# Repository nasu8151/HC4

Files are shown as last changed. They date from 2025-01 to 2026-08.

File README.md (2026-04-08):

¡¡¡ガバガバEnglish注意報発令中!!!

# Table of Contents
- [Table of Contents](#table-of-contents)
- [Descriptions](#descriptions)
- [Architecture](#architecture)
  - [Overview](#overview)
  - [Block diagram](#block-diagram)
  - [Instructions list](#instructions-list)
- [Software](#software)
- [List of files and folders](#list-of-files-and-folders)

# Descriptions

A 4- or 8-bit CPU made with 74-series logic ICs.

# Manuals

- Hardware manual (JP): [UsersManual_Hardware.md](./UsersManual_Hardware.md)
- Software manual (EN): [UsersManual_Software.md](./UsersManual_Software.md)
- Software manual (JP): [UsersManual_Software_JP.md](./UsersManual_Software_JP.md)

Document roles:

- Hardware manual (JP): block-level architecture, buses, control signals, model differences.
- Software manual (EN/JP): instruction set reference, programming caveats, and LED blink tutorial.

# Architecture
## Overview

HC4 has an 8-bit wide address bus and a 4-bit wide data bus.
All of instructions are 8-bit wide.

## Block diagram

Block diagram of this CPU.

## Instructions list

Please refer to [here](https://github.com/nasu8151/HC4/blob/main/UsersManual_Software.md).

## Schematics and Boards

If you don't have [KiCAD](https://www.kicad.org/), you can use KiCanvas to see our schematics and boards.
* [HC4](https://kicanvas.org/?repo=https%3A%2F%2Fgithub.com%2Fnasu8151%2FHC4%2Ftree%2Fmain%2FHC4_KiCad)
* [HC4<sub>E</sub>](https://kicanvas.org/?repo=https%3A%2F%2Fgithub.com%2Fnasu8151%2FHC4%2Ftree%2Fmain%2FHC4_KiCad_EE)

# Software

## Assembler

The assembler for this CPU can be found [here](https://github.com/nasu8151/hcxasm).
Please see the documents for syntax and other details.

## HC4eROMandRAM

This is a ROM/RAM emulator for HC4<sub>E</sub>.

# List of files and folders

<pre>
.
├─extra
├─HC4eROMandRAM
│  └─inst
├─hc4_asm
│  └─src
│      └─debug_data
├─HC4_KiCad
│  ├─HC4_gbr
│  ├─Library.pretty
│  └─sim
├─HC4_KiCad_EE
│  ├─HC4_KiCad_EE-backups
│  ├─Library.pretty
│  └─production
├─HC_MemoryBoard
│  ├─production
│  └─ThroughHole.pretty
└─verilog
    ├─HC4
    ├─HC4e
    └─HC8
</pre>

* [README.md](https://github.com/nasu8151/HC4) : This file.
* [UsersManual_Software.md](https://github.com/nasu8151/HC4/blob/main/UsersManual_Software.md) : Instruction manual.
* [hc4_asm/](https://github.com/nasu8151/HC4/blob/main/hc4_asm) : [DEPRECATED] : [Use new assembler](https://github.com/nasu8151/hcxasm). An assembler for the HC4 CPU.
* [HC4_KiCad](https://github.com/nasu8151/HC4/blob/main/HC4_KiCad) : Schematics and a board of the HC4.
* [HC4_KiCad_EE](https://github.com/nasu8151/HC4/blob/main/HC4_KiCad_EE) : Schematics and a board of the HC4<sub>E</sub> (Used to be called "HC4 Education Edition").
* [HC_MemoryBoard](https://github.com/nasu8151/HC4/blob/main/HC4_KiCad_EE) : A schematic and a board for SRAM and I/O.
* verilog/
  * [verilog/HC4](https://github.com/nasu8151/HC4/blob/main/verilog/HC4) : Verilog simulation files of the HC4 CPU.
  * [verilog/HC8](https://github.com/nasu8151/blob/main/HC4/verilog/HC8) : Verilog simulation files of the HC8 CPU.
  * [verilog/HC4e](https://github.com/nasu8151/blob/main/HC4/verilog/HC8) : Verilog simulation files of the HC4e CPU.

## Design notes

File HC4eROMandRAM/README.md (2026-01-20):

# HC4eROMandRAM

これは、HC4<sub>E</sub>ボード用のROM/RAMを担当するプログラムです。
開発には、[PlatformIO](https://platformio.org/)を推奨しますが、書き込みはArduino IDEでも可能です。

## 書き込み方法(PlatformIO)

まず、VSCodeをダウンロードしてインストールしてください。そして、拡張機能の[PlatformIO](https://platformio.org/)を導入してください。\
つづいて、[HC4eROMandRAM.code-workspace](HC4eROMandRAM.code-workspace)を開き、ワークスペースに入ります。

### SerialUPDIの場合

SerialUPDIライタの作り方は、[この辺](https://nemuisan.blog.bai.ne.jp/?eid=239957)や[ここ](https://github.com/SpenceKonde/AVR-Guidance/blob/master/UPDI/jtag2updi.md)を参照してください。

## 書き込み方法(Arduino IDE)

まず、Arduino IDEをダウンロードし、インストールします。そして、[HC4eROMandRAM.ino](HC4eROMandRAM.ino)を開き、ツールバーからFile->Preferencies...(ファイル->基本設定)を開きます。\
そこにある、Additional Board Manager URLs(追加のボードマネージャーURL)を開き、```https://mcudude.github.io/MegaCoreX/package_MCUdude_MegaCoreX_index.json```を追加してください。\
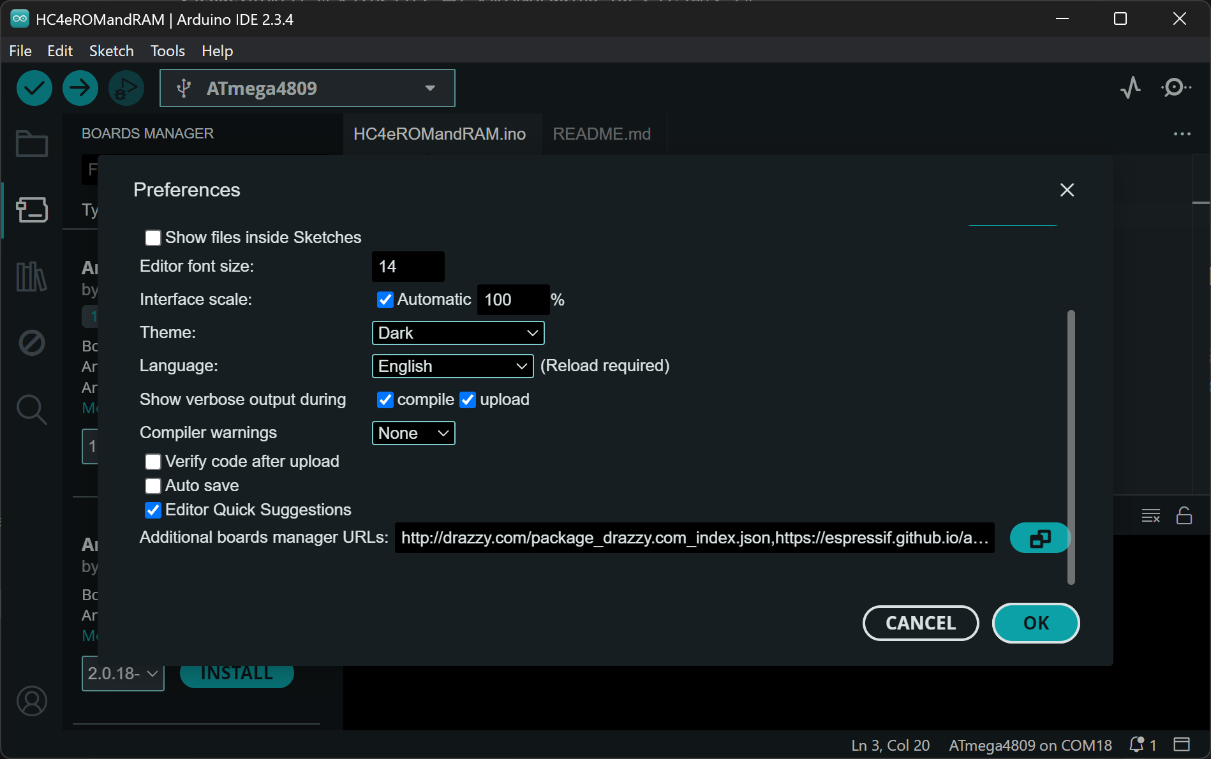
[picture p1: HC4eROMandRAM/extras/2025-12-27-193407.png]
Additional Board Manager URLs

すると、サイドバーのボードマネージャーから```MegaCoreX```が落とせるようになるので、検索してインストールしてください。

### SerialUPDIの場合

SerialUPDIライタの作り方は、[この辺](https://nemuisan.blog.bai.ne.jp/?eid=239957)や[ここ](https://github.com/SpenceKonde/AVR-Guidance/blob/master/UPDI/jtag2updi.md)を参照してください。\

SerialUPDIライタをパソコンにつなぎ、またUPDI端子とGND、必要に応じて電源をHC4<sub>E</sub>ボードにつなぎます。\
つづいて、Arduino IDEのTools下の設定を以下のように変更してください。\
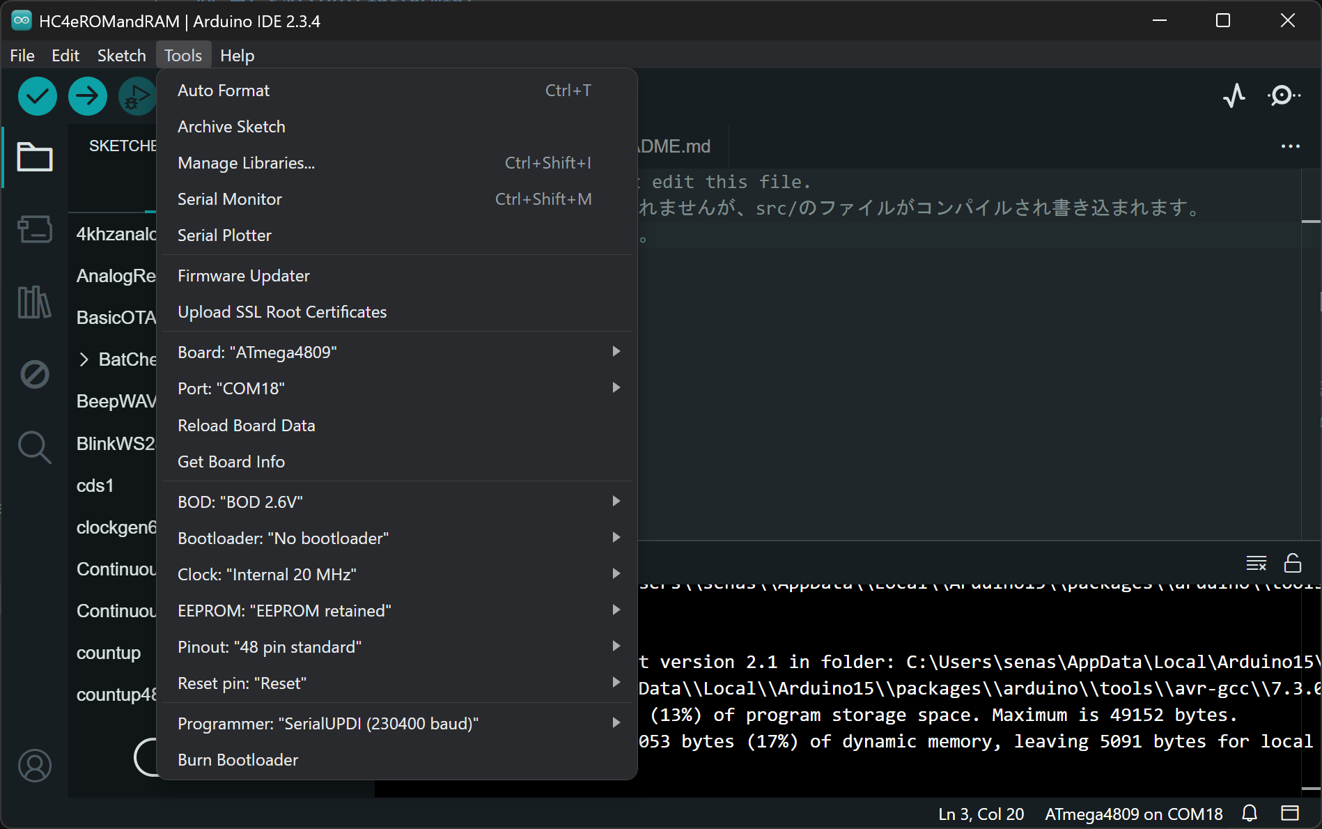
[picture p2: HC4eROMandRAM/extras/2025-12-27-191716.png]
\
COMポートは適宜読み替えてください。\
そうしたら、普通の書き込みボタンではなく、Sketch->Upload Using Programmerを押すか、Ctrl+Shift+Uを押して書き込んでください。

### jtag2updiの場合

まず、jtag2updiスケッチの書き込まれたArduino(Uno R3/Nano)を用意し、[公式リポジトリ](https://github.com/ElTangas/jtag2updi)や[この辺](https://burariweb.info/electronic-work/arduino-updi-writing-method.html)を参考にHC4<sub>E</sub>ボードとつなぎます。\
つづいて、Arduino IDEのTools下の設定を以下のように変更してください。\
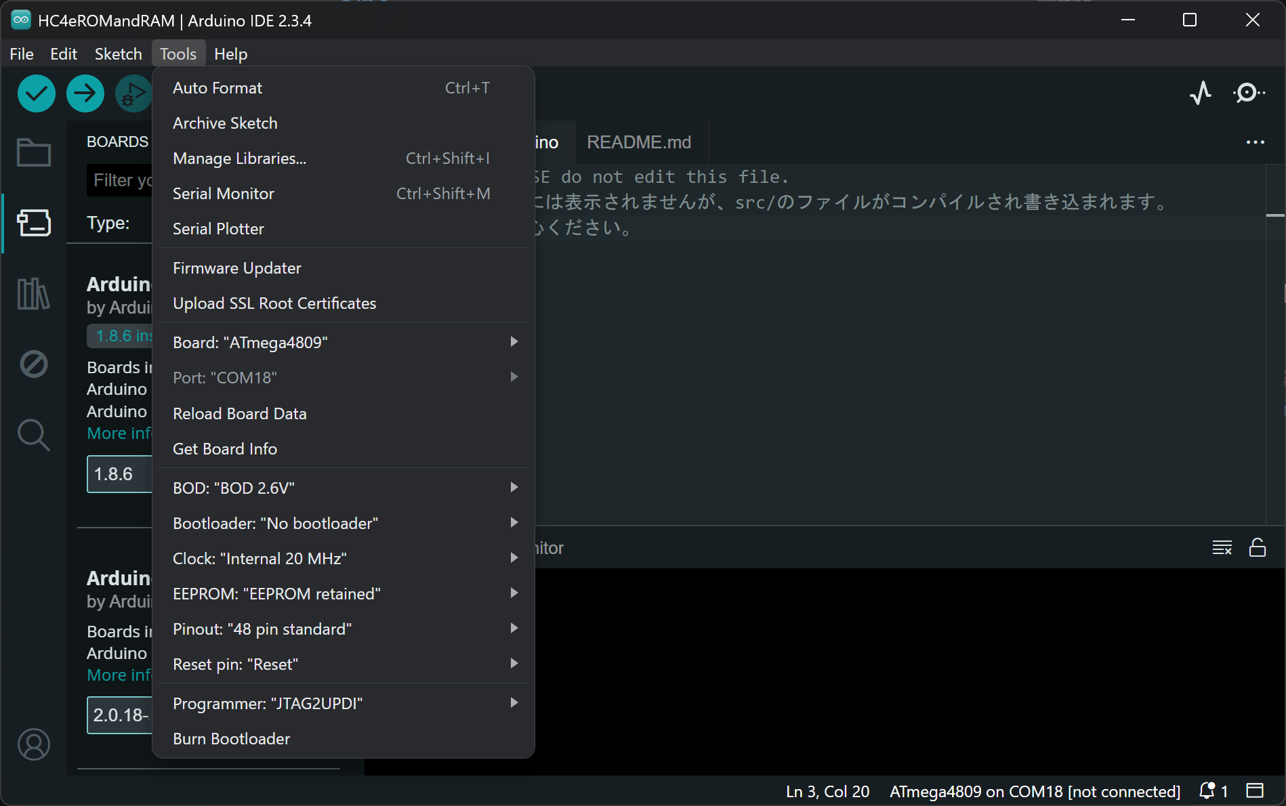
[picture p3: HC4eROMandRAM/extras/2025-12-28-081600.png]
\
そうしたら、普通の書き込みボタンではなく、Sketch->Upload Using Programmerを押すか、Ctrl+Shift+Uを押して書き込んでください。

## 動作確認

[Tera Term](https://teratermproject.github.io/)などのターミナルソフトを使用します。ここでは、Tera Termを使用しているものとします。\
Tera Termを開くと、接続先を選ぶ画面が出ます。そこの、シリアルにチェックを入れ、UPDIライタではなく、**HC4<sub>E</sub>のシリアルアダプタ**を選んでください。もしわからなければ、UPDIライタを外してみてください。\
設定->シリアルポートを選び、スピードを```115200```に設定します。つづいて、設定->端末を選び改行コードを送信、受信ともに```LF```に設定してください。\
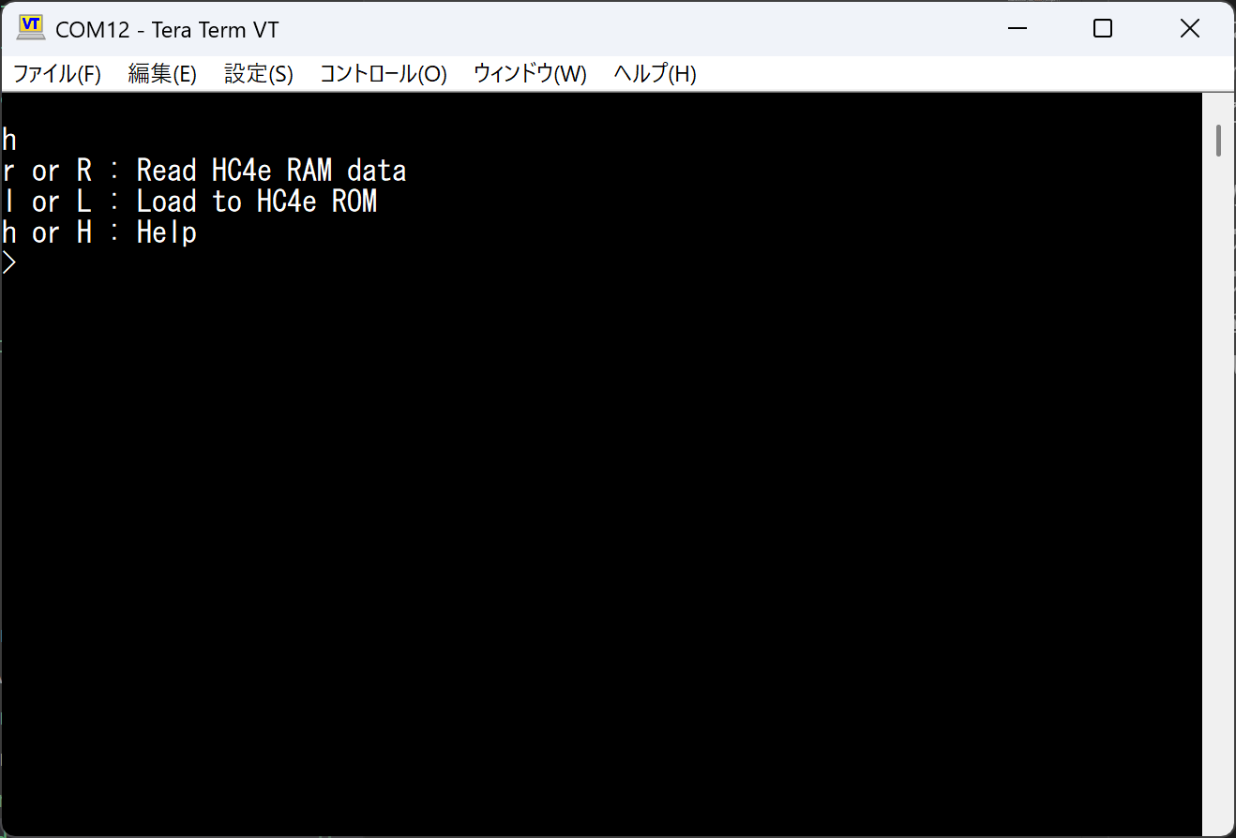
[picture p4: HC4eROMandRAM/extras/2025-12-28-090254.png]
help command
黒い画面で```h```をタイプし改行すると、以下の表示が出れば成功です。
つづいて```l```をタイプし改行したのちプログラムのintel hexのデータを右クリックか```Alt+V```で貼り付けて、そのプログラムが正しく動けば、完全に成功しています。
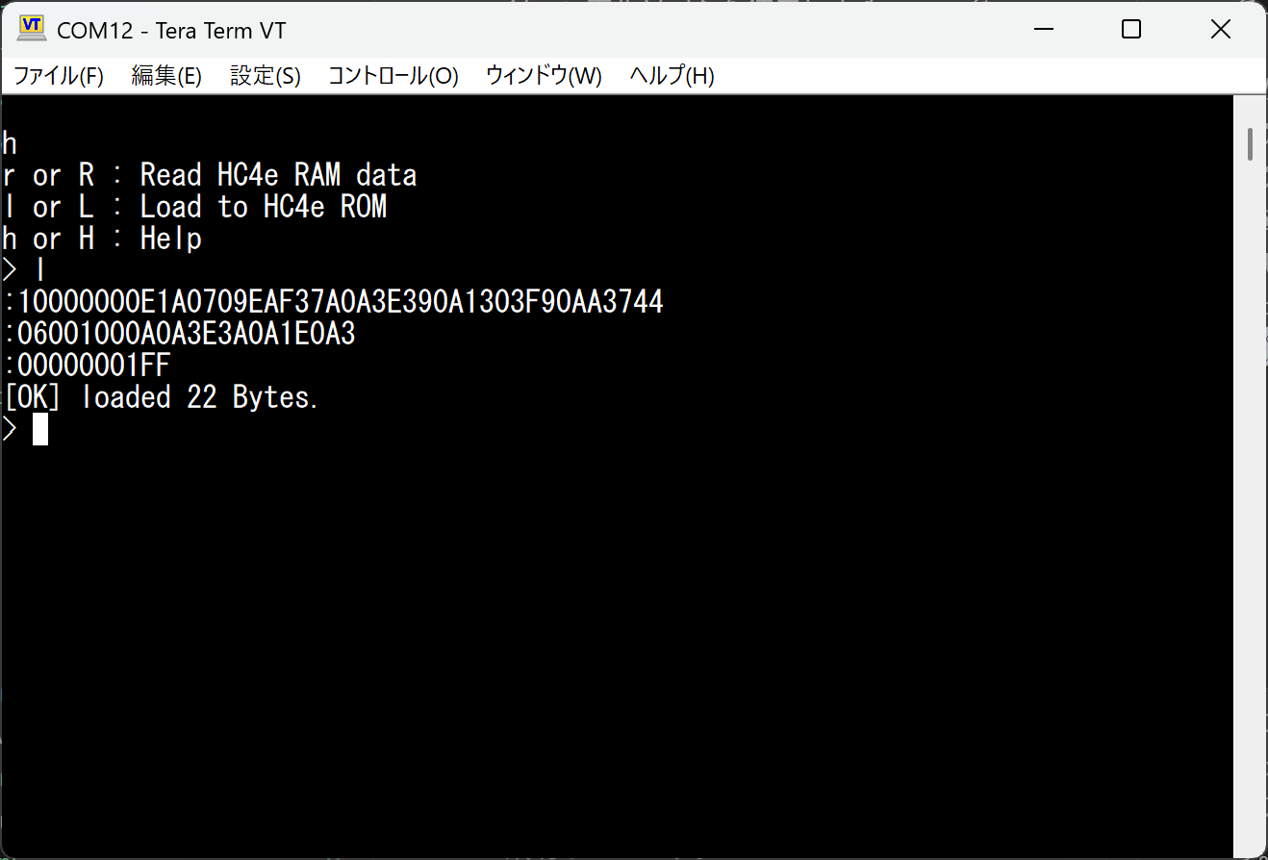
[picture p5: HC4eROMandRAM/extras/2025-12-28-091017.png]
succeed


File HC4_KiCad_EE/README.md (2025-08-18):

Schematics and board of HC4<sub>E</sub> (E means "for Education").

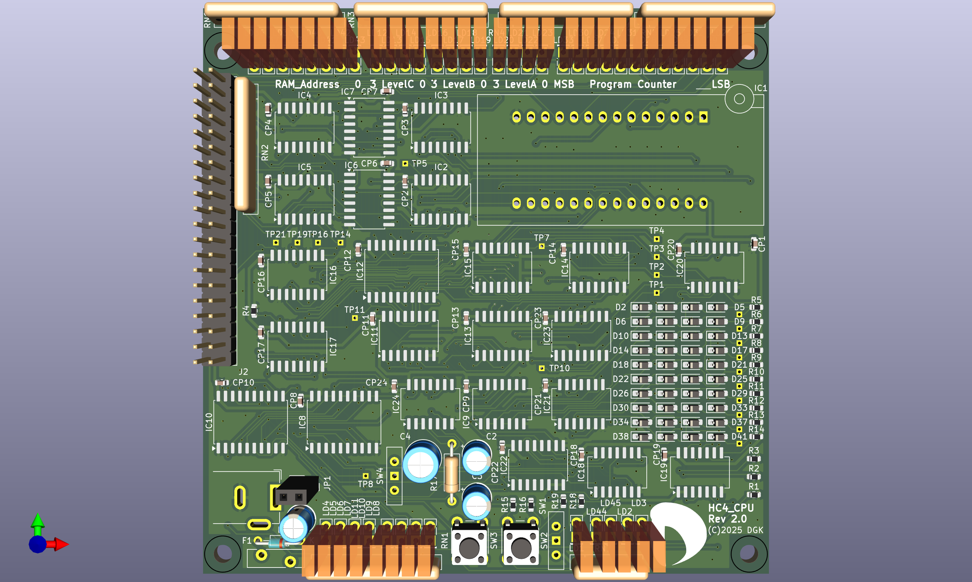
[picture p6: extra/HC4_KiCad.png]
Picture of the Board


BOM:
[Bill of materials](https://github.com/nasu8151/HC4/blob/main/HC4_KiCad/BOM_HC4.md)

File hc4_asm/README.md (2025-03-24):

# HC4 ASSEMBLER
## Syntax
> [!NOTE]
> IF you want to know function about assembly, please read [UsersManual_Software.md](https://github.com/nasu8151/HC4/blob/main/UsersManual_Software.md).

### Basic syntax
Let's get right to the explanation, but first, we tell you one.
On HC4 assembler, comments are represented by `;`. characters on the line after `;` are ignored during assembly.
```assembly
<Instruction>
<Instruction> <reg> ;reg means a 4-bit wide register. In the program, it is represented by r0 to r15 in program.
<Instruction> <imm> ;imm means 4 bits wide immediate data. In a program, it is represented as binary from #0000 to #1111.
<Instruction> <flg> ;flg means flag register.

;Addressing option is represented [AB] for SC or [ABC] for JP.
;[AB] means indirect addressing of stack level A and B. MSB is level B.
;[ABC] means indirect addressing of stack level A, B and C. MSB is level C.
<Instruction> <adr>       ; for load and store instructions
<Instruction> <flg> <adr> ; for jump instructions
```

### Pseudo-instruction

Currently not implemented.

## Command line options

* ```-o``` :
  * Specifies output file.

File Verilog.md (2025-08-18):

> [!IMPORTANT]
> The English version was EXCALIBURED. Wait until it has been repaired.
# 本編
## 🎯 HC4 CPU Verilog 解説

## 📚 1. 概要
* `hc4` モジュールは、4ビットスタックベースの簡易 CPU（HC4）のトップモジュールです。
* 以下に、部分ごとに分解して詳細に説明します。

---

## 📡 2. モジュール宣言と入出力

```verilog
module hc4 (
    input wire clk,                     // クロック信号
    input wire nReset,                  // 非同期リセット（0でリセット、1で通常動作）
    output wire [11:0] pc_out,          // プログラムカウンタの出力
    output wire [3:0] stackA_out,       // スタックレベルAの出力
    output wire [3:0] stackB_out,       // スタックレベルBの出力
    output wire [3:0] stackC_out,       // スタックレベルCの出力
    output wire [7:0] address_bus,      // アドレスバスの出力
    inout  wire [3:0] data_bus,         // データバス（入出力）
    output wire nRAM_RD,                // RAM 読み出し制御（アクティブ Low）
    output wire nRAM_WR                 // RAM 書き込み制御（アクティブ Low）
);
```

### ✅ ポイント
* `clk`：クロック信号
* `nReset`：リセット信号（アクティブ Low）  
    * 0 でリセット状態、1 で通常動作。
* `pc_out`：プログラムカウンタ（PC）の出力。
* `stackA_out`, `stackB_out`, `stackC_out`：スタックの各レベルの値を外部に出力。
* `address_bus`：メモリアドレスの出力（8ビット）。
* `data_bus`：4ビット幅のデータバス、読み書き両方に対応（inout）。
* `nRAM_RD`：RAM 読み出し制御信号（Low でアクティブ）。
* `nRAM_WR`：RAM 書き込み制御信号（Low でアクティブ）。

---

## 📝 3. レジスタとメモリの定義

```verilog
    reg [3:0] level_A;     // スタック レベル A
    reg [3:0] level_B;     // スタック レベル B
    reg [3:0] level_C;     // スタック レベル C
    reg [11:0] pc;         // プログラムカウンタ（PC）

    reg [7:0] rom [0:4095]; // 8ビット幅の命令ROM、4096命令分
```

### ✅ ポイント
* `level_A` ～ `level_C`：スタックレジスタ。
* `pc`：プログラムカウンタ（命令フェッチ用）。
* `rom`：命令を格納するメモリ（プログラムROM）。
* `$readmemh("./jmptest.hex", rom);` でROMに `jmptest.hex` からデータを読み込む。

---

## 🔢 4. 命令と制御信号の定義

```verilog
    wire [7:0] instruction;         // 現在の命令
    wire sub;                       // ALU の減算/加算制御信号
    wire [3:0] alu_result;          // ALU の出力結果
    wire carry;                     // キャリーフラグ
    reg  carry_flg;                 // キャリーフラグ保持
    reg  zero_flg;                  // ゼロフラグ保持
```

### ✅ ポイント
* `instruction`：現在の命令
* `sub`：ALU が減算モードか加算モードかを指定（1 なら減算、0 なら加算）。
* `alu_result`：ALU からの結果。
* `carry`：ALU のキャリーフラグ（繰り上がりや借り）。
* `carry_flg`：キャリーフラグの保持用レジスタ。
* `zero_flg`：ゼロフラグの保持用レジスタ。

---

## 📡 5. 命令読み込み・PC出力

```verilog
    assign instruction = rom[pc];
    assign pc_out = pc;
    assign stackA_out = level_A;
    assign stackB_out = level_B;
    assign stackC_out = level_C;
```

### ✅ ポイント
* `instruction`：プログラムカウンタ `pc` の位置から命令を読み込み。
* `pc_out`：プログラムカウンタを外部に出力。
* `stackA_out`, `stackB_out`, `stackC_out`：各スタックレベルの値を外部に出力。

---

## 🛠️ 6. ALU インスタンス化

```verilog
    alu ALU (
        .in_A (level_A),
        .in_B (level_B),
        .sel_in (instruction[6:4]),
        .carry_in (sub),
        .out (alu_result),
        .carry_out (carry)
    );
```

### ✅ ポイント
* `ALU` モジュールのインスタンス化。
* `in_A` と `in_B` にスタックレベル A, B を入力。
* `sel_in` に命令の `opcode` を入力。
* `carry_in` に `sub` 信号を入力。
* `alu_result` に演算結果を出力。
* `carry` にキャリーフラグを出力。

---

## 🧠 7. アドレスマルチプレクサ（ADDRESS_MUX）

```verilog
    function [7:0] ADDRESS_MUX(input [7:0] instruction, input [3:0] level_A, input [3:0] level_B);
        if (instruction[6:4] == 3'b000) begin  // if addressing mode is [AB]
            ADDRESS_MUX[3:0] = level_A;
            ADDRESS_MUX[7:4] = level_B;
        end else begin                         // if addressing mode is not [AB] (r, i)
            ADDRESS_MUX[7:4] = 4'h0;
            ADDRESS_MUX[3:0] = instruction[3:0];
        end
    endfunction
    assign address_bus = ADDRESS_MUX(instruction[7:0], level_A, level_B);
```

### ✅ ポイント
* `ADDRESS_MUX`：アドレスの選択
    * アドレッシングモード `[AB]` の場合：`level_A` と `level_B` からアドレス生成。
    * 即値やレジスタの場合：`instruction[3:0]` をアドレスの下位4ビットに設定。

---

## 🔁 8. プログラムカウンタ更新（NEXT_PC）

```verilog
    function [11:0] NEXT_PC(input [7:0] instruction, input [11:0] pc, input [3:0] level_A, input [3:0] level_B, input [3:0] level_C, input C_flag, input Z_flag);
        reg nJMP;
        if (instruction[7:5] == 3'b111) begin // if current instruction is Jump
            case (instruction[2:0])
                3'b000: NEXT_PC = {level_C, level_B, level_A};  // JP
                3'b001: NEXT_PC = pc + 1;                       // NP
                3'b010: begin                                  // JC
                    if (C_flag == 1) NEXT_PC = {level_C, level_B, level_A};
                    else             NEXT_PC = pc + 1;
                end
                3'b011: begin                                  // JNC
                    if (C_flag == 0) NEXT_PC = {level_C, level_B, level_A};
                    else             NEXT_PC = pc + 1;
                end
                3'b100: begin                                  // JZ
                    if (Z_flag == 1) NEXT_PC = {level_C, level_B, level_A};
                    else             NEXT_PC = pc + 1;
                end
                3'b101: begin                                  // JNZ
                    if (Z_flag == 0) NEXT_PC = {level_C, level_B, level_A};
                    else             NEXT_PC = pc + 1;
                end
                default:  NEXT_PC = pc + 1;
            endcase
        end else begin
            NEXT_PC = pc + 1;
        end
    endfunction
```

### ✅ ポイント
* `NEXT_PC`：ジャンプ命令の処理
    * `JP`：スタックの `CBA` からジャンプ。
    * `NP`：次の命令へ進む。
    * `JC`/`JNC`：キャリーフラグで条件付きジャンプ。
    * `JZ`/`JNZ`：ゼロフラグで条件付きジャンプ。
    * デフォルトは `pc + 1` で次の命令。

---

## 🔀 9. バス制御（BUS_CTRL）

```verilog
    function [3:0] BUS_CTRL (input [7:0] instruction, input [3:0] alu_result, input [3:0] level_C);
        casez (instruction[7:5])
            3'b000:  BUS_CTRL = level_C;          // SC
            3'b0??:  BUS_CTRL = alu_result;       // ALU instructions (include SA)
            3'b100:  BUS_CTRL = 4'bz;             // LD [AB] or LD r (RAM)
            3'b101:  BUS_CTRL = instruction[3:0]; // LD i
            default: BUS_CTRL = 4'bx;             // JP doesn't use data bus
        endcase
    endfunction
    assign data_bus = BUS_CTRL(instruction, alu_result, level_C);
```

### ✅ ポイント
* `BUS_CTRL`：バス制御
    * `SC`：`level_C` をデータバスに出力。
    * `ALU` 命令：`alu_result` をデータバスに出力。
    * `LD [AB]` / `LD r`：RAM からの読み込み → 高インピーダンス。
    * `LD i`：即値をバスに出力。

---

## 🔁 10. メイン処理（always ブロック）

```verilog
    always @(posedge clk or negedge nReset) begin
        if (nReset == 0) begin
            pc <= 12'b0;
            carry_flg <= 1'b0;
            zero_flg <= 1'b0;
            level_A <= 4'b0;
        end else begin
            casez (instruction[7:6])
                2'b0?: begin // if current instruction is an instruction which stores in the memory or registers
                    zero_flg  <= data_bus == 4'b0 ? 1 : 0;
                    carry_flg <= instruction[7:5] == 3'b001 ? carry : carry_flg;
                end 
                2'b10: begin
                    level_A <= data_bus;
                    level_B <= level_A;
                    level_C <= level_B;
                end
                2'b11: begin
                    // nothing to write here
                end
            endcase
            pc <= NEXT_PC(instruction, pc, level_A, level_B, level_C, carry_flg, zero_flg);
        end
    end
```

### ✅ ポイント
* `nReset == 0`：リセット時に初期化。
* 命令の `opcode` によって以下の動作
    * `0x`：メモリやレジスタに書き込み。
        * ゼロフラグ、キャリーフラグ更新。
    * `10`：スタックのシフト更新。
        * `level_A` → `level_B` → `level_C` へプッシュ。
    * `11`：ジャンプのみ、何も書き込みなし。

---

## 🎉 11. まとめ
* HC4 は 4 ビットスタックベースの CPU で、ジャンプ、スタック操作、ALU 演算などの基本的な命令を実行可能。
* Verilog での記述はモジュール化され、ALU、ROM 読み込み、バス制御などが含まれている。

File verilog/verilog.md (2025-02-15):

# Verilog Simulation
使い方がわかったので採用
## 記述ルール(仮)
* 負論理の信号は先頭に`n`をつける   
* 変数の語頭は必ず小文字

HC4/ is a 4-bit CPU.
HC8/ is an 8-bit CPU.

Commands to compile verilog simulation files:

```
cd ./verilog/hc4/
iverilog -o hc4_tb.out -s hc4_tb -g 2005-sv ./hc4.v ./hc4_tb.v
vvp ./hc4_tb.out
gtkwave ./hc4_tb.vcd
```

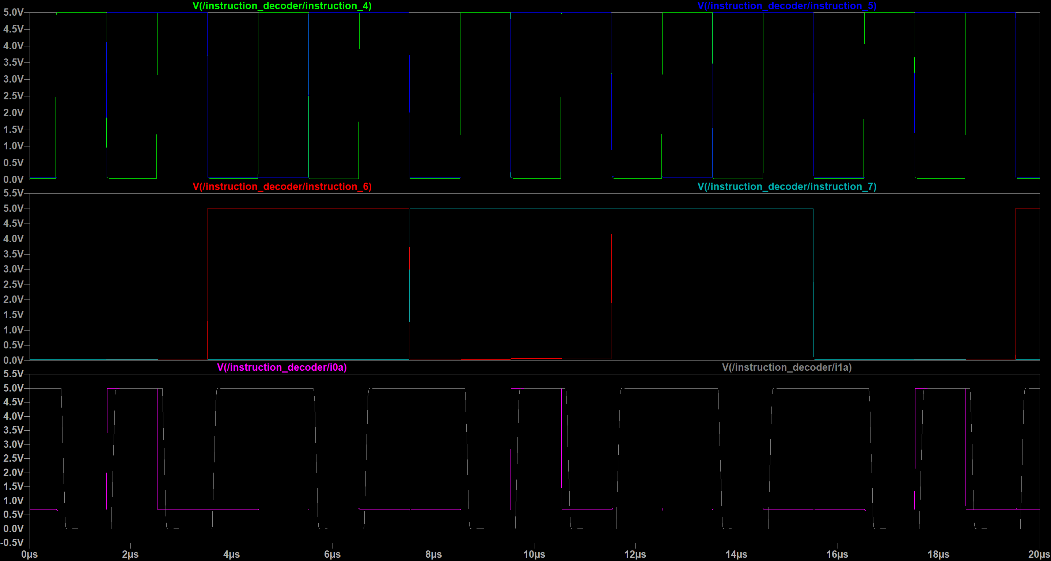
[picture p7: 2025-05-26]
extra/spice4.png

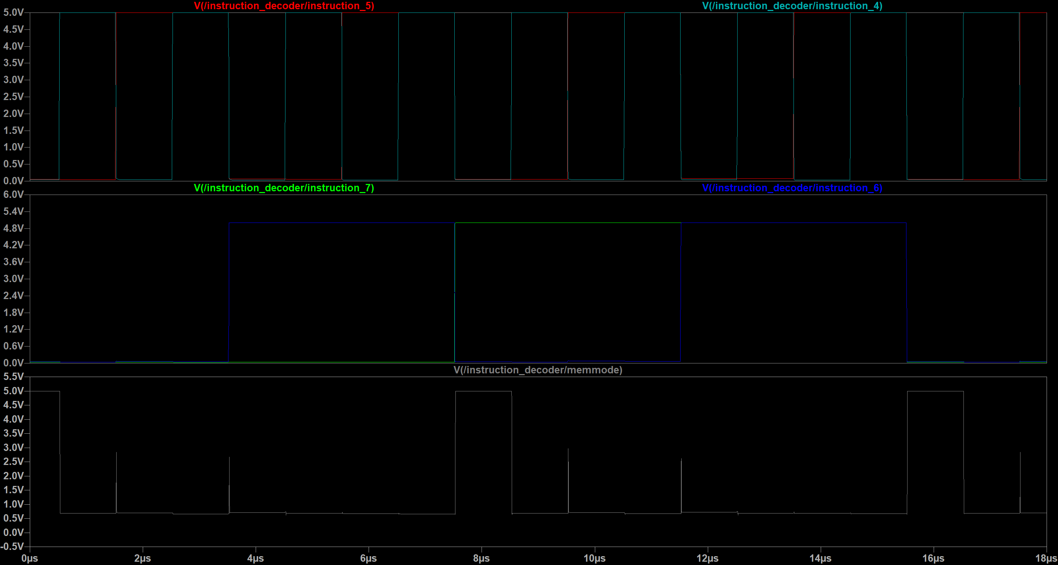
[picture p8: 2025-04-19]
extra/spice2.png

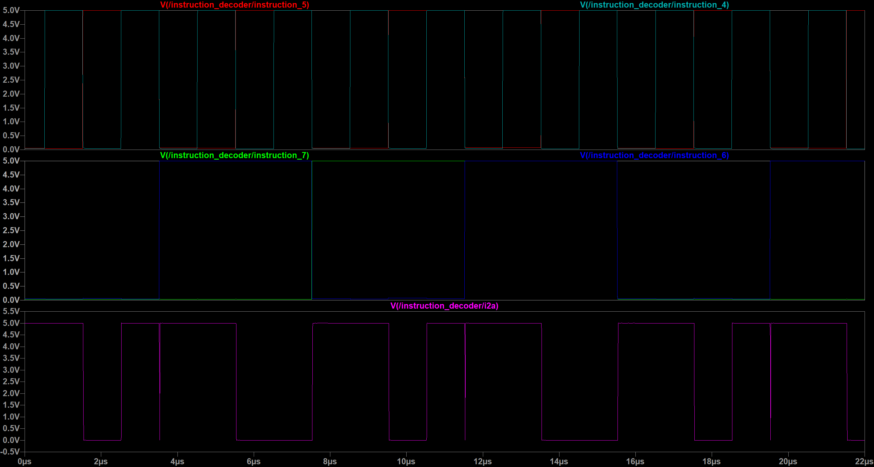
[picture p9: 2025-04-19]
extra/spice5.png

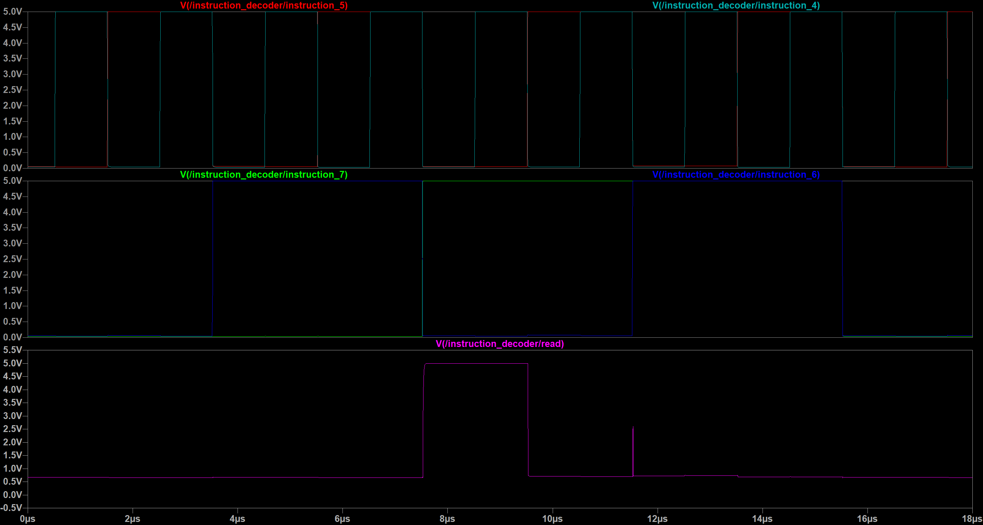
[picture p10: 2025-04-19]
extra/spice7.png

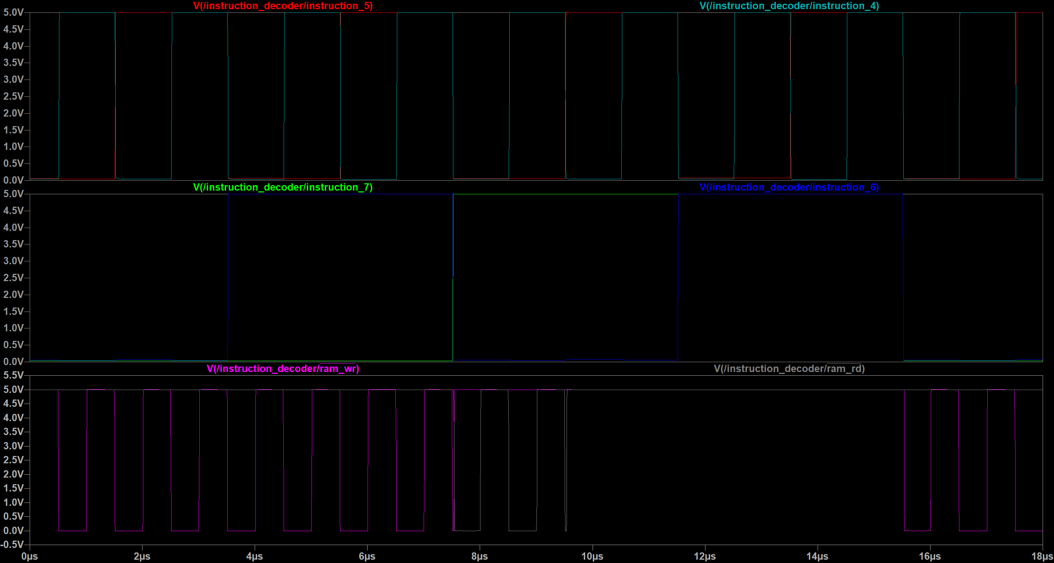
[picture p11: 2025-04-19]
extra/spice8.png

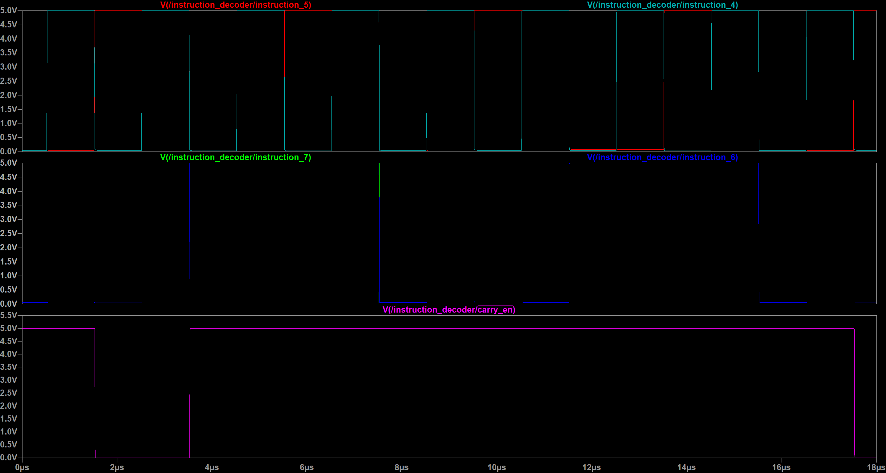
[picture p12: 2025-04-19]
extra/spice3.png

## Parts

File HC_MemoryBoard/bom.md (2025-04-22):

# Bill of Materials

| Reference | Value | Qty |
| --- | --- | --- |
| CP1-CP5 | Ceramic Capacitor: 0.1u  | 5 |
| IC1 | SRAM: 62256 or equipment | 1 |
| IC2 | 74HC30 | 1 |
| IC3 | 74HC138 | 1 |
| IC4 | 74HC32 | 1 |
| IC5 | 74HC541 | 1 |
| J1,J4 | Pinheader: 2x20 | 2 |
| J2,J6,J7,JP2 | Pinheader: 1x02 | 4 |
| J3,J5 | Pinheader: 01x08_Pin | 2 |
| JP1 | Pinheader: 02x17 | 1 |
| RN1 | R_Array 10k SIP9 | 1 |
| SW1 | SW_DIP_x08 | 1 |
| TP1 | PinHeader_1x01 | 1 |

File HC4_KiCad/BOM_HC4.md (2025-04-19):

| Reference | Value | Qty | Remarks |
| --- | --- | --- | --- |
| C1 | 100u | 1 | |
| C2,C3 | 10u | 2 | |
| C4 | 10u(Socket) | 1 | Unipolar |
| CP1-CP24 | 0.1u | 24  | 1608 |
| D1 | 5.6V | 1 | |
| D2-D41 | D | 40  | SOD-323 Package |
| F1 | Polyfuse | 1 | |
| IC1 | ROM | 1 | ZIF Socket |
| IC2,IC3,IC4,IC5 | 74HC153 | 4 | Use SOP type |
| IC6 | 74HC283 | 1 | Use SOP type |
| IC7,IC16,IC17 | 74HC257 | 3 | Use SOP type |
| IC8 | 74HC244 | 1 | Use SOP type |
| IC9 | 74HC4002 | 1 | Use SOP type |
| IC10 | 74HC374 | 1 | Use SOP type |
| IC11,IC13,IC14,IC15 | 74HC161 | 4 | Use SOP type |
| IC12 | 74HC377 | 1 | Use SOP type |
| IC18 | 74HC74 | 1 | Use SOP type |
| IC19 | 74HC32 | 1 | Use SOP type |
| IC20 | 74HC04 | 1 | Use SOP type |
| IC21 | 74HC00 | 1 | Use SOP type |
| IC22 | 74HC4053 | 1 | Use SOP type |
| IC23 | 74HC151 | 1 | Use SOP type |
| IC24 | 74HC14 | 1 | Use SOP type |
| J1 | Power | 1 | DC Jack |
| J2 | Expantion_Connector | 1 | 2x20pin |
| JP1 | Blink_EN | 1 | Use slide swich or jumper pin |
| LD1 | POWER_LED | 1 | LED |
| LD2-LD45 | LED | 44  | 2x5mm Rectanglar |
| R1,R2,R3 | 1k | 3 | 1608 |
| R4-R15 | 10k | 12  | 1608 |
| R16 | 100k | 1 | 1608 |
| R17 | Socket | 1 | |
| R18,R19 | 100 | 2 | 1608 |
| RN1,RN3,RN4,RN5,RN6 | 1k | 5 | SIP8 |
| RN2 | 10k | 1 | SIP8 |
| RN7 | 1k | 1 | SIP5 |
| SW1 | Bus_Open | 1 | Use slide swich or jumper pin |
| SW2,SW3 | SW_Push | 2 | |
| SW4 | SW_SPDT | 1 | Use slide swich or jumper pin |

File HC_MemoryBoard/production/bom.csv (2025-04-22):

Designator | Footprint | Quantity | Value | LCSC Part #
CP1, CP2, CP3, CP4, CP5 | C_Disc_D3.0mm_W1.6mm_P2.50mm | 5 | 0.1u
IC1 | DIP-28_W15.24mm | 1 | HM62256BLP
IC2 | DIP-14_W7.62mm | 1 | 74HC30
IC3 | DIP-16_W7.62mm | 1 | 74HC138
IC4 | DIP-14_W7.62mm | 1 | 74HC32
IC5 | DIP-20_W7.62mm | 1 | 74HC541
J1, J4 | PinHeader_2x20_P2.54mm_Vertical | 2 | Expantion_Connector
J2, J6, J7 | PinHeader_1x02_P2.54mm_Vertical | 3 | Conn_01x02_Pin
J3, J5 | PinHeader_1x08_P2.54mm_Vertical | 2 | Conn_01x08_Pin
JP1 | PinHeader_2x17_P2.54mm_Vertical | 1 | Conn_02x17_Counter_Clockwise
JP2 | PinHeader_1x02_P2.54mm_Vertical | 1 | Jumper_2_Bridged
RN1 | R_Array_SIP9 | 1 | 10k
SW1 | SW_DIP_SPSTx08_Slide_9.78x22.5mm_W7.62mm_P2.54mm | 1 | SW_DIP_x08
TP1 | PinHeader_1x01_P2.54mm_Vertical | 1 | ~{IRQ}

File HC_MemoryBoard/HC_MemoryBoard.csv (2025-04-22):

Reference | Value | Footprint | Datasheet | Qty | DNP | Exclude from BOM | Exclude from Board
CP1,CP2,CP3,CP4,CP5 | 0.1u | Capacitor_THT:C_Disc_D3.0mm_W1.6mm_P2.50mm | ~ | 5
IC1 | HM62256BLP | Package_DIP:DIP-28_W15.24mm | https://web.mit.edu/6.115/www/document/62256.pdf | 1
IC2 | 74HC30 | Package_DIP:DIP-14_W7.62mm | https://www.ti.com/lit/ds/symlink/cd74hc30.pdf?ts=1704693560763 | 1
IC3 | 74HC138 | Package_DIP:DIP-16_W7.62mm | http://www.ti.com/lit/ds/symlink/cd74hc238.pdf | 1
IC4 | 74HC32 | Package_DIP:DIP-14_W7.62mm | http://www.ti.com/lit/gpn/sn74LS32 | 1
IC5 | 74HC541 | Package_DIP:DIP-20_W7.62mm | https://toshiba.semicon-storage.com/info/TC74HC541AP_datasheet_ja_20140301.pdf?did=16392&prodName=TC74HC541AP | 1
J1,J4 | Expantion_Connector | Connector_PinHeader_2.54mm:PinHeader_2x20_P2.54mm_Vertical | ~ | 2
J2,J6,J7 | Conn_01x02_Pin | Connector_PinHeader_2.54mm:PinHeader_1x02_P2.54mm_Vertical | ~ | 3
J3,J5 | Conn_01x08_Pin | Connector_PinHeader_2.54mm:PinHeader_1x08_P2.54mm_Vertical | ~ | 2
JP1 | Conn_02x17_Counter_Clockwise | Connector_PinHeader_2.54mm:PinHeader_2x17_P2.54mm_Vertical | ~ | 1
JP2 | Jumper_2_Bridged | Connector_PinHeader_2.54mm:PinHeader_1x02_P2.54mm_Vertical | ~ | 1
RN1 | 10k | Resistor_THT:R_Array_SIP9 | http://www.vishay.com/docs/31509/csc.pdf | 1
SW1 | SW_DIP_x08 | Button_Switch_THT:SW_DIP_SPSTx08_Slide_9.78x22.5mm_W7.62mm_P2.54mm | ~ | 1
TP1 | ~{IRQ} | Connector_PinHeader_2.54mm:PinHeader_1x01_P2.54mm_Vertical | ~ | 1

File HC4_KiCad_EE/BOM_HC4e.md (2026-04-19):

| Reference | Value | Qty | Remarks |
|---|---|-----|---|
| C1 | 100u | 1 | |
| C2,C3,CP1-15 | 0.1u | 17  | SMT 1608 |
| C4,C5 | 10u | 2 | |
| C6 | 1u | 1 | Use unipolar type |
| D1 | 7-Segment | 1 | C-551SRD or equipment |
| D2 | Schottky | 1 | Switching diode in SOD-323 package |
| IC1,IC12 | 74HC00 | 2 | Use SOP package (D or *F) |
| IC2 | 74HC283 | 1 | Use SOP package (D or *F) |
| IC3,IC4 | 74HC253 | 2 | Use SOP package (D or *F) |
| IC5 | 74HC244 | 1 | Use TSSOP package (PW) |
| IC6,IC8 | 74HC377 | 2 | Use TSSOP package (PW) |
| IC7 | 74HC4511 | 1 | Use SOP package (D or *F) |
| IC9,IC10 | 74HC161 | 2 | Use SOP package (D or *F) |
| IC11 | 74HC02 | 1 | Use SOP package (D or *F) |
| IC13 | 74HC4053 | 1 | Use SOP package (D or *F) |
| IC14 | 74HC74 | 1 | Use SOP package (D or *F) |
| IC15 | 74HC14 | 1 | Use SOP package (D or *F) |
| J1,J2 | Port | 2 | Pinsocket_1x4 |
| J3 | UPDI_and_Debug | 1 | Pinheader_2x3 |
| J4 | Conn_02x04_Odd_Even | 1 | USB-UART |
| J5 | Expantion | 1 | Pinheader_2x5 |
| LD1-29 | LED | 29  | 2x5mm Rectangler |
| LD30-45 | Chip | 16  | SMT 1608 |
| LD46 | CLK | 1 | D5mm, Yellow |
| LD47 | RESET | 1 | D5mm, Red |
| R1 | 1k | 1 | SMT 1608 |
| R2 | 10k | 1 | SMT 1608 |
| R3 | 100k | 1 | SMT 1608 |
| R4 | 390k | 1 | SMT 1608 |
| R5 | 390 | 1 | SMT 1608 |
| R6,R7 | 100 | 2 | SMT 1608 |
| RN1 | 10k | 1 | Resistor array SMT 3216 |
| RN2-15 | 1k | 14  | Resistor array SMT 3216 |
| SW1 | SW_DIP_x04 | 1 | |
| SW2,SW3,SW4  | SW_Push | 3 | |
| SW5,SW6 | SW_SPDT | 2 | |
| U1 | ATmega4809-AU | 1 | or AVR32DB48 |

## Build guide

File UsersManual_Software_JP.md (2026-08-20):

# HC4 ユーザーズマニュアル ソフトウェア編

- [HC4 ユーザーズマニュアル ソフトウェア編](#hc4-ユーザーズマニュアル-ソフトウェア編)
  - [表の読み方](#表の読み方)
  - [命令テーブル](#命令テーブル)
    - [HC4](#hc4)
    - [HC4E](#hc4e)
    - [HC8](#hc8)
    - [総合](#総合)
  - [命令詳細](#命令詳細)
    - [論理演算・算術演算](#論理演算算術演算)
      - [`SU`](#su)
      - [`AD`](#ad)
      - [`XR`](#xr)
      - [`OR`](#or)
      - [`AN`](#an)
    - [レジスタ・メモリアクセス](#レジスタメモリアクセス)
      - [`SM`](#sm)
      - [`SC r`](#sc-r)
      - [`SA r`](#sa-r)
      - [`LM`](#lm)
      - [`LD`](#ld)
      - [`LI`](#li)
    - [システム制御](#システム制御)
      - [`JP`, `NP`](#jp-np)
  - [注意すべき点](#注意すべき点)
    - [HC4E の注意](#hc4e-の注意)
    - [SA r / SC r / SM](#sa-r--sc-r--sm)
    - [LD r / LI #i / LM](#ld-r--li-i--lm)
    - [JP 系 / NP](#jp-系--np)
  - [チュートリアル: LED点滅（lchika.asm）](#チュートリアル-led点滅lchikaasm)
  - [トラブルシューティング](#トラブルシューティング)

## 表の読み方

HC4シリーズの命令幅は 8 bit です。

- `r`: 4 bit レジスタ番号（`r0` から `r15`）
- `A`, `B`, `C`: スタックA/B/C
- `#i`: 4 bit 即値
- `[AB]`: スタック A/B を連結した間接アドレス（MSB は B）
- `[ABC]`: スタック A/B/C を連結した間接アドレス（MSB は C）
- `PC`: Program Counter

（Reserved）は未定義命令です。動作は保証されません。

## 命令テーブル

### HC4

| bit 5-4→<br>7-6↓ | 00 | 01 | 10 | 11 |
| --- | --- | --- | --- | --- |
| 00 | `SM` | `SC r` | `SU r` | `AD r` |
| 01 | `XR r` | `OR r` | `AN r` | `SA r` |
| 10 | `LM` | `LD r` | `LI #` | (Reserved) |
| 11 | (Reserved) | (Reserved) | `JP flag`, `NP` | (Reserved) |

### HC4E

| bit 5-4→<br>7-6↓ | 00 | 01 | 10 | 11 |
| --- | --- | --- | --- | --- |
| 00 | (Reserved) | (Reserved) | (Reserved) | `AD r` |
| 01 | `XR r` | (Reserved) | (Reserved) | `SA r` |
| 10 | (Reserved) | `LD r` | `LI #` | (Reserved) |
| 11 | (Reserved) | (Reserved) | `JP flag`, `NP` | (Reserved) |

### HC8

| bit 5-4→<br>7-6↓ | 00 | 01 | 10 | 11 |
| --- | --- | --- | --- | --- |
| 00 | `SM` | `SC r` | `SU r` | `AD r` |
| 01 | `XR r` | `OR r` | `AN r` | `SA r` |
| 10 | `LM` | `LD r` | `LI #` | (Reserved) |
| 11 | `LS #` | (Reserved) | `JP flag`, `NP` | `JL flag`, `LP` |

### 総合

| 命令 | Opc  | Opr  | フラグ変化 | 動作 | 説明 |
|---|---|---|---|---|---|
| `SU r` | 0010 | r | C, Z | r <= A-B  | 減算結果を r に格納 |
| `AD r` | 0011 | r | C, Z | r <= A+B  | 加算結果を r に格納 |
| `XR r` | 0100 | r | Z | r <= A^B  | XOR 結果を r に格納※1 |
| `XR r` | 0100 | r | Z | r <= ~(A&B)  | NAND 結果を r に格納※2 |
| `OR r` | 0101 | r | Z | r <= A\|B | OR 結果を r に格納 |
| `AN r` | 0110 | r | Z | r <= A&B  | AND 結果を r に格納 |
| `SM` | 0000 | 0000 | Z | | C を `[AB]` に格納 |
| `SC r` | 0001 | r | Z | | C を r に格納 |
| `SA r` | 0111 | r | Z | | A を r に格納 |
| `LM` | 1000 | 0000 | | | `[AB]` から A にロード |
| `LD r` | 1001 | r | | | r から A にロード |
| `LI #i`  | 1010 | i | | | 即値を A にロード |
| `LS #i`* | 1100 | i | | | 即値ロード + A シフト（HC8のみ） |
| `JP` | 1110 | 0000 | | | `[ABC]` へジャンプ |
| `JP C` | 1110 | 0010 | | | C フラグが 1 のときジャンプ |
| `JP NC`  | 1110 | 0011 | | | C フラグが 0 のときジャンプ |
| `JP Z` | 1110 | 0100 | | | Z フラグが 1 のときジャンプ |
| `JP NZ`  | 1110 | 0101 | | | Z フラグが 0 のときジャンプ |
| `NP` | 1110 | 0001 | | | 何もしない |

- ※1 HC4e以外
- ※2 HC4eのみ。ニーモニックは暫定。

## 命令詳細

### 論理演算・算術演算

| 命令 | Opc  | Opr | フラグ変化 | 動作 | 説明 |
| --- | ---- | --- | --- | --- | --- |
| `SU r` | 0010 | r | C, Z | r <= A-B | 減算結果を r に格納 |
| `AD r` | 0011 | r | C, Z | r <= A+B | 加算結果を r に格納 |
| `XR r` | 0100 | r | Z | r <= A^B | XOR 結果を r に格納※1  |
| `XR r` | 0100 | r | Z | r <= ~(A&B) | NAND 結果を r に格納※2 |
| `OR r` | 0101 | r | Z | r <= A\|B | OR 結果を r に格納 |
| `AN r` | 0110 | r | Z | r <= A&B | AND 結果を r に格納 |

これらの命令はスタック レベル`A`と`B`を入力に取り、演算結果を指定レジスタ r に格納します。

#### `SU`

| 命令 | Opc  | Opr | フラグ変化 | 動作 | 説明 |
| --- | ---- | --- | --- | --- | --- |
| `SU r` | 0010 | r | C, Z | r <= A-B | 減算結果を r に格納 |

例:

```asm
LI #3
; stack A B C
;       3 x x
LI #5
; stack A B C
;       5 3 x
SU r0
; r0(0x00) <= 2 (5-3)
```

- 副作用
  - フラグ
    - `C`フラグ:もし結果が正なら、`1`(負なら`0`)
    - `Z`フラグ:もし結果が0なら、`1`(0でないなら`0`)

#### `AD`

| 命令 | Opc  | Opr | フラグ変化 | 動作 | 説明 |
| --- | ---- | --- | --- | --- | --- |
| `AD r` | 0011 | r | C, Z | r <= A+B | 加算結果を r に格納 |

例:

```asm
LI #3
; stack A B C
;       3 x x
LI #5
; stack A B C
;       5 3 x
AD r0
; r0(0x00) <= 8 (5+3)
```

- 副作用
  - フラグ
    - `C`フラグ:結果が16以上なら、`1`(16未満なら`0`)
    - `Z`フラグ:もし結果が0なら、`1`(0でないなら`0`)

#### `XR`

HC4e以外

| 命令 | Opc  | Opr | フラグ変化 | 動作 | 説明 |
| --- | ---- | --- | --- | --- | --- |
| `XR r` | 0100 | r | C, Z | r <= A^B | XOR結果を r に格納 |

HC4e

| 命令 | Opc  | Opr | フラグ変化 | 動作 | 説明 |
| --- | ---- | --- | --- | --- | --- |
| `XR r` | 0100 | r | C, Z | r <= ~(A&B) | NAND結果を r に格納 |

命令名は暫定のものです。

例:

```asm
LI #0b0011
; stack A B C
;       3 x x
LI #0b0101
; stack A B C
;       5 3 x
XR r0
; r0(0x00) <= 0b0110 (0b0011 xor 0b0101)
```

- 副作用
  - フラグ
    - `C`フラグ:影響しません。
    - `Z`フラグ:もし結果が0なら、`1`(0でないなら`0`)

#### `OR`

| 命令 | Opc  | Opr | フラグ変化 | 動作 | 説明 |
| --- | ---- | --- | --- | --- | --- |
| `OR r` | 0101 | r | C, Z | r <= A|B | OR結果を r に格納 |

例:

```asm
LI #0b0011
; stack A B C
;       3 x x
LI #0b0101
; stack A B C
;       5 3 x
OR r0
; r0(0x00) <= 0b0111 (0b0011 or 0b0101)
```

- 副作用
  - フラグ
    - `C`フラグ:影響しません。
    - `Z`フラグ:もし結果が0なら、`1`(0でないなら`0`)

#### `AN`

| 命令 | Opc  | Opr | フラグ変化 | 動作 | 説明 |
| --- | ---- | --- | --- | --- | --- |
| `AN r` | 0110 | r | Z | r <= A&B | AND 結果を r に格納 |

例:

```asm
LI #0b0011
; stack A B C
;       3 x x
LI #0b0101
; stack A B C
;       5 3 x
AN r0
; r0(0x00) <= 0b0001 (0b0011 and 0b0101)
```

- 副作用
  - フラグ
    - `C`フラグ:影響しません。
    - `Z`フラグ:もし結果が0なら、`1`(0でないなら`0`)

### レジスタ・メモリアクセス

| 命令 | Opc  | Opr  | フラグ変化 | 説明 |
| --- | ---- | ---- | --- | --- |
| `SM` | 0000 | 0000 | Z | C を `[AB]` に格納 |
| `SC r` | 0001 | r | Z | C を r に格納 |
| `SA r` | 0111 | r | Z | A を r に格納 |
| `LM` | 1000 | 0000 | | `[AB]` から A にロード |
| `LD r` | 1001 | r | | r から A にロード |
| `LI #i`  | 1010 | i | | 即値を A にロード |
| `LS #i`* | 1100 | i | | 即値ロード + A シフト（HC8のみ） |

注記:

- `LS #i` は HC8 のみ。
- Store 系命令は A または C をレジスタ/メモリへ保存します。
  - `SA r`: A を参照
  - `SC r`, `SM`: C を参照
- Load 系命令は A に値を読み込みます。
  - ロード時は A/B/C が 1 段ずつ押し下がります（A <- new, B <- old A, C <- old B）。
  - `LD r`: レジスタ参照
  - `LI #i`: 即値参照
  - `LM`: `[AB]` で指定されたメモリアドレス参照
- `LS #i` と `LI #i` では 2進リテラル（例: `0b1010`）と 16進リテラル（例: `0xA`）を使用できます。

#### `SM`

| 命令 | Opc  | Opr  | フラグ変化 | 説明 |
| --- | ---- | ---- | --- | --- |
| `SM` | 0000 | 0000 | Z | C を `[AB]` に格納 |

スタック レベル`C`の値をスタック レベル`A`およびBであらわされるアドレスに格納します。アドレスのMSBはレベル`B`です。

例 :

```asm
LI #3
; stack A B C
;       3 x x
LI #0xF
; stack A B C
;       F 3 x
LI #0x0
; stack A B C
;       0 F 3
SM
; stores 3 to address 0xF0 
```

- 副作用
  - フラグ
    - `C`フラグ:影響しません。
    - `Z`フラグ:もし結果が0なら、`1`(0でないなら`0`)

#### `SC r`

| 命令 | Opc  | Opr  | フラグ変化 | 説明 |
| --- | ---- | ---- | --- | --- |
| `SC r` | 0001 | r | Z | C を r に格納 |

スタック レベル`C`の値をrであらわされるアドレスに格納します。

#### `SA r`

| 命令 | Opc  | Opr  | フラグ変化 | 説明 |
| --- | ---- | ---- | --- | --- |
| `SA r` | 0111 | r | Z | A を r に格納 |

スタック レベル`A`の値をrであらわされるアドレスに格納します。

例 :

```asm
LI #3
; stack A B C
;       3 x x
SA r3
; stores 3 to 0x03(r3)
```

- 副作用
  - フラグ
    - `C`フラグ:影響しません。
    - `Z`フラグ:もし結果が0なら、`1`(0でないなら`0`)

#### `LM`

| 命令 | Opc  | Opr  | フラグ変化 | 説明 |
| --- | ---- | ---- | --- | --- |
| `LM` | 1000 | 0000 | | `[AB]` から A にロード |

スタック レベル`A`およびBであらわされるアドレスから値を読み込み、スタック レベル`A`に格納します。また、もともとスタックにあった値は押し下がります。アドレスのMSBはレベル`B`です。

例 :

```asm
LI #0xF
; stack A B C
;       F x x
LI #0x0
; stack A B C
;       0 F x
LM
; Loads data from address 0xF0 
; stack   A    B C
;       [0xF0] 0 F
```

#### `LD`

| 命令 | Opc  | Opr  | フラグ変化 | 説明 |
| --- | ---- | ---- | --- | --- |
| `LD r` | 1001 | r | | r から A にロード |

`r`であらわされるアドレスの値から値を読み込み、スタック レベル`A`に格納します。また、もともとスタックにあった値は押し下がります。

例 :

```asm
LI #3
; stack A B C
;       3 x x
SA r3
; stores 3 to 0x03(r3)
LD r3
; loads data from 0x03(r3)
; stack A B C
;       3 3 x
```

#### `LI`

| 命令 | Opc  | Opr  | フラグ変化 | 説明 |
| --- | ---- | ---- | --- | --- |
| `LI #i`  | 1010 | i | ※ | 即値を A にロード |

命令中の`#i`であらわされる即値をスタック レベル`A`に格納します。また、もともとスタックにあった値は押し下がります。`#i`には10進数のほかに16進数、2進数リテラルが使用できます。

例 :

```asm
LI #0xF
; stack A B C
;       F x x
LI #0x0
; stack A B C
;       0 F x
```

### システム制御

#### `JP`, `NP`

| 命令 | Opc  | Opr  | 説明 |
| --- | ---- | ---- | --- |
| `JP` | 1110 | 0000 | `[ABC]` へジャンプ |
| `JP C`  | 1110 | 0010 | C フラグが 1 のとき`[ABC]` へジャンプ |
| `JP NC` | 1110 | 0011 | C フラグが 0 のとき`[ABC]` へジャンプ |
| `JP Z`  | 1110 | 0100 | Z フラグが 1 のとき`[ABC]` へジャンプ |
| `JP NZ` | 1110 | 0101 | Z フラグが 0 のとき`[ABC]` へジャンプ |
| `NP` | 1110 | 0001 | 何もしない |

- `NP` は何もしません。
- `JP` 系命令は条件に応じて PC を更新します。

- ジャンプする場合、PCにスタック レベル`A`,`B`,`C`であらわされる値を格納し、次の命令はスタック レベル`A`,`B`,`C`であらわされる値のものを読み込みます。MSBはレベル`C`です。
- ジャンプしない場合、PCは通常通りインクリメントされます。

例 :

```asm
LI #0x0
; stack A B C
;       0 x x
LI #0x1
; stack A B C
;       1 0 x
LI #0x4
; stack A B C
;       4 1 0
JP
; 0x014にジャンプ(次の命令は ROM:0x014 よりフェッチされます。)
```

## チュートリアル: LED点滅（lchika.asm）

対象ファイル: `extra/lchika.asm`

```asm
np
li #0xF
li #0xF
li #0
sm
li #0
li #0xF
li #0
sm
li #0
li #0
li #0x1
jp
```

流れ:

1. `li #0xF`, `li #0xF`, `li #0` で書き込み先アドレスと値をスタックに準備
2. `sm` でメモリマップドI/Oへ出力値を書き込む
3. 別の値を書き込んで LED ON/OFF を切り替える
4. 最後に `jp` で先頭に戻り、点滅を繰り返す

このサンプルは「ロード」「ストア」「ジャンプ」の最小構成で、最初に動かす確認用として使えます。

行単位の解説:

1. `np`: 初期NOP
2. `li #0xF`: アドレス上位側の準備
3. `li #0xF`: アドレス下位側の準備
4. `li #0`: 出力データ（例: OFF）
5. `sm`: I/Oへ書き込み
6. `li #0`: 次の遷移用データ準備
7. `li #0xF`: 同一I/O領域指定
8. `li #0`: 出力データ再設定
9. `sm`: I/Oへ再書き込み
10. `li #0`: ジャンプ先下位準備
11. `li #0`: ジャンプ先中位準備
12. `li #0x1`: ジャンプ先上位準備
13. `jp`: 先頭側へ戻る

注記:

- 実機で点滅しない場合は、I/Oデコード範囲と極性（アクティブHigh/Low）を最初に確認してください。

## トラブルシューティング

- I/O アドレスの割り当てが回路と一致しているか確認する
- `JP` の飛び先アドレス（スタック内容）が意図どおりか確認する
- フラグ条件ジャンプを使う場合、直前命令の C/Z 更新を確認する
- `LD`/`LI` 後のスタック押し下がりで、想定外の値が B/C に残っていないか確認する
- HC4E では 2段スタック前提のため、C段前提のコードを書いていないか確認する

## 既知のエラッタ

- HC4 Rev1
  - `Z`フラグが壊れている
    Zフラグの制御線が誤ったところにつながっているのが原因。  
    対処法:`Z`フラグを使用しない
    Rev2で修正済み
  - `C`フラグが`LI`命令で変更される  
    イミディエイトの制御線と`C`フラグの制御線が共有されていることが原因。  
    対処法:`C`フラグを使用する加算の場合、直前で`LI`命令を使わず、いったんレジスタにロードして`LD`命令を使用する。  
    Rev2で修正済み
  - レベルCのLSBとMSBが逆になっている  
    対処法: なし(出力のみを行う場合、データバスの結線を逆にすることで対処可能)  
    Rev2で修正済み
 
- HC4 Rev2  
  - `SU`, `XR`命令が使用できない  
    命令デコーダ部の結線ミスが原因。修正可能。  
    対処法: `SU`, `XR`命令を使用しない  
    Rev3で修正済み

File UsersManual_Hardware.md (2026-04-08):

# HC4シリーズ ユーザーマニュアル ハードウェア編

- [HC4シリーズ ユーザーマニュアル ハードウェア編](#hc4シリーズ-ユーザーマニュアル-ハードウェア編)
  - [1. この文書について](#1-この文書について)
  - [2. 全体像](#2-全体像)
  - [3. アーキテクチャ概要](#3-アーキテクチャ概要)
    - [3.1 データ幅](#31-データ幅)
    - [3.2 スタック構造](#32-スタック構造)
    - [3.3 クロックとリセット](#33-クロックとリセット)
  - [4. 内部ブロック詳細](#4-内部ブロック詳細)
    - [4.1 ALU](#41-alu)
    - [4.2 プログラムカウンタ（PC）](#42-プログラムカウンタpc)
    - [4.3 命令デコーダ](#43-命令デコーダ)
  - [5. バスとメモリ空間](#5-バスとメモリ空間)
    - [5.1 バス](#51-バス)
    - [5.2 メモリマップドI/O](#52-メモリマップドio)
    - [5.3 レジスタ領域](#53-レジスタ領域)
  - [6. 制御信号](#6-制御信号)
  - [7. モデル差分メモ](#7-モデル差分メモ)
  - [8. 回路図・基板データ](#8-回路図基板データ)

## 1. この文書について

本書は HC4 シリーズ（HC4, HC4E, HC8）のハードウェア構成を説明する文書です。
命令仕様やアセンブリ記法はソフトウェア編を参照してください。

## 2. 全体像

- 教育用途を主眼にしたシンプルな CPU
- スタックベース演算モデルを採用
- 74シリーズ汎用ロジックIC実装と Verilog 実装を想定
- 基本構成はハーバードアーキテクチャ

全体ブロック図:

Block diagram of HC4 series

## 3. アーキテクチャ概要

### 3.1 データ幅

- 命令幅: 8 bit
- データバス幅: 4 bit（HC8は8bit）
- アドレスバス幅: 8 bit（HC4<sub>E</sub>は4bit、HC8は8bit）

モデル別の設計メモ:

| モデル | 主な想定 | 備考 |
| --- | --- | --- |
| HC4 | 3段スタック（A/B/C）+ 広いPC | 標準モデル |
| HC4<sub>E</sub> | 2段スタック（A/B）, PC 8 bit | 教育用軽量構成 |
| HC8 | 命令拡張あり | LS, JL, LP などを使用 |

### 3.2 スタック構造

HC4 系列は演算オペランドとしてスタックレベルを使います。

- レベルA: 主オペランド / ロード先
- レベルB: 第2オペランド
- レベルC: 退避レベル（HC4E では制約あり）

ロード命令実行時は A <- 入力, B <- 旧A, C <- 旧B の順に押し込みます。

HC4E は有効スタック段数が 2 段（A/B）で、C段を使う前提の動作は制限されます。

### 3.3 クロックとリセット

- CLK 立ち上がりで命令実行の状態更新を行う構成を想定
- nRESET はアクティブLowの非同期リセットとして扱う実装が多い
- リセット解除直後のPC初期値は実装依存のため、シミュレーション時に明示確認する

## 4. 内部ブロック詳細

### 4.1 ALU

ALU は以下の演算を担当します。

- AND
- OR
- XOR
- 加算
- 減算

入力は主にスタック A/B、出力はデータバスへ接続されます。

命令とALUの対応（概略）:

| 命令 | 演算 | フラグ |
| ---- | --- | --- |
| AD r | A + B | C, Z 更新 |
| SU r | A - B | C, Z 更新 |
| XR r | A XOR B | Z 更新 |
| OR r | A OR B  | Z 更新 |
| AN r | A AND B | Z 更新 |

注記:
- フラグ更新条件は実装差が出やすいため、Verilogと74系実装の両方で波形確認することを推奨

### 4.2 プログラムカウンタ（PC）

- 命令アドレスを保持
- 通常は命令実行ごとにインクリメント
- ジャンプ命令時は指定アドレスへ遷移

実装メモ:

- HC4 では広いPC幅（12bit）をとる
- HC4E では 8bit
- ジャンプ先はスタックCを最上位としてB, Aと連結するため、```LI #```命令でジャンプ先をロードしておいてください

### 4.3 命令デコーダ

命令デコーダは命令ビット列から制御信号を生成し、ALU、スタック、メモリ制御を切り替えます。
詳細な真理値に近い情報は以下を参照:

- extra/instruction.md

命令デコーダの役割:

- ALU演算種別の選択
- スタックのロード有効化
- メモリアクセス種別（読出し/書込み）選択
- ジャンプ条件評価とPC更新経路選択

## 5. バスとメモリ空間

### 5.1 バス

- データバス: 4 bit
- アドレスバス: 8 bit

### 5.2 メモリマップドI/O

HC4 系列はメモリマップドI/Oを想定します。
I/O デバイスはアドレスバスとデータバスへ接続してください。

実装時の目安:

- HC4 では 0xF0-0xFF をI/O領域として割り当てる構成を推奨（レファレンス実装はそうなっている）
- ただし最終的なI/O配置はアドレスデコーダ設計に依存

### 5.3 レジスタ領域

HC4シリーズではRAMのアドレス0x00~0x0Fを1命令でアクセスする命令があります。
この領域はプログラム作成時に前提となるため、RAM/I/Oの割り当て時に衝突しないように設計してください。

最低限のメモリマップ例:

| 範囲 | 用途 | 備考 |
| --- | --- | --- |
| 0x00-0x0F | レジスタ相当領域 | r0-r15 に対応 |
| 0x10-0xEF | RAM/作業領域 | 実装依存 |
| 0xF0-0xFF | I/O領域（例） | 実装で変更可 |

## 6. 制御信号

実装で最低限確認すべき信号:

- nRAM_RD: RAM 読み出し制御（アクティブLow）
- nRAM_WR: RAM 書き込み制御（アクティブLow）
- DATA_BUS[3:0]
- ADDRESS_BUS[7:0]
- CLK
- nRESET

内部制御線（ALU選択、スタック書き込み許可など）は実装方式により異なります。

## 7. モデル差分メモ

- HC4: 基本モデル
- HC4E: 2段スタック（A/B）かつ PC 8 bit の軽量系
- HC8: 命令拡張（例: LS, JL, LP）を持つ

命令差分の一覧はソフトウェア編を参照してください。

差分の要点:

| 項目 | HC4 | HC4E | HC8 |
| --- | --- | --- | --- |
| スタック段数  | 3段（A/B/C） | 2段（A/B） | 3段（A/B/C） |
| PC幅 | 実装により広幅（例:12 bit） | 8 bit | 実装依存 |
| 命令セット | 基本 | 制限あり | 拡張あり |
| I/Oレジスタ | 実装依存 | r14, r15 を使用 | 実装依存 |

注記:
- HC4E のアドレス空間は 16ニブル（r0-r15）として扱う運用を基本とする

## 8. 回路図・基板データ

- HC4 の回路: HC4_KiCad/
- HC4E の回路: HC4_KiCad_EE/
- メモリボード: HC_MemoryBoard/

KiCad がない場合は README の KiCanvas リンクを利用してください。

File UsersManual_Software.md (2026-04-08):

- [How to read these tables](#how-to-read-these-tables)
- [Instruction table](#instruction-table)
  - [HC4](#hc4)
  - [HC4E](#hc4e)
  - [HC8](#hc8)
- [Instruction List](#instruction-list)
  - [Logical and alithmetic instructions](#logical-and-alithmetic-instructions)
  - [Register and memory access instructions](#register-and-memory-access-instructions)
  - [System control instructions](#system-control-instructions)
- [Instruction manual](#instruction-manual)
  - [Logical and alithmetic instructions](#logical-and-alithmetic-instructions-1)
  - [Register and memory access instructions](#register-and-memory-access-instructions-1)
  - [System control instructions](#system-control-instructions-1)
  - [HC4E](#hc4e-1)
- [Instruction usage examples and caveats](#instruction-usage-examples-and-caveats)
- [Tutorial: LED blink (lchika.asm)](#tutorial-led-blink-lchikaasm)
- [Troubleshooting](#troubleshooting)

# How to read these tables

As noted [README](https://github.com/nasu8151/HC4), instruction of these CPUs are 8-bit wide.   
```r``` means a 4-bit wide register. In the program, it is represented by ```r0``` to ```r15``` in program.    
```#i``` means a 4-bit wide immediate data.    
```[AB]``` means indirect addressing of stack level A and B. MSB is level B.   
```[ABC]``` means indirect addressing of stack level A, B and C. MSB is level C.    
"PC" means Program Counter.

# Instruction table

Do not include any instructions marked as (Reserved) in the program.
These instrucitons may not work correctly. 

## HC4

| bit 5-4→<br>7-6↓ | 00         | 01         | 10                      | 11         |
| ---------------- | ---------- | ---------- | ----------------------- | ---------- |
| 00               | ```SM```   | ```SC r``` | ```SU r```              | ```AD r``` |
| 01               | ```XR r``` | ```OR r``` | ```AN r```              | ```SA r``` |
| 10               | ```LM```   | ```LD r``` | ```LI #```              | (Reserved) |
| 11               | (Reserved) | (Reserved) | ```JP flag```, ```NP``` | (Reserved) |

## HC4<sub>E</sub>

| bit 5-4→<br>7-6↓ | 00         | 01         | 10                      | 11         |
| ---------------- | ---------- | ---------- | ----------------------- | ---------- |
| 00               | (Reserved) | (Reserved) | (Reserved)              | ```AD r``` |
| 01               | ```XR r``` | (Reserved) | (Reserved)              | ```SA r``` |
| 10               | (Reserved) | ```LD r``` | ```LI #```              | (Reserved) |
| 11               | (Reserved) | (Reserved) | ```JP flag```, ```NP``` | (Reserved) |

## HC8

| bit 5-4→<br>7-6↓ | 00         | 01         | 10                      | 11                      |
| ---------------- | ---------- | ---------- | ----------------------- | ----------------------- |
| 00               | ```SM```   | ```SC r``` | ```SU r```              | ```AD r```              |
| 01               | ```XR r``` | ```OR r``` | ```AN r```              | ```SA r```              |
| 10               | ```LM```   | ```LD r``` | ```LI #```              | (Reserved)              |
| 11               | ```LS #``` | (Reserved) | ```JP flag```, ```NP``` | ```JL flag```, ```LP``` |

# Instruction List

## Logical and alithmetic instructions

| Name       | Opc  | Opr | Flag changes | Function   |                            |
| ---------- | ---- | --- | ------------ | ---------- | -------------------------- |
| ```SU r``` | 0010 | r   | C, Z         | r <= A-B   | SUbtract and store in r    |
| ```AD r``` | 0011 | r   | C, Z         | r <= A+B   | ADd and store in r         |
| ```XR r``` | 0100 | r   | Z            | r <= A^B   | bitwise XoR and store in r |
| ```OR r``` | 0101 | r   | Z            | r <= A\|B  | bitwise OR and store in r  |
| ```AN r``` | 0110 | r   | Z            | r <= A&B   | bitwise ANd and store in r |

## Register and memory access instructions

| Name          | Opc  | Opr  | Flag changes |                            |
| ------------- | ---- | ---- | ------------ | -------------------------- |
| ```SM```      | 0000 | 0000 | Z            | Store C in [AB]            |
| ```SC r```    | 0001 | r    | Z            | Store C in r               |
| ```SA r```    | 0111 | r    | Z            | Store A in r               |
| ```LM```      | 1000 | 0000 |              | LoaD from [AB]             |
| ```LD r```    | 1001 | r    |              | LoaD form r                |
| ```LI #i```   | 1010 | i    |              | LoaD immediate             |
| \*```LS #i``` | 1100 | i    |              | Load immediate and Shift A |

Note:    
\* Only for HC8.

## System control instructions

| Name        | Opc  | Opr  |                               |
| ----------- | ---- | ---- | ----------------------------- |
| ```JP```    | 1110 | 0000 | JumP [ABC]                    |
| ```JP C```  | 1110 | 0010 | Jump if Carry flag is set     |
| ```JP NC``` | 1110 | 0011 | Jump if Carry flag is Not set |
| ```JP Z```  | 1110 | 0100 | Jump if Zero flag is set      |
| ```JP NZ``` | 1110 | 0101 | Jump if Zero flag is Not set  |
| ```NP```    | 1110 | 0001 | No oPlation                   |

# Instruction manual
## Logical and alithmetic instructions

These instructions are executed for stack levels A and B, and store the results in registers which specified ```r```.

## Register and memory access instructions

Store instructions store value of stack level A or C in registers or memory area. ```SA r``` instruction refers stack level A, and ```SC r``` and ```SM``` instructions refer stack level C.   
Load instructions, ```LD```,  load stack level A from register or memory area. When a value is loaded into stack level A, the previous value of level A moves to level B, and the value of level B moves to level C. ```LD r``` refers register ```r```, ```LI #i``` loads immediate data and ```LM``` refers memory address specified level A and B.   
Load and shift instruction, ```LS #i```, used to load an 8-bit wide data onto the stack.
For the ```LS #``` and ```LI #``` instructions, binary(```0b1010```) and hexadecimal(```0xA```) literals can be used.

## System control instructions

```NP``` does nothing. This is equivalent to ```NOP```.   
```JP``` instructions change conditionally PC.

## HC4<sub>E</sub>

In HC4<sub>E</sub>, only stack levels A and B are valid.
It has 16 nibbles of address space, only register addressing mode(```r```) and 8-bit wide program counter.
I/O Registers are placed ```r14``` and ```r15```.

# Instruction usage examples and caveats

## AD r / SU r

Example:

```asm
ld #0x3
ld #0x5
ad r1
```

Caveats:

- Operands are mainly stack A/B, and the result is written to register `r`.
- C and Z flags are updated and may affect the next conditional jump.

## XR r / OR r / AN r

Example:

```asm
ld #0xA
ld #0x3
xr r2
```

Caveats:

- Z flag update can be used for zero-check branching.
- Do not confuse arithmetic carry behavior with logical operations.

## SA r / SC r / SM

Example:

```asm
ld #0x9
sa r0
```

Caveats:

- `SA r` stores A, while `SC r` and `SM` store C.
- Depending on assembler dialect, store-to-[AB] may be written as `SM` or `SC [AB]`.

## LD r / LI #i / LM

Example:

```asm
li #0xF
ld r1
lm
```

Caveats:

- Load pushes stack levels down (A <- new, B <- old A, C <- old B).
- `LM` depends on `[AB]`, so prepare stack values before reading memory.

## JP family / NP

Example:

```asm
ld #0
ld #0
ld #0x4
jp
```

Caveats:

- Jump destination is made from stack levels; wrong loading order causes wrong branch.
- `NP` is useful as a timing separator during debug.

# Tutorial: LED blink (lchika.asm)

Reference file: `extra/lchika.asm`

```asm
np
ld #0xF
ld #0xF
ld #0
sc [AB]
ld #0
ld #0xF
ld #0
sc [AB]
ld #0
ld #0
ld #0x1
jp
```

Line-by-line intent:

1. `np`: initial NOP.
2. `ld #0xF`: prepare address part.
3. `ld #0xF`: prepare address part.
4. `ld #0`: output data (for one LED state).
5. `sc [AB]`: write to memory-mapped I/O.
6. `ld #0`: prepare next write.
7. `ld #0xF`: keep I/O range.
8. `ld #0`: output data for another state.
9. `sc [AB]`: write again.
10. `ld #0`: prepare jump destination part.
11. `ld #0`: prepare jump destination part.
12. `ld #0x1`: prepare jump destination part.
13. `jp`: loop back.

# Troubleshooting

- Avoid instructions marked as Reserved.
- Verify I/O address decoding in hardware.
- Verify stack content before `JP`.
- Verify C/Z flag updates before conditional jump.
- Verify stack push side effect after `LD` and `LI`.
- On HC4E, avoid code that assumes stack level C.
- Verify assembler dialect differences for `SM` and `SC [AB]`.

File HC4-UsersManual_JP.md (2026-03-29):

# HC4シリーズ ユーザーズマニュアル ハードウェア編

## 概要

- 教育用のローコスト4bit CPU
- 演算スタックモデルを採用
- シンプルな構造によりローコストを実現
- Verilogによる実装、汎用ロジックICによる実装がある
- ハーバードアーキテクチャを使用（プログラム:8bit\*4096、データ:4bit\*256）
- 演算スタックモデルを使用

## 1.もくじ

## 3.内部構造

### 3.1.全体ブロック図

Block diagram of this CPU.

#### 3.1.1.ALU

このCPUはALU(Arithmetic Logic Unit, 算術論理ユニット)ですべての演算を行う。
ALUはAND,OR,XOR,加算,減算の演算に対応しており、ソースに演算スタックAとBをとり、結果をデータバスに出力する。
また、演算スタックAをデータバスに出力するときにも使用する。\
\
関連する信号線:
- STACK-A[3:0]
- STACK-B[3:0]
- DATABUS[3:0]
- Carry-IN
- Carry-OUT

#### 3.1.2.データバス、アドレスバス

データバス、アドレスバスはCPUとRAMやI/Oなどを相互に接続する。
データバスは4bit、アドレスバスは8bitである。よって、メモリ空間は4bit*256である。
このCPUはメモリマップドI/Oを使用するため、すべてのI/O機器はアドレスバス、データバスに接続しなければならない。
アドレスの割り当ては基本的に自由だが、0x00~0x0Fまではレジスタ領域として予約されているため、必ずRAMを配置しなければならない。\
\
関連する信号線:
- DATA-BUS[3:0]
- ADDRESS-BUS[7:0]
- nWR
- nRD

#### 3.1.3.演算スタック

演算スタックはほぼすべての命令のオペランドとして暗黙的に使用される。
演算スタックはLIFO構造であり（つまりスタックではなくキューであり）、```LD```, ```LI```命令で値をロードする。
演算スタックはA, B, Cの3レベルを持ち、ロードされたデータは初めにレベルAに入る。
レベルAの入力はデータバスに接続されている。
演算スタックがロードされたとき、レベルCにあったデータは消失する。
各命令ごとの演算スタックの動作やとるオペランドについては、ユーザーズマニュアル ソフトウェア編を参照されたし。

#### 3.1.4.プログラムカウンタ

プログラムカウンタ(PC)は12bit幅のレジスタであり、現在実行中の命令のアドレスが格納されている。
プログラムカウンタはCLKの立ち上がりエッジでインクリメントされる。つまり、毎回の命令実行が終わったときにインクリメントされる。
ジャンプ命令（```JP```）が実行されたとき、次のCLKの立ち上がりでPCの値はスタックのA,B,Cの値に書き換えられる。

#### 3.1.5.命令デコーダ

命令デコーダは、命令の種類に応じて、CPUの各部に制御信号を供給する。
この部分の構造は実装によって左右される。

#### 3.1.6

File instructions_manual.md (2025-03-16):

- [How to read these tables](#how-to-read-these-tables)
- [Instruction table](#instruction-table)
  - [HC4](#hc4)
  - [HC8](#hc8)
- [Instruction List](#instruction-list)
  - [Logical and alithmetic instructions](#logical-and-alithmetic-instructions)
  - [Register and memory access instructions](#register-and-memory-access-instructions)
  - [System control instructions](#system-control-instructions)
- [Instruction manual](#instruction-manual)
  - [Logical and alithmetic instructions](#logical-and-alithmetic-instructions-1)
  - [Register and memory access instructions](#register-and-memory-access-instructions-1)
  - [System control instructions](#system-control-instructions-1)

# How to read these tables

As noted [README](https://github.com/nasu8151/HC4), instruction of these CPUs are 8-bit wide.   
```r``` means a 4-bit wide register. In the program, it is represented by ```r0``` to ```r15``` in program.    
```#i``` means a 4-bit wide immediate data.    
```[AB]``` means indirect addressing of stack level A and B. MSB is level B.
```[ABC]``` means indirect addressing of stack level A, B and C. MSB is level C.    
"PC" means Program Counter.

# Instruction table
## HC4

| bit 5-4\7-6 | 00            | 01         | 10            | 11                       |
| ----------- | ------------- | ---------- | ------------- | ------------------------ |
| 00          | ```SC [AB]``` | ```XR r``` | ```LD [AB]``` | (Reserved)               |
| 01          | ```SC r```    | ```OR r``` | ```LD r```    | (Reserved)               |
| 10          | ```SU r```    | ```AN r``` | ```LD #i```   | ```JP [ABC]```, ```NP``` |
| 11          | ```AD r```    | ```SA r``` | (Reserved)    | (Reservred)              |

## HC8

| bit 5-4\7-6 | 00            | 01         | 10            | 11                      |
| ----------- | ------------- | ---------- | ------------- | ----------------------- |
| 00          | ```SC [AB]``` | ```XR r``` | ```LD [AB]``` | ```LS #i```             |
| 01          | ```SC r```    | ```OR r``` | ```LD r```    | (Reserved)              |
| 10          | ```SU r```    | ```AN r``` | ```LD #i```   | ```JP [AB]```, ```NP``` |
| 11          | ```AD r```    | ```SA r``` | (Reserved)    | ```JL [AB]```, ```LP``` |

# Instruction List

## Logical and alithmetic instructions

| Name       | Opc  | Opr | Flag changes | Function|                            |
| ---------- | ---- | --- | ------------ | ------- | -------------------------- |
| ```SU r``` | 0010 | r   | C, Z         | r<-A-B  | SUbtract and store in r    |
| ```AD r``` | 0011 | r   | C, Z         | r<-A+B  | ADd and store in r         |
| ```XR r``` | 0100 | r   | Z            | r<-A^B  | bitwise XoR and store in r |
| ```OR r``` | 0101 | r   | Z            | r<-A\|B | bitwise OR and store in r  |
| ```AN r``` | 0110 | r   | Z            | r<-A&B  | bitwise ANd and store in r |

## Register and memory access instructions

| Name            | Opc  | Opr  | Flag changes |                            |
| --------------- | ---- | ---- | ------------ | -------------------------- |
| \*```SC [AB]``` | 0000 | 0000 | Z            | Store C in [AB]            |
| ```SC r```      | 0001 | r    | Z            | Store C in r               |
| ```SA r```      | 0111 | r    | Z            | Store A in r               |
| \*```LD [AB]``` | 1000 | 0000 |              | LoaD from [AB]             |
| ```LD r```      | 1001 | r    |              | LoaD form r                |
| ```LD #i```     | 1010 | i    |              | LoaD immediate             |
| \*\*```LS #i``` | 1100 | i    |              | Load immediate and Shift A |

Note:    
\* Can be omitted addressing.   
\*\* Only for HC8.

## System control instructions

| Name                | Opc  | Opr  |                               |
| ------------------- | ---- | ---- | ----------------------------- |
| \*```JP [ABC]```    | 1110 | 0000 | JumP [ABC]                    |
| \*```JP C [ABC]```  | 1110 | 0010 | Jump if Carry flag is set     |
| \*```JP NC [ABC]``` | 1110 | 0011 | Jump if Carry flag is Not set |
| \*```JP Z [ABC]```  | 1110 | 0100 | Jump if Zero flag is set      |
| \*```JP NZ [ABC]``` | 1110 | 0101 | Jump if Zero flag is Not set  |
| ```NP```            | 1110 | 0001 | No oPlation                   |

Note:    
\* Can be omitted addressing.

# Instruction manual
## Logical and alithmetic instructions

These instructions are executed for stack levels A and B, and store the results in registers which specified ```r```.

## Register and memory access instructions

Store instructions store value of stack level A or C in registers or memory area. ```SA r``` instruction refers stack level A, and ```SC r``` and ```SC [AB]``` instructions refer stack level C.   
Load instructions, ```LD```,  load stack level A from register or memory area. When a value is loaded into stack level A, the previous value of level A moves to level B, and the value of level B moves to level C. ```LD r``` refers register ```r```, ```LD #i``` loads immediate data and ```LD [AB]``` refers memory address specified level A and B.
Load and shift instruction, ```LS #i```, used to load an 8-bit wide data onto the stack.

## System control instructions

```NP``` does nothing. This is equivalent to ```NOP```.   
```JP``` instructions change conditionally PC.

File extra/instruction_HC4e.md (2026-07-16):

Instruction to internal signals. (x means "Don't Care")

| Name | Opc  | ALU_S | ~ALU_OE | ~IMM_OE | ~is_JP | Carry_EN | ~Stk_LE | Mem_R | SUB |
| --- | ---- | ----- | --- | --- | --- | --- | --- | ----- | --- |
| ```SA r``` | 0001 | 00 | x | 1 | x | x | 1 | x | x |
| ```AD r``` | 0010 | 01 | 0 | 1 | 1 | 1 | 1 | 0 | 0 |
| ```SU r``` | 0011 | 01 | 0 | 1 | 1 | 1 | 1 | 0 | 1 |
| ```XR r``` | 0100 | 10 | 0 | 1 | 1 | 0 | 1 | 0 | x |
| ```RS r``` | 0111 | 11 | 0 | 1 | 1 | 0 | 1 | 0 | x |
| ```LD r``` | 1001 | xx | 1 | 1 | 1 | 0 | 0 | 1 | x |
| ```LD #i``` | 1010 | xx | 1 | 0 | 1 | 0 | 0 | 0 | x |
| (Reserved) | 110x | xx | 1 | x | x | x | x | x | x |
| ```JP *[ABC]``` | 111x | xx | 1 | x | 0 | 0 | 1 | 0 | x |

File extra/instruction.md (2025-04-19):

Instruction to internal signals. (x means "Don't Care")

| Name | Opc  | ~ALU_OE | ~Imm_OE | LevC_OE | ~is_JP | BUS_EN | Memmode | ALU_~Eb</br>~Carry_EN | ~Stack_LE | I0a | I1a | I2a | I3a | Mem_R |
| --- | ---- | --- | --- | --- | --- | --- | --- | --- | --- | --- | --- | --- | --- | ----- |
| ```SC *[AB]```  | 0000 | 0 | 1 | 1 | 1 | 1 | 1 | 1 | 1 | x | x | x | x | 0 |
| ```SC r``` | 0001 | 0 | 1 | 1 | 1 | 1 | 0 | 1 | 1 | x | x | x | x | 0 |
| ```SU r``` | 0010 | 0 | 1 | 0 | 1 | 1 | 0 | 0 | 1 | 1 | 1 | 0 | 0 | 0 |
| ```AD r``` | 0011 | 0 | 1 | 0 | 1 | 1 | 0 | 0 | 1 | 0 | 0 | 1 | 1 | 0 |
| ```XR r``` | 0100 | 0 | 1 | 0 | 1 | 1 | 0 | 1 | 1 | 0 | 1 | 1 | 0 | 0 |
| ```OR r``` | 0101 | 0 | 1 | 0 | 1 | 1 | 0 | 1 | 1 | 0 | 1 | 1 | 1 | 0 |
| ```AN r``` | 0110 | 0 | 1 | 0 | 1 | 1 | 0 | 1 | 1 | 0 | 0 | 0 | 1 | 0 |
| ```SA r``` | 0111 | 0 | 1 | 0 | 1 | 1 | 0 | 1 | 1 | 0 | 1 | 0 | 1 | 0 |
| ```LD *[AB]```  | 1000 | 1 | 1 | x | 1 | 1 | 1 | 1 | 0 | x | x | x | x | 1 |
| ```LD r``` | 1001 | 1 | 1 | x | 1 | 1 | 0 | 1 | 0 | x | x | x | x | 1 |
| ```LD #i``` | 101x | 1 | 0 | x | 1 | 0 | 0 | 1 | 0 | x | x | x | x | 0 |
| (Reserved) | 110x | 1 | 1 | x | 1 | 0 | 0 | 1 | 0 | x | x | x | x | 0 |
| ```JP *[ABC]``` | 111x | 1 | 1 | x | 0 | 0 | 0 | 1 | 1 | x | x | x | x | 0 |

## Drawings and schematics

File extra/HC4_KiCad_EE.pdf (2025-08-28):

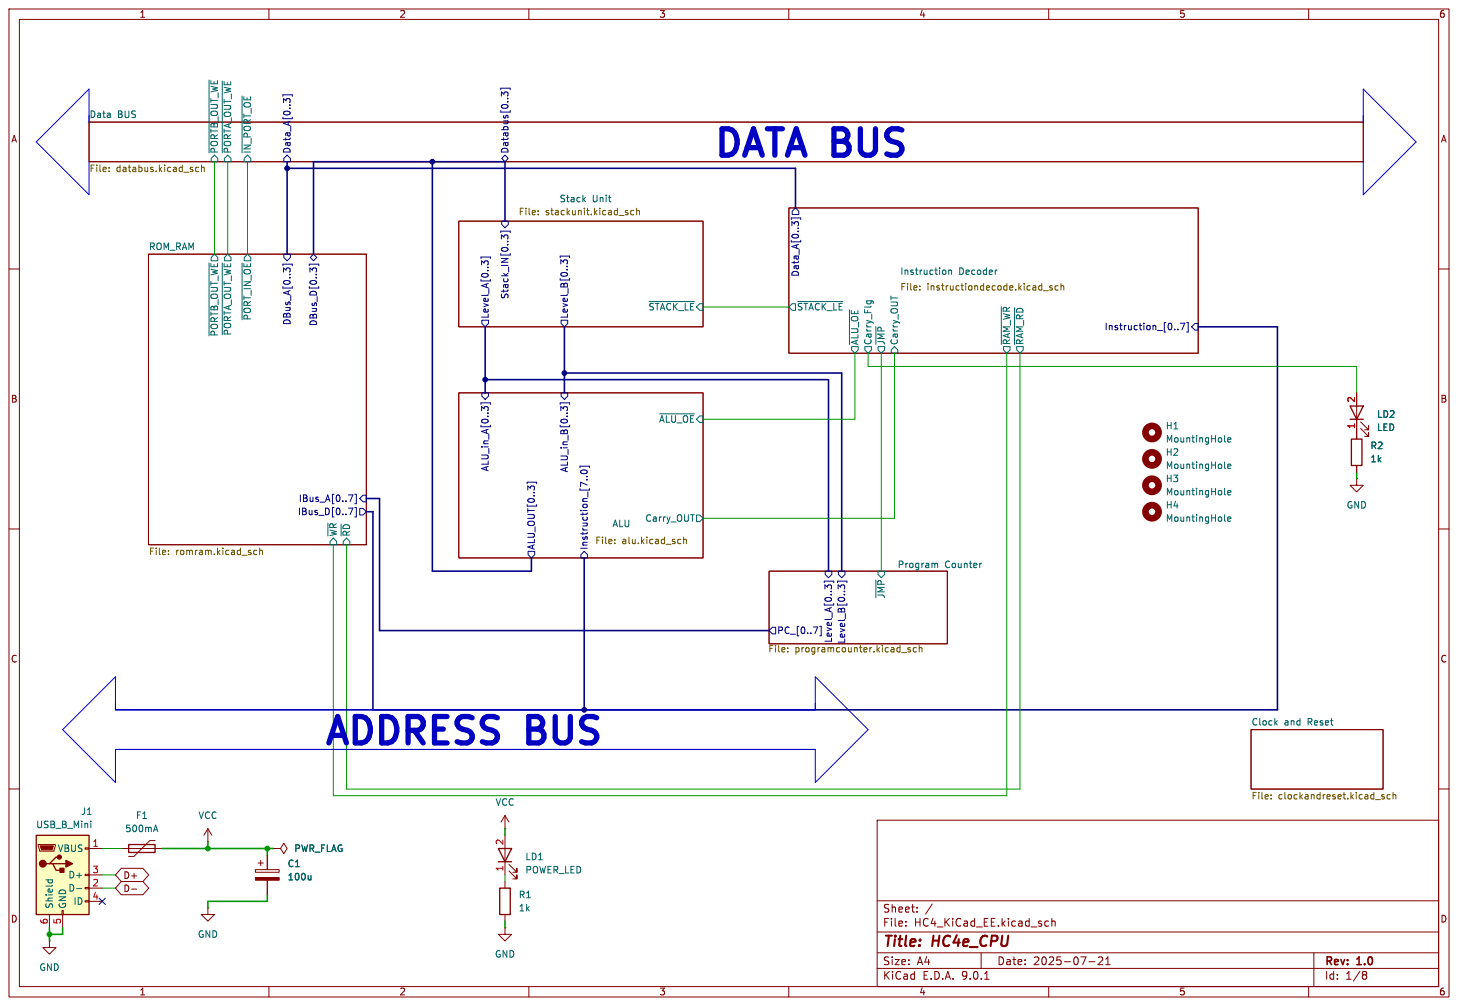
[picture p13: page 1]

Program Counter File: programcounter.kicad_sch F1

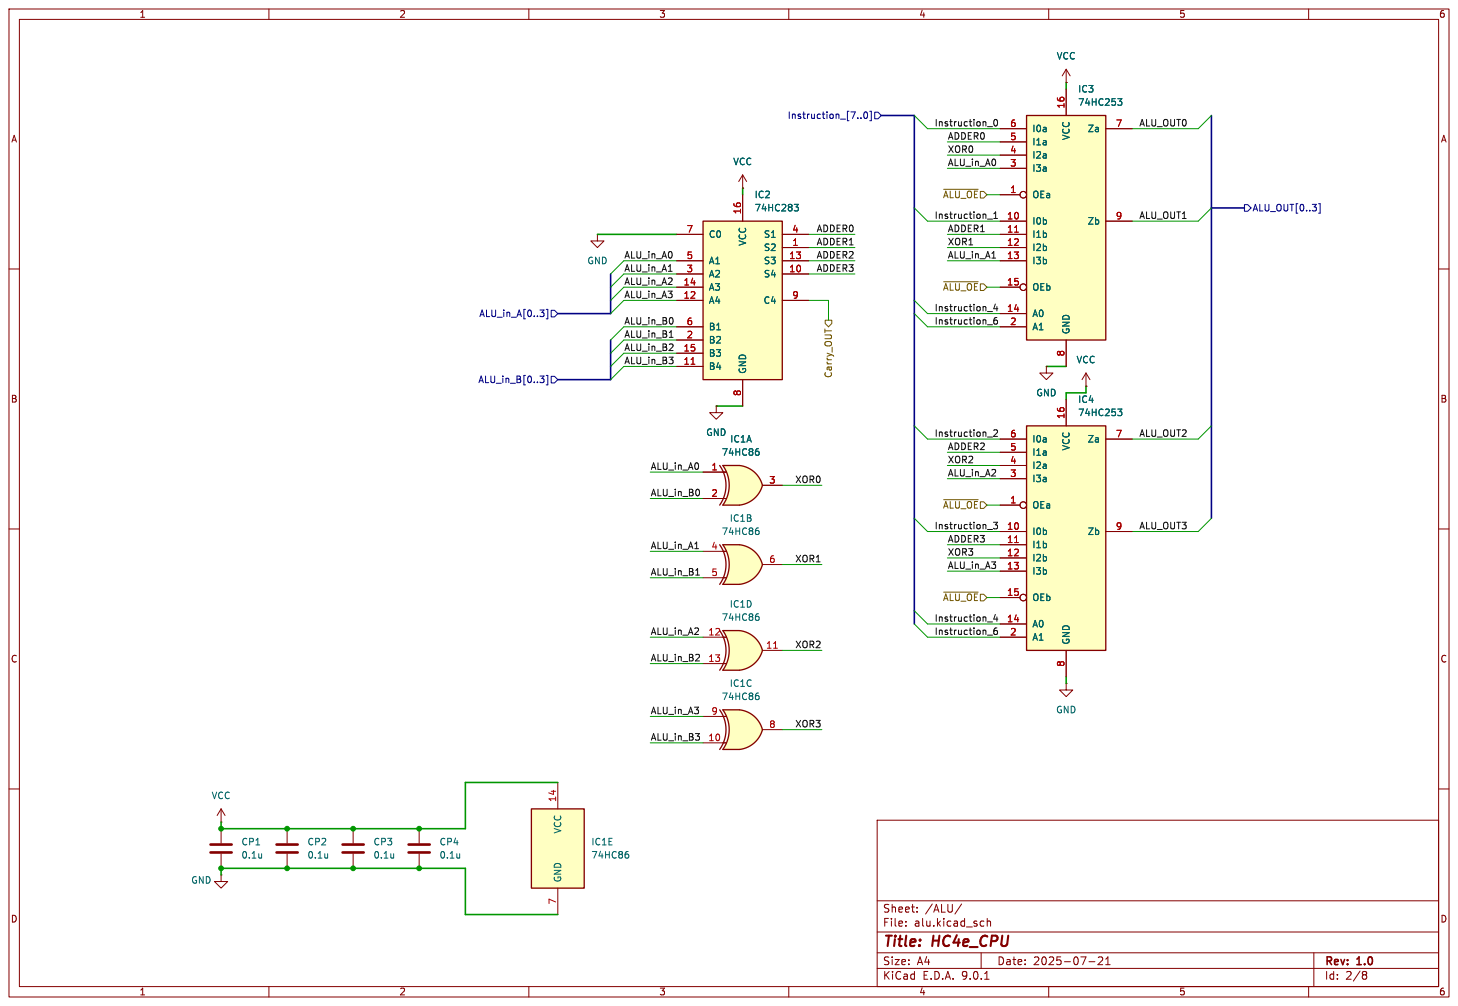
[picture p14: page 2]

File: alu.kicad_sch Sheet: /ALU/ CP1

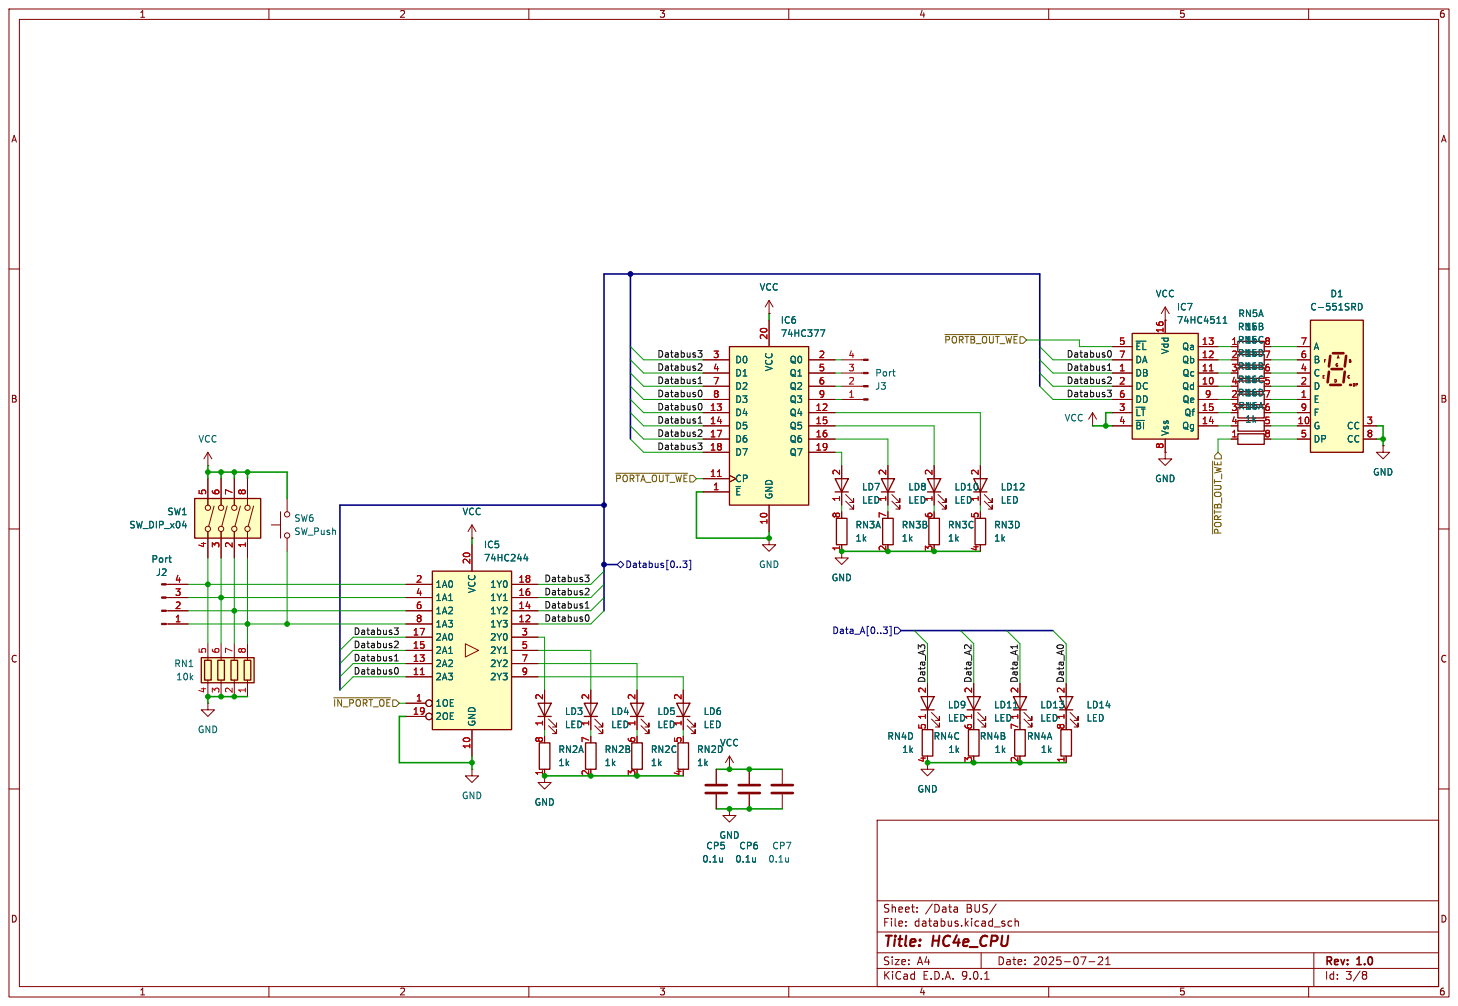
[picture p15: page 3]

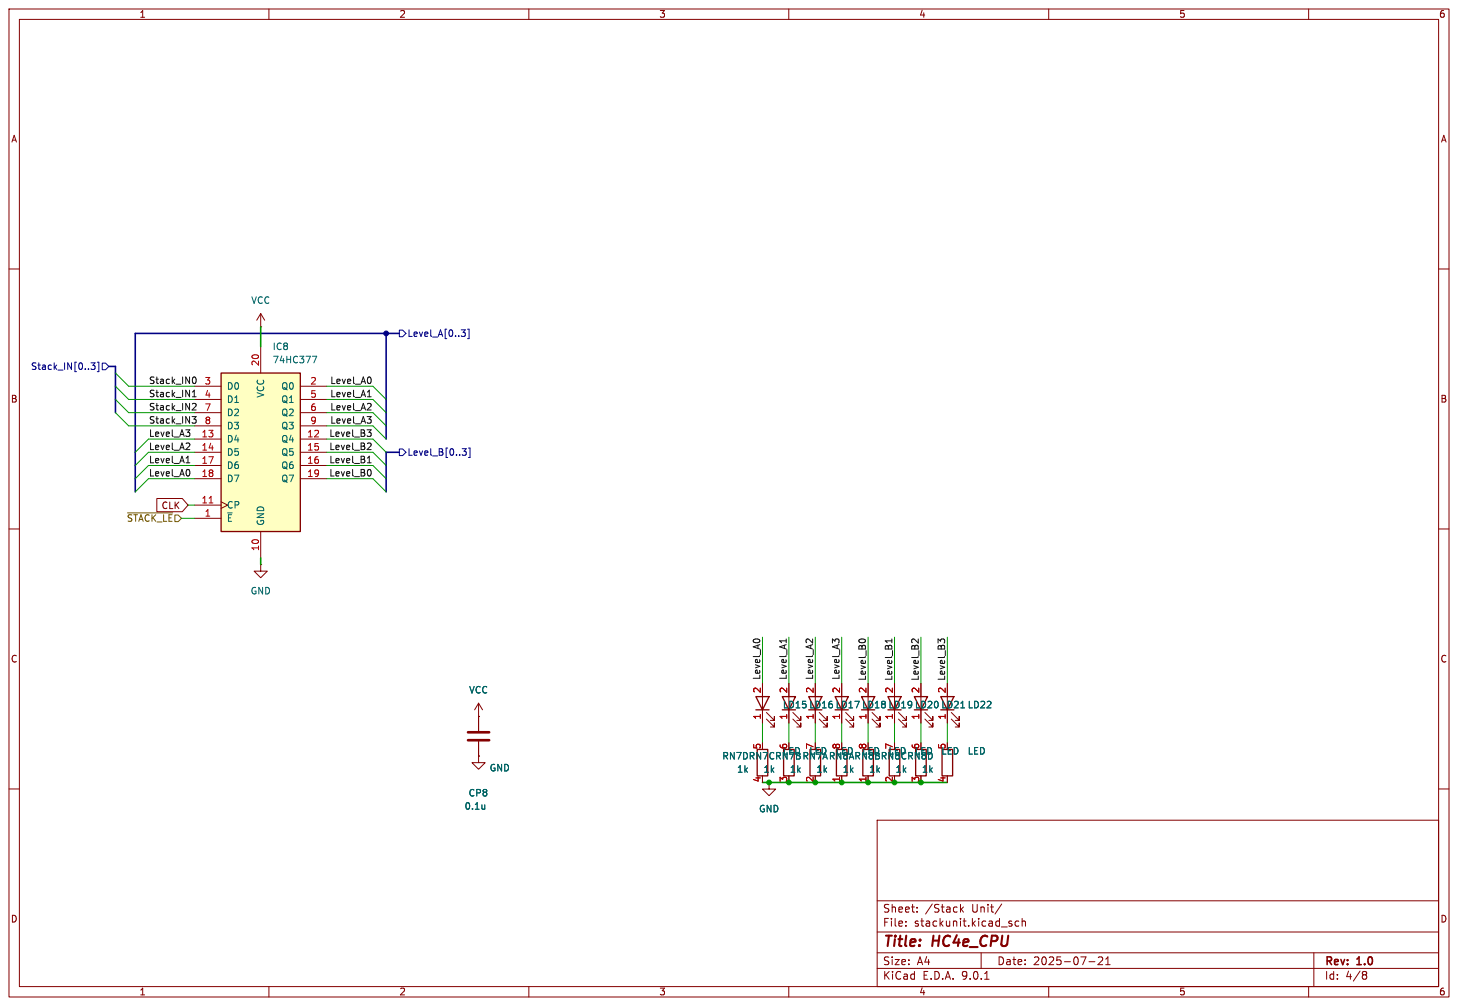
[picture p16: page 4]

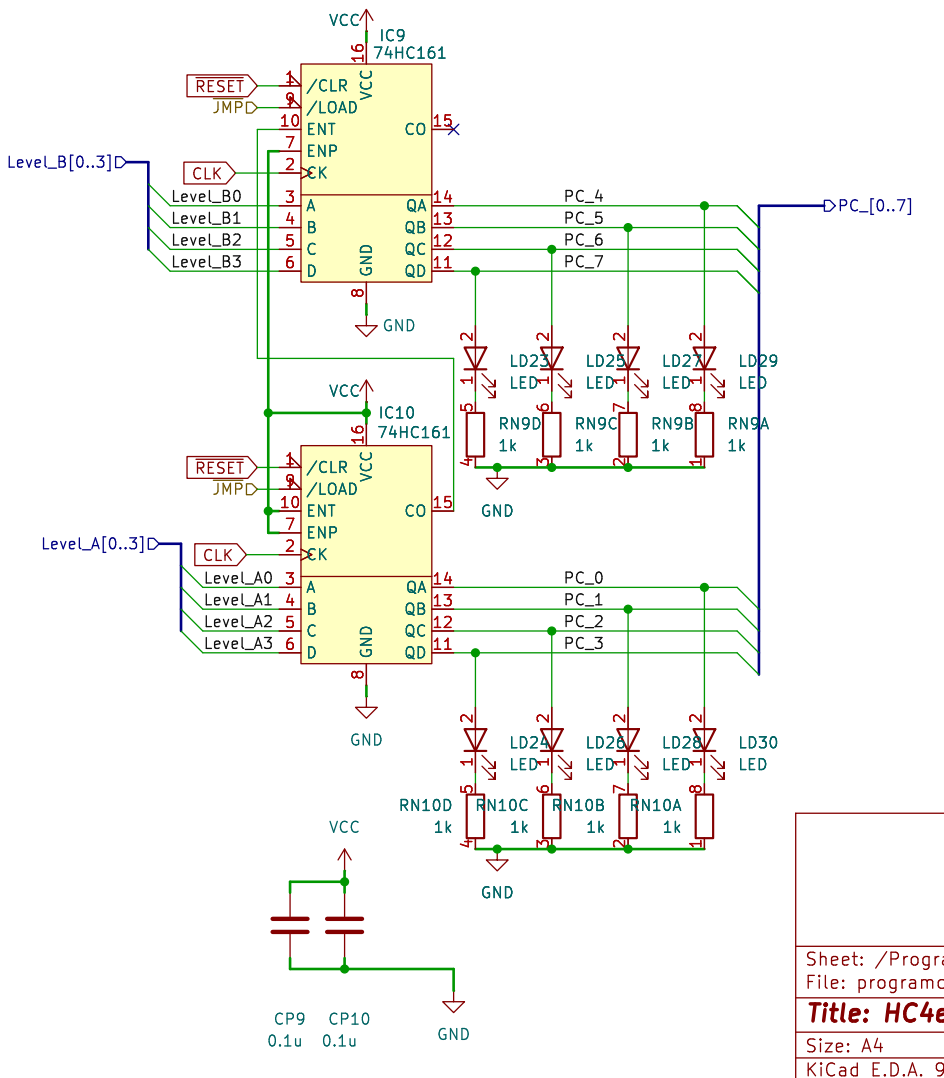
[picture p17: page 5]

8 CO 15 QA 14 QB 13 QC 12 QD 11 GND GND

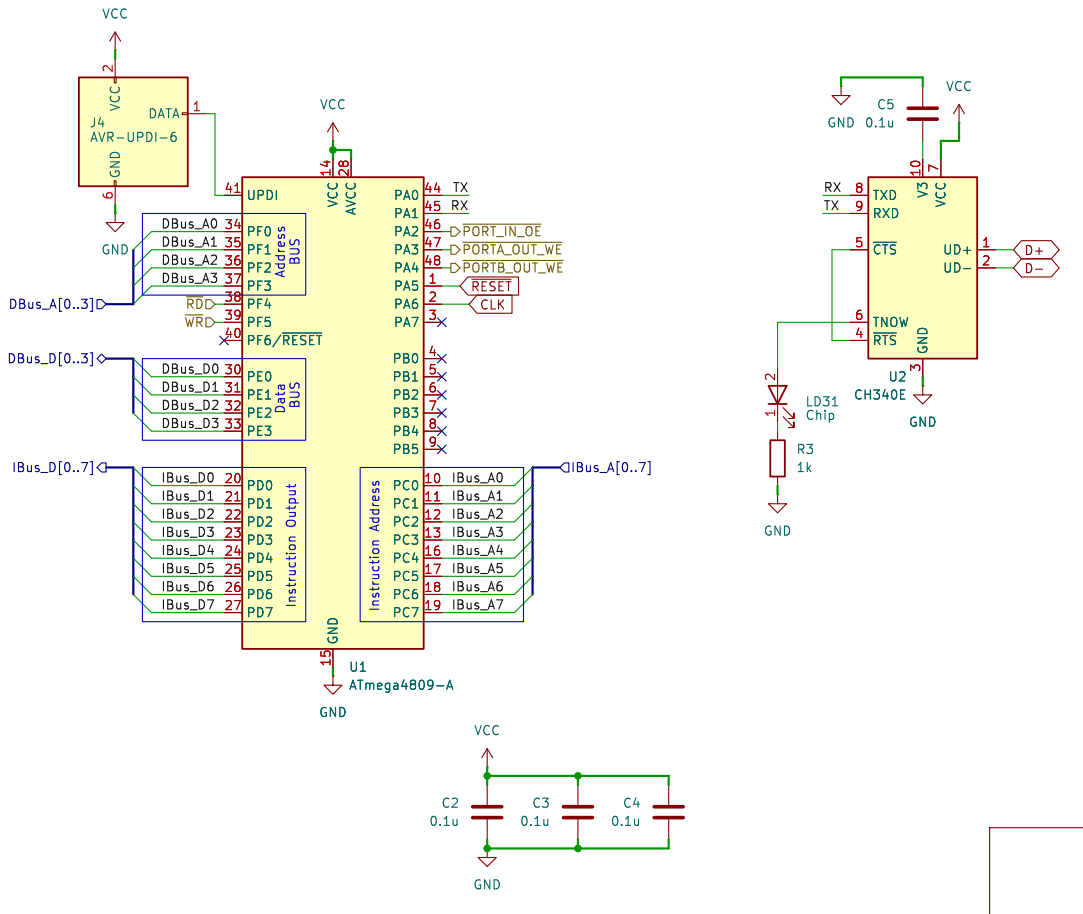
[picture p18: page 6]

3 TXD 8 RXD 9 ~{CTS} 5 TNOW 6 ~{RTS} 4 U2 CH340E

3 TXD 8 RXD 9 ~{CTS} 5 TNOW 6 ~{RTS} 4 GND

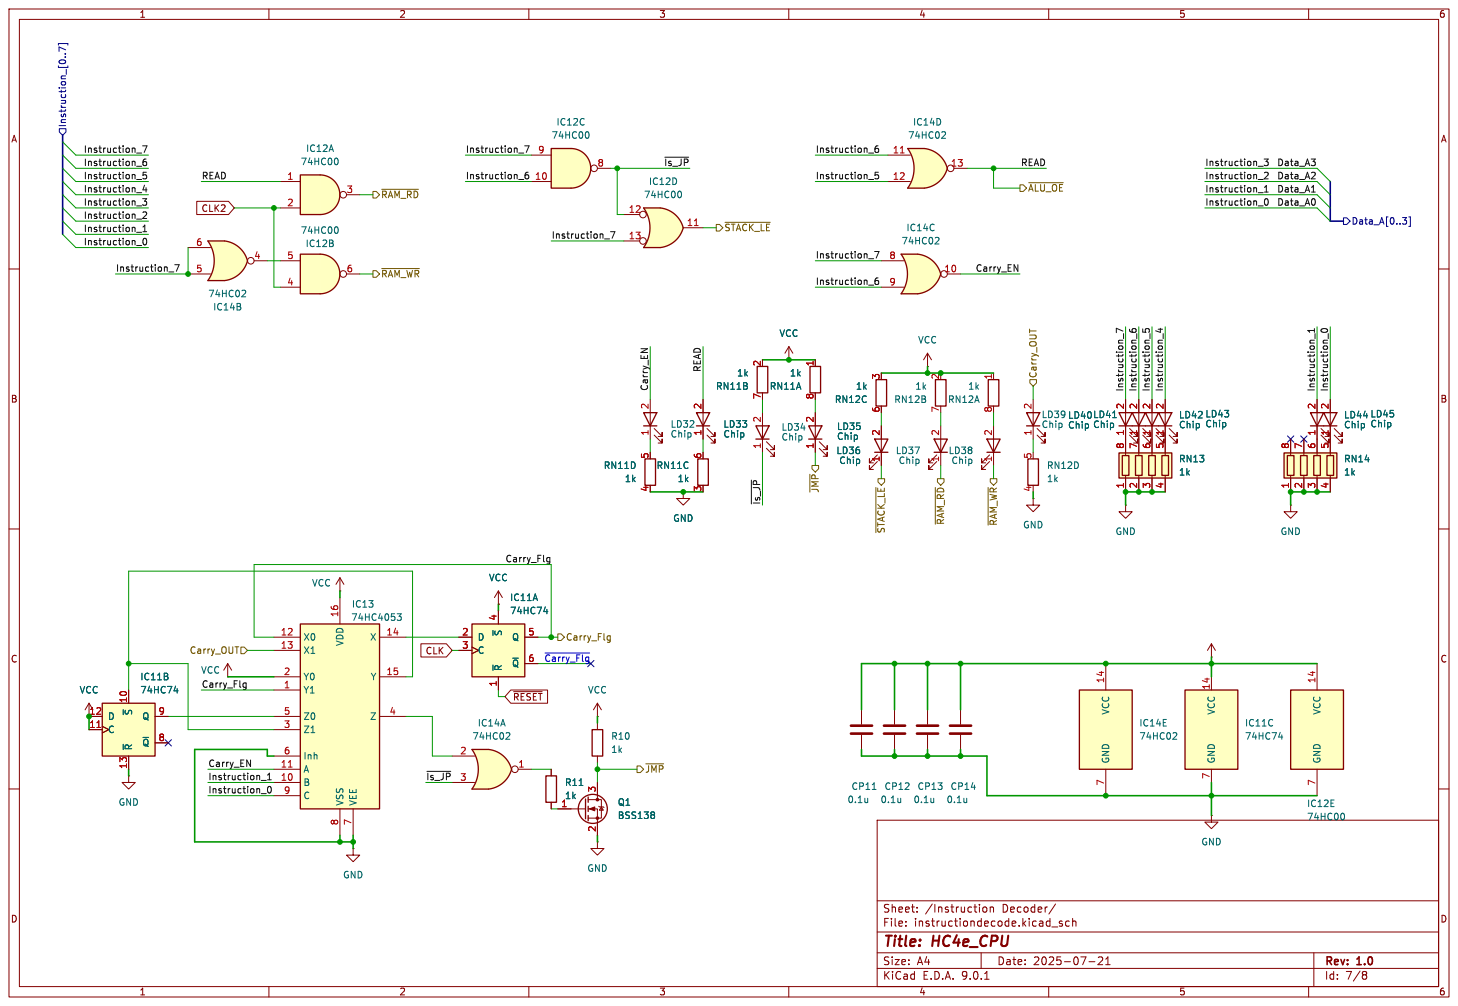
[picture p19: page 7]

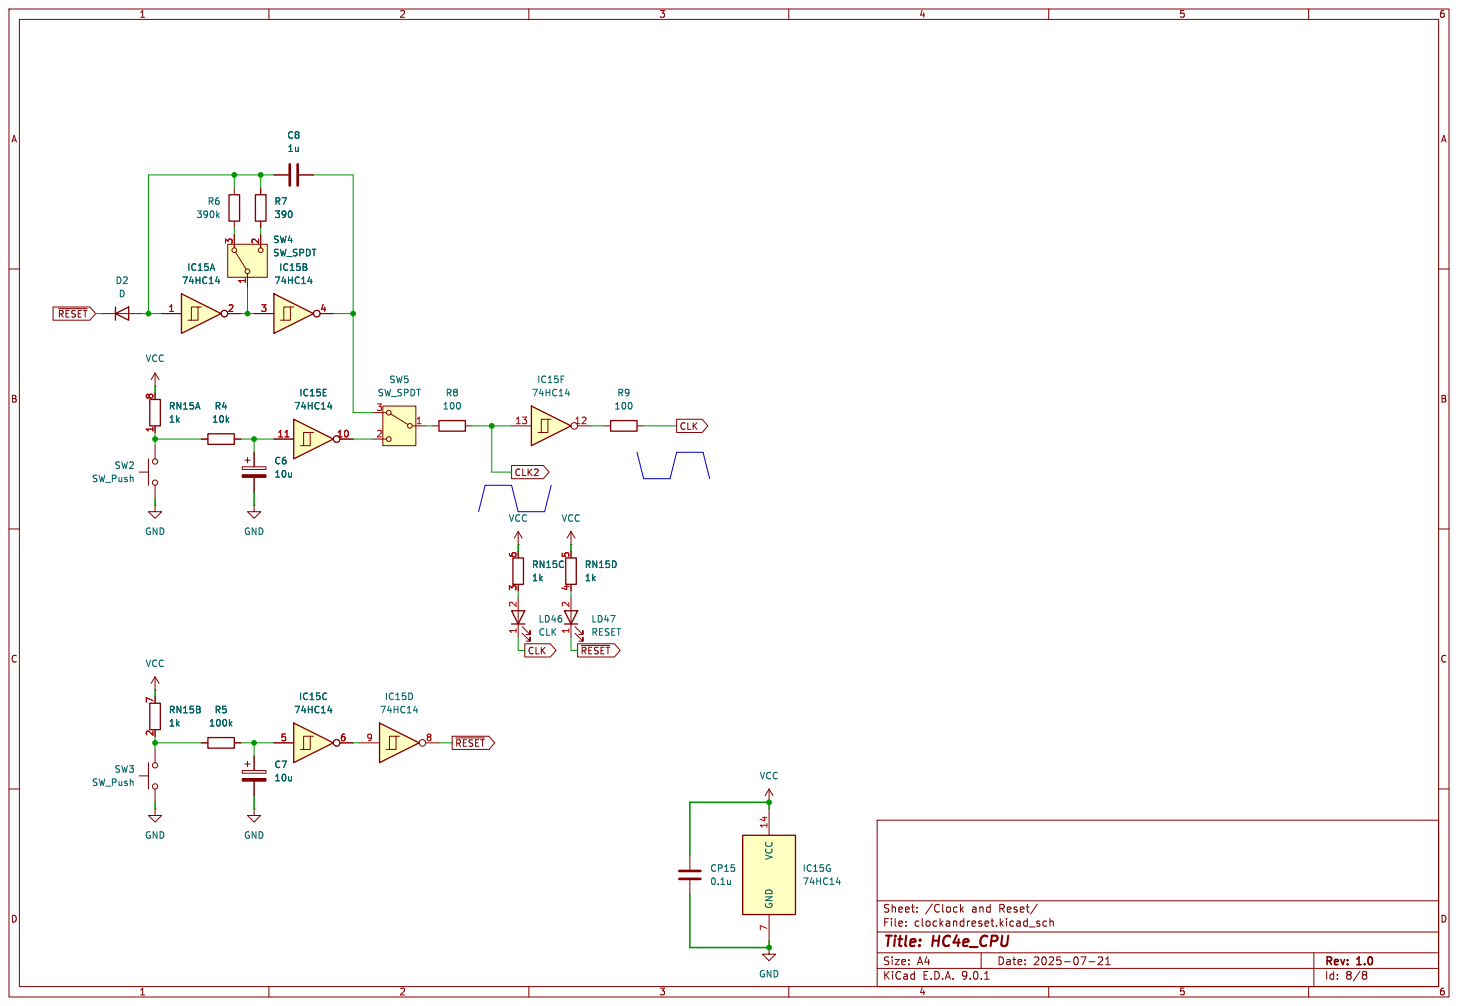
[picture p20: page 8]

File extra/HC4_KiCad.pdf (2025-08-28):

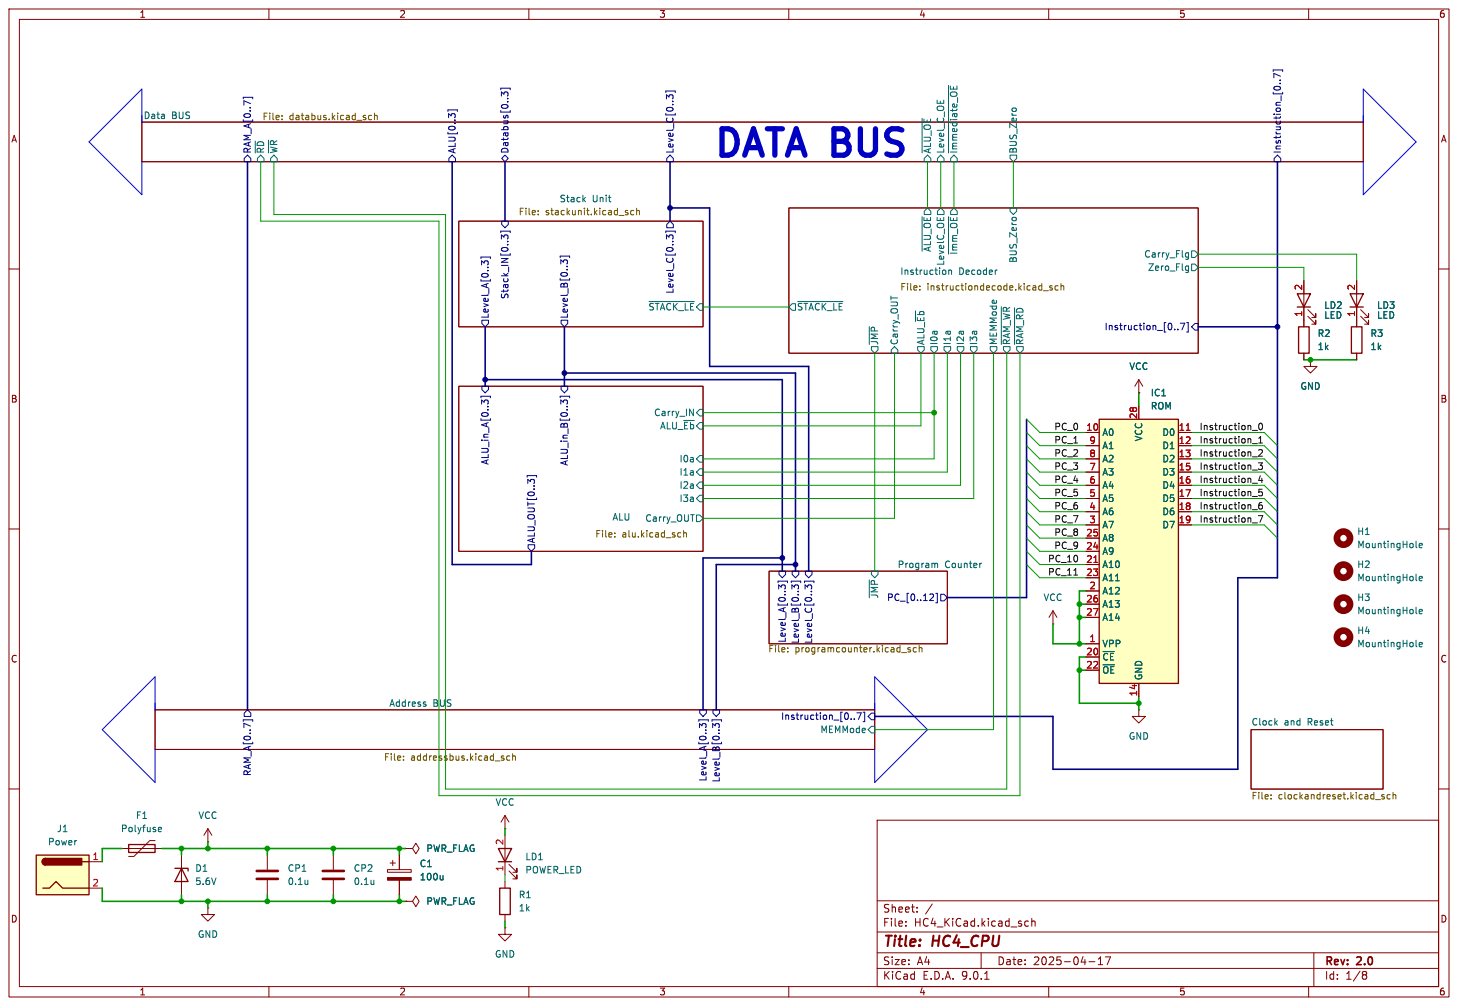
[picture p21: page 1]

Program Counter File: programcounter.kicad_sch

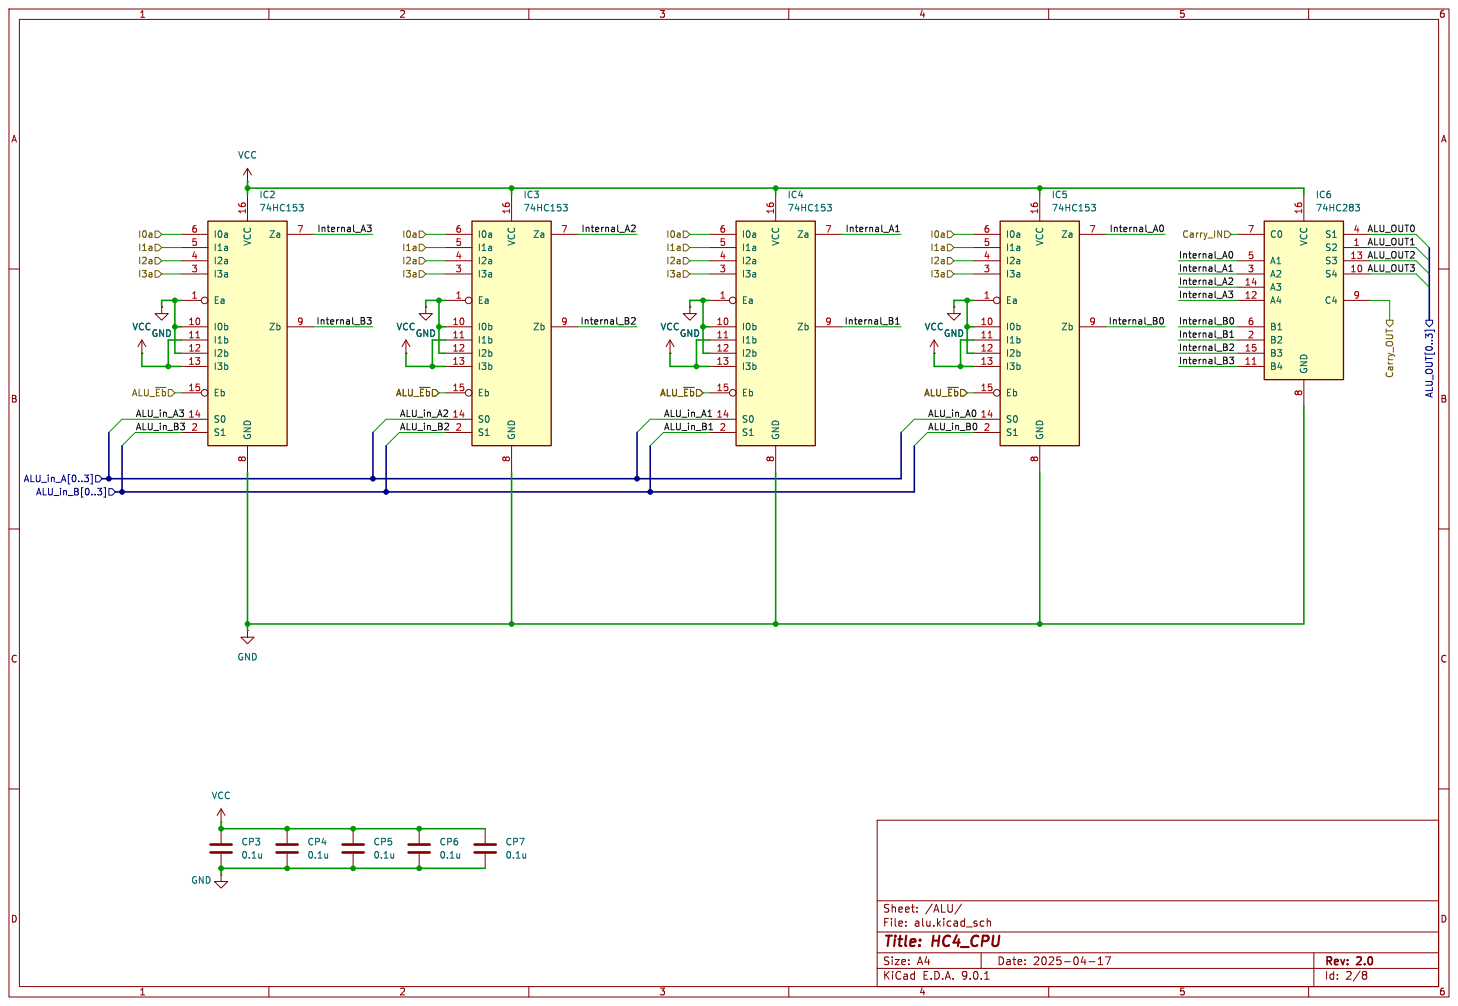
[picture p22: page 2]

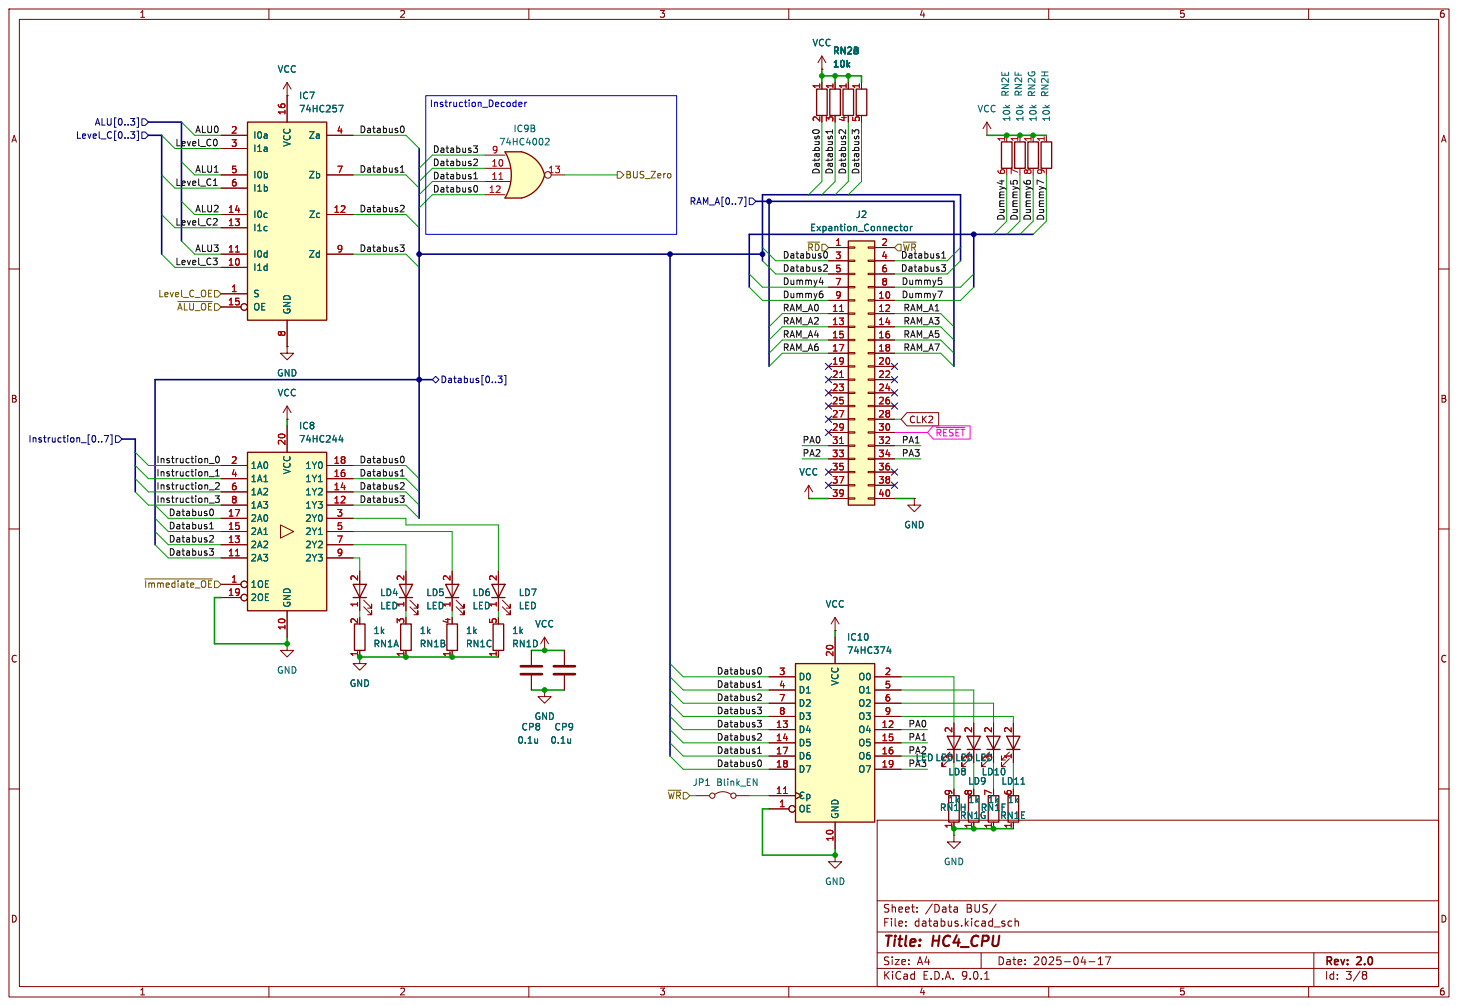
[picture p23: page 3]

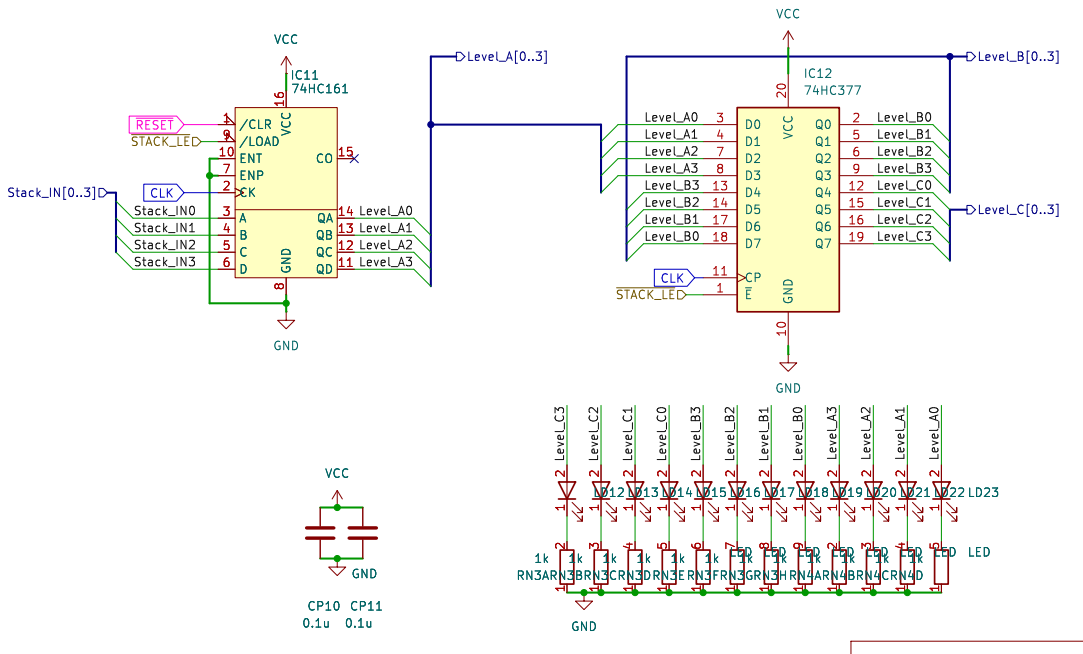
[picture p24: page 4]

8 CO 15 QA 14 QB 13 QC 12 QD 11 VCC GND
/CLR 1



8 Za 4 Zb 7 Zc 12 Zd 9 VCC



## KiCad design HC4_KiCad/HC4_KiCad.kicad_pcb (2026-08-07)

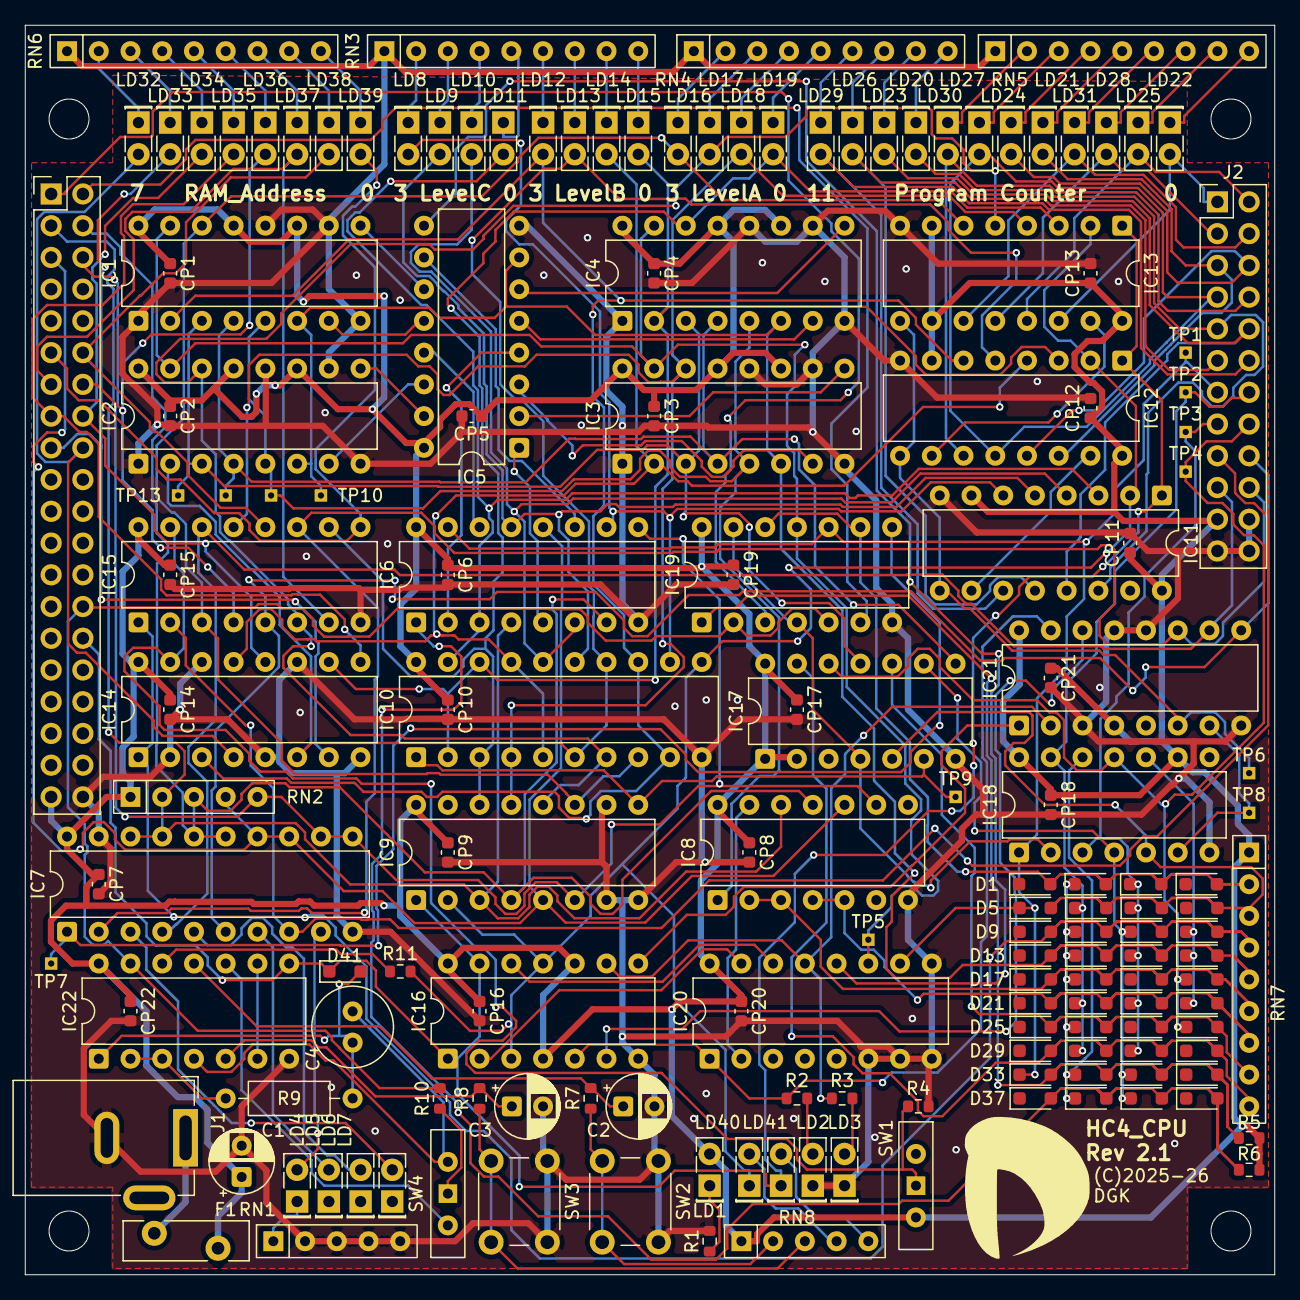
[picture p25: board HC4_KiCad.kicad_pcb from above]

Board: 2 copper layers, 100.0 x 100.0 mm, 174 parts (0 on the bottom side), 150 nets.

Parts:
C1: 100u; CP_Radial_D5.0mm_P2.50mm
C2, C3: 10u; CP_Radial_D5.0mm_P2.50mm
C4: 10u(Socket); C_Radial_D6.3mm_H5.0mm_P2.50mm
CP1, CP2, CP3, CP4, CP5, CP6, CP7, CP8, CP9, CP10, CP11, CP12, CP13, CP14, CP15, CP16, CP17, CP18, CP19, CP20, CP21, CP22: 0.1u; C_0603_1608Metric
D1, D2, D3, D4, D5, D6, D7, D8, D9, D10, D11, D12, D13, D14, D15, D16, D17, D18, D19, D20, D21, D22, D23, D24, D25, D26, D27, D28, D29, D30, D31, D32, D33, D34, D35, D36, D37, D38, D39, D40, D41: D; D_SOD-323_HandSoldering
F1: Polyfuse; Fuse_Bourns_MF-RG400
H1, H2, H3, H4: MountingHole; MountingHole_3.2mm_M3
IC1, IC2, IC3, IC4: 74HC153; DIP-16_W7.62mm
IC5: 74HC283; DIP-16_W7.62mm
IC6, IC14, IC15: 74HC257; DIP-16_W7.62mm
IC7: 74HC244; DIP-20_W7.62mm
IC8: 74HC4002; DIP-14_W7.62mm
IC9, IC11, IC12, IC13: 74HC161; DIP-16_W7.62mm
IC10: 74HC377; DIP-20_W7.62mm
IC16: 74HC74; DIP-14_W7.62mm
IC17: 74HC32; DIP-14_W7.62mm
IC18: 74HC04; DIP-14_W7.62mm
IC19: 74HC00; DIP-14_W7.62mm
IC20: 74HC4053; DIP-16_W7.62mm
IC21: 74HC151; DIP-16_W7.62mm
IC22: 74HC14; DIP-14_W7.62mm
J1: Power; BarrelJack_GCT_DCJ200-10-A_Horizontal
J2: Conn_02x12_Counter_Clockwise; PinHeader_2x12_P2.54mm_Vertical
J3: Expantion_Connector; PinHeader_2x20_P2.54mm_Vertical
LD1: POWER_LED; LED_Rectangular_W5.0mm_H2.0mm
LD2, LD3, LD4, LD5, LD6, LD7, LD8, LD9, LD10, LD11, LD12, LD13, LD14, LD15, LD16, LD17, LD18, LD19, LD20, LD21, LD22, LD23, LD24, LD25, LD26, LD27, LD28, LD29, LD30, LD31, LD32, LD33, LD34, LD35, LD36, LD37, LD38, LD39, LD40, LD41: LED; LED_Rectangular_W5.0mm_H2.0mm
R1, R2, R3: 1k; R_0603_1608Metric
R4, R5, R6, R7: 10k; R_0603_1608Metric
R8: 100k; R_0603_1608Metric
R9: Socket; R_Axial_DIN0207_L6.3mm_D2.5mm_P10.16mm_Horizontal
R10, R11: 100; R_0603_1608Metric
RN1, RN8: 1k; R_Array_SIP5
RN2: 10k; R_Array_SIP5
RN3, RN4, RN5, RN6: 1k; R_Array_SIP9
RN7: 10k; R_Array_SIP9
SW1: Bus_Open; SW_Slide-03_Wuerth-WS-SLTV_10x2.5x6.4_P2.54mm
SW2, SW3: SW_Push; SW_PUSH_6mm
SW4: SW_SPDT; SW_Slide-03_Wuerth-WS-SLTV_10x2.5x6.4_P2.54mm
TP1, TP2, TP3, TP4, TP5, TP6, TP7, TP8, TP9, TP10, TP11, TP12, TP13: TestPoint; TestPoint_THTPad_1.0x1.0mm_Drill0.5mm

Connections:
/ALU/ALU_OUT0: IC5.4 (S1), IC6.2 (I0a)
/ALU/ALU_OUT1: IC5.1 (S2), IC6.5 (I0b)
/ALU/ALU_OUT2: IC5.13 (S3), IC6.14 (I0c)
/ALU/ALU_OUT3: IC5.10 (S4), IC6.11 (I0d)
/ALU/ALU_in_A0: IC4.14 (S0), IC9.14 (QA), IC10.3 (D0), IC13.3 (A), IC15.10 (I1d), LD19.2
/ALU/ALU_in_A1: IC3.14 (S0), IC9.13 (QB), IC10.4 (D1), IC13.4 (B), IC15.13 (I1c), LD18.2
/ALU/ALU_in_A2: IC2.14 (S0), IC9.12 (QC), IC10.7 (D2), IC13.5 (C), IC15.6 (I1b), LD17.2
/ALU/ALU_in_A3: IC1.14 (S0), IC9.11 (QD), IC10.8 (D3), IC13.6 (D), IC15.3 (I1a), LD16.2
/ALU/ALU_in_B0: IC4.2 (S1), IC10.2 (Q0), IC10.18 (D7), IC12.3 (A), IC14.10 (I1d), LD15.2
/ALU/ALU_in_B1: IC3.2 (S1), IC10.5 (Q1), IC10.17 (D6), IC12.4 (B), IC14.13 (I1c), LD14.2
/ALU/ALU_in_B2: IC2.2 (S1), IC10.6 (Q2), IC10.14 (D5), IC12.5 (C), IC14.6 (I1b), LD13.2
/ALU/ALU_in_B3: IC1.2 (S1), IC10.9 (Q3), IC10.13 (D4), IC12.6 (D), IC14.3 (I1a), LD12.2
/ALU/Carry_IN: D13.2 (A_2), D14.2 (A), D15.2 (A), D16.2 (A), IC1.6 (I0a), IC2.6 (I0a), IC3.6 (I0a), IC4.6 (I0a), IC5.7 (C0), RN7.5 (R4.2), TP10.1 (1_1)
/ALU/Carry_OUT: IC5.9 (C4), IC20.12 (X0)
/ALU/I1a: IC1.5 (I1a), IC2.5 (I1a), IC3.5 (I1a), IC4.5 (I1a), IC8.1, TP11.1 (1_1)
/ALU/I2a: IC1.4 (I2a), IC2.4 (I2a), IC3.4 (I2a), IC4.4 (I2a), IC17.8, TP12.1 (1_1)
/ALU/I3a: IC1.3 (I3a), IC2.3 (I3a), IC3.3 (I3a), IC4.3 (I3a), IC17.11, TP13.1 (1_1)
/ALU/Internal_A0: IC4.7 (Za), IC5.5 (A1)
/ALU/Internal_A1: IC3.7 (Za), IC5.3 (A2)
/ALU/Internal_A2: IC2.7 (Za), IC5.14 (A3)
/ALU/Internal_A3: IC1.7 (Za), IC5.12 (A4)
/ALU/Internal_B0: IC4.9 (Zb), IC5.6 (B1)
/ALU/Internal_B1: IC3.9 (Zb), IC5.2 (B2)
/ALU/Internal_B2: IC2.9 (Zb), IC5.15 (B3)
/ALU/Internal_B3: IC1.9 (Zb), IC5.11 (B4)
/Address BUS/Instruction_0: IC7.2 (1A0), IC15.11 (I0d), IC21.11 (S0), J2.20
/Address BUS/Instruction_1: IC7.4 (1A1), IC15.14 (I0c), IC21.10 (S1), J2.19
/Address BUS/Instruction_2: IC7.6 (1A2), IC15.5 (I0b), IC21.9 (S2), J2.18
/Address BUS/Instruction_3: IC7.8 (1A3), IC15.2 (I0a), J2.17
/Address BUS/Instruction_4: D20.1 (K), D28.1 (K), IC17.12, IC18.11, J2.16, TP4.1 (1_1)
/Address BUS/Instruction_5: D3.1 (K), D7.1 (K), D15.1 (K), D23.1 (K), D31.1 (K), IC18.3, J2.15, TP3.1 (1_1)
/Address BUS/Instruction_6: D6.1 (K), D22.1 (K), D30.1 (K), IC18.13, J2.14, TP2.1 (1_1)
/Address BUS/Instruction_7: D5.1 (K), D33.1 (K), IC6.15 (OE), IC18.1, IC19.10, IC20.10 (B), J2.13, TP1.1 (1_1)
/Address BUS/MEMMode: D9.2 (A_2), D10.2 (A), D11.2 (A), D12.2 (A), IC14.1 (S), IC15.1 (S), RN7.4 (R3.2)
/Address BUS/RAM_A0: IC15.9 (Zd), J3.11, LD39.2
/Address BUS/RAM_A1: IC15.12 (Zc), J3.12, LD38.2
/Address BUS/RAM_A2: IC15.7 (Zb), J3.13, LD37.2
/Address BUS/RAM_A3: IC15.4 (Za), J3.14, LD36.2
/Address BUS/RAM_A4: IC14.9 (Zd), J3.15, LD35.2
/Address BUS/RAM_A5: IC14.12 (Zc), J3.16, LD34.2
/Address BUS/RAM_A6: IC14.7 (Zb), J3.17, LD33.2
/Address BUS/RAM_A7: IC14.4 (Za), J3.18, LD32.2
/Data BUS/BUS_Zero: IC8.13, IC20.2 (Y0)
/Data BUS/Databus0: IC6.4 (Za), IC7.17 (2A0), IC7.18 (1Y0), IC8.12, IC9.3 (A), J3.3, RN2.2 (R1.2)
/Data BUS/Databus1: IC6.7 (Zb), IC7.15 (2A1), IC7.16 (1Y1), IC8.11, IC9.4 (B), J3.4, RN2.3 (R2.2)
/Data BUS/Databus2: IC6.12 (Zc), IC7.13 (2A2), IC7.14 (1Y2), IC8.10, IC9.5 (C), J3.5, RN2.4 (R3.2)
/Data BUS/Databus3: IC6.9 (Zd), IC7.11 (2A3), IC7.12 (1Y3), IC8.9, IC9.6 (D), J3.6, RN2.5 (R4.2)
/Data BUS/Level_C0: IC6.3 (I1a), IC10.19 (Q7), IC11.3 (A), LD11.2
/Data BUS/Level_C1: IC6.6 (I1b), IC10.16 (Q6), IC11.4 (B), LD10.2
/Data BUS/Level_C2: IC6.13 (I1c), IC10.15 (Q5), IC11.5 (C), LD9.2
/Data BUS/Level_C3: IC6.10 (I1d), IC10.12 (Q4), IC11.6 (D), LD8.2
/Data BUS/Level_C_OE: D37.2 (A_2), D38.2 (A), D39.2 (A), D40.2 (A_2), IC6.1 (S), R6.2
/Data BUS/~Immediate_OE: IC7.1 (1OE), IC19.8, TP7.1 (1_1)
/Data BUS/~RD: IC19.3, J3.1
/Data BUS/~WR: IC19.6, J3.2
/Instruction Decoder/Carry_Flg: IC16.9 (Q), IC20.13 (X1), IC21.2 (I2), R3.1
/Instruction Decoder/READ: D33.2 (A), D34.2 (A), D35.2 (A), D36.2 (A_2), IC19.1, R5.2
/Instruction Decoder/Zero_Flg: IC16.5 (Q), IC20.1 (Y1), IC21.15 (I4), R2.1
/Instruction Decoder/~Carry_EN: IC1.15 (Eb), IC2.15 (Eb), IC3.15 (Eb), IC4.15 (Eb), IC19.11, IC20.11 (A), TP5.1 (1_1)
/Instruction Decoder/~Carry_Flg: IC16.8 (~Q), IC21.1 (I3)
/Instruction Decoder/~JMP: IC11.9 (/LOAD), IC12.9 (/LOAD), IC13.9 (/LOAD), IC21.6 (~Z), TP6.1 (1_1)
/Instruction Decoder/~STACK_LE: IC9.9 (/LOAD), IC10.1 (~E), IC17.6, TP9.1 (1_1)
/Instruction Decoder/~Zero_Flg: IC16.6 (~Q), IC21.14 (I5)
/Instruction Decoder/~i4: D12.1 (K), D16.1 (K), D24.1 (K), IC18.10
/Instruction Decoder/~i5: D11.1 (K), D35.1 (K), D39.1 (K), IC17.9, IC18.4
/Instruction Decoder/~i6: D2.1 (K), D10.1 (K), D14.1 (K), D18.1 (K), D26.1 (K), D34.1 (K), D38.1 (K), IC18.12
/Instruction Decoder/~i7: IC17.4, IC18.2, IC19.4, IC19.13
/Instruction Decoder/~is_JP_inst: IC18.6, IC21.7 (~E), TP8.1 (1_1)
/Program Counter/PC_0: IC13.14 (QA), J2.1, LD22.2
/Program Counter/PC_1: IC13.13 (QB), J2.2, LD25.2
/Program Counter/PC_2: IC13.12 (QC), J2.3, LD28.2
/Program Counter/PC_3: IC13.11 (QD), J2.4, LD31.2
/Program Counter/PC_4: IC12.14 (QA), J2.5, LD21.2
/Program Counter/PC_5: IC12.13 (QB), J2.6, LD24.2
/Program Counter/PC_6: IC12.12 (QC), J2.7, LD27.2
/Program Counter/PC_7: IC12.11 (QD), J2.8, LD30.2
/Program Counter/PC_8: IC11.14 (QA), J2.9, LD20.2
/Program Counter/PC_9: IC11.13 (QB), J2.10, LD23.2
/Program Counter/PC_10: IC11.12 (QC), J2.11, LD26.2
/Program Counter/PC_11: IC11.11 (QD), J2.12, LD29.2
CLK: IC9.2 (CK), IC10.11 (CP), IC11.2 (CK), IC12.2 (CK), IC13.2 (CK), IC16.3 (C), IC16.11 (C), LD40.1 (K_1), R11.2
CLK2: IC19.2, IC19.5, IC22.13, J3.28, R10.2
GND: C1.2, C2.2, C3.2, CP1.2, CP2.2, CP3.2, CP4.2, CP5.2, CP6.2, CP7.2, CP8.2, CP9.2, CP10.2, CP11.2, CP12.2, CP13.2, CP14.2, CP15.2, CP16.2, CP17.2, CP18.2, CP19.2, CP20.2, CP21.2, CP22.2, IC1.1 (Ea), IC1.8 (GND), IC1.10 (I0b), IC1.12 (I2b), IC2.1 (Ea), IC2.8 (GND), IC2.10 (I0b), IC2.12 (I2b), IC3.1 (Ea), IC3.8 (GND), IC3.10 (I0b), IC3.12 (I2b), IC4.1 (Ea), IC4.8 (GND), IC4.10 (I0b), IC4.12 (I2b), IC5.8 (GND), IC6.8 (GND), IC7.10 (GND), IC7.19 (2OE), IC8.7 (VSS), IC9.7 (ENP), IC9.8 (GND), IC9.10 (ENT), IC10.10 (GND), IC11.8 (GND), IC12.8 (GND), IC13.8 (GND), IC14.2 (I0a), IC14.5 (I0b), IC14.8 (GND), IC14.11 (I0d), IC14.14 (I0c), IC15.8 (GND), IC16.7 (GND), IC17.7 (GND), IC18.7 (GND), IC19.7 (GND), IC20.6 (Inh), IC20.7 (VEE), IC20.8 (VSS), IC20.9 (C), IC21.3 (I1), IC21.8 (GND), IC21.12 (I7), IC21.13 (I6), IC22.7 (GND), J1.2, J2.22, J2.23, J2.24, J3.40, LD2.1 (K_1), LD3.1 (K_1), R1.2, R4.2, RN1.2 (R1.2), RN1.3 (R2.2), RN1.4 (R3.2), RN1.5 (R4.2), RN3.1 (R1), RN4.1 (R1), RN5.1 (R1), RN6.1 (R1), SW2.1, SW3.1
unnamed: C2.1, IC22.11, R7.2
unnamed: C3.1, IC22.5, R8.2
unnamed: D1.2 (A_2), D2.2 (A), D3.2 (A), D4.2 (A_2), IC19.9, IC19.12, RN7.2 (R1.2)
unnamed: D5.2 (A), D6.2 (A), D7.2 (A), D8.2 (A_2), IC17.5, IC18.5, RN7.3 (R2.2)
unnamed: D17.2 (A_2), D18.2 (A), D19.2 (A_2), D20.2 (A), IC8.2, IC8.3, RN7.6 (R5.2)
unnamed: D21.2 (A_2), D22.2 (A), D23.2 (A), D24.2 (A), IC8.4, IC8.5, RN7.7 (R6.2)
unnamed: D25.2 (A_2), D26.2 (A), D27.2 (A_2), D28.2 (A), IC17.10, RN7.8 (R7.2)
unnamed: D29.2 (A_2), D30.2 (A), D31.2 (A), D32.2 (A_2), IC17.13, RN7.9 (R8.2)
unnamed: C4.1, D41.2 (A), IC22.1, R9.1
unnamed: F1.1, J1.1
unnamed: IC7.3 (2Y0), LD7.2
unnamed: IC7.5 (2Y1), LD6.2
unnamed: IC7.7 (2Y2), LD5.2
unnamed: IC7.9 (2Y3), LD4.2
unnamed: IC11.10 (ENT), IC12.15 (CO)
unnamed: IC12.10 (ENT), IC13.15 (CO)
unnamed: IC14.15 (OE), IC15.15 (OE), R4.1, SW1.1 (B)
unnamed: IC16.2 (D), IC20.15 (Y)
unnamed: IC16.12 (D), IC20.14 (X)
unnamed: IC22.2, IC22.3, R9.2
unnamed: IC22.6, IC22.9
unnamed: IC22.12, R11.1
unnamed: LD1.1 (K_1), R1.1
unnamed: LD2.2, R2.2
unnamed: LD3.2, R3.2
unnamed: LD4.1 (K_1), RN1.1 (R1)
unnamed: LD8.1 (K_1), RN3.2 (R1.2)
unnamed: LD9.1 (K_1), RN3.3 (R2.2)
unnamed: LD10.1 (K_1), RN3.4 (R3.2)
unnamed: LD11.1 (K_1), RN3.5 (R4.2)
unnamed: LD12.1 (K_1), RN3.6 (R5.2)
unnamed: LD13.1 (K_1), RN3.7 (R6.2)
unnamed: LD14.1 (K_1), RN3.8 (R7.2)
unnamed: LD15.1 (K_1), RN3.9 (R8.2)
unnamed: LD16.1 (K_1), RN4.2 (R1.2)
unnamed: LD17.1 (K_1), RN4.3 (R2.2)
unnamed: LD18.1 (K_1), RN4.4 (R3.2)
unnamed: LD19.1 (K_1), RN4.5 (R4.2)
unnamed: LD20.1 (K_1), RN4.9 (R8.2)
unnamed: LD21.1 (K_1), RN5.5 (R4.2)
unnamed: LD22.1 (K_1), RN5.9 (R8.2)
unnamed: LD23.1 (K_1), RN4.8 (R7.2)
unnamed: LD24.1 (K_1), RN5.4 (R3.2)
unnamed: LD25.1 (K_1), RN5.8 (R7.2)
unnamed: LD26.1 (K_1), RN4.7 (R6.2)
unnamed: LD27.1 (K_1), RN5.3 (R2.2)
unnamed: LD28.1 (K_1), RN5.7 (R6.2)
unnamed: LD29.1 (K_1), RN4.6 (R5.2)
unnamed: LD30.1 (K_1), RN5.2 (R1.2)
unnamed: LD31.1 (K_1), RN5.6 (R5.2)
unnamed: LD32.1 (K_1), RN6.2 (R1.2)
unnamed: LD33.1 (K_1), RN6.3 (R2.2)
unnamed: LD34.1 (K_1), RN6.4 (R3.2)
unnamed: LD35.1 (K_1), RN6.5 (R4.2)
unnamed: LD36.1 (K_1), RN6.6 (R5.2)
unnamed: LD37.1 (K_1), RN6.7 (R6.2)
unnamed: LD38.1 (K_1), RN6.8 (R7.2)
unnamed: LD39.1 (K_1), RN6.9 (R8.2)
unnamed: R7.1, RN8.2 (R1.2), SW2.2
unnamed: R8.1, RN8.3 (R2.2), SW3.2
unnamed: LD40.2, RN8.4 (R3.2)
unnamed: LD41.2, RN8.5 (R4.2)
unnamed: C4.2, IC22.4, SW4.3 (A)
unnamed: R10.1, SW4.1 (B)
unnamed: IC22.10, SW4.2 (C)
VCC: C1.1, CP1.1, CP2.1, CP3.1, CP4.1, CP5.1, CP6.1, CP7.1, CP8.1, CP9.1, CP10.1, CP11.1, CP12.1, CP13.1, CP14.1, CP15.1, CP16.1, CP17.1, CP18.1, CP19.1, CP20.1, CP21.1, CP22.1, F1.2, IC1.11 (I1b), IC1.13 (I3b), IC1.16 (VCC), IC2.11 (I1b), IC2.13 (I3b), IC2.16 (VCC), IC3.11 (I1b), IC3.13 (I3b), IC3.16 (VCC), IC4.11 (I1b), IC4.13 (I3b), IC4.16 (VCC), IC5.16 (VCC), IC6.16 (VCC), IC7.20 (VCC), IC8.14 (VDD), IC9.16 (VCC), IC10.20 (VCC), IC11.7 (ENP), IC11.16 (VCC), IC12.7 (ENP), IC12.16 (VCC), IC13.7 (ENP), IC13.10 (ENT), IC13.16 (VCC), IC14.16 (VCC), IC15.16 (VCC), IC16.4 (~S), IC16.10 (~S), IC16.14 (VCC), IC17.1, IC17.2, IC17.14 (VCC), IC18.9, IC18.14 (VCC), IC19.14 (VCC), IC20.16 (VDD), IC21.4 (I0), IC21.16 (VCC), IC22.14 (VCC), J2.21, J3.39, LD1.2, R5.1, R6.1, RN2.1 (R1), RN7.1 (R1), RN8.1 (R1), SW1.3 (A)
~RESET: D41.1 (K), IC9.1 (/CLR), IC11.1 (/CLR), IC12.1 (/CLR), IC13.1 (/CLR), IC16.1 (~R), IC16.13 (~R), IC22.8, J3.30, LD41.1 (K_1)

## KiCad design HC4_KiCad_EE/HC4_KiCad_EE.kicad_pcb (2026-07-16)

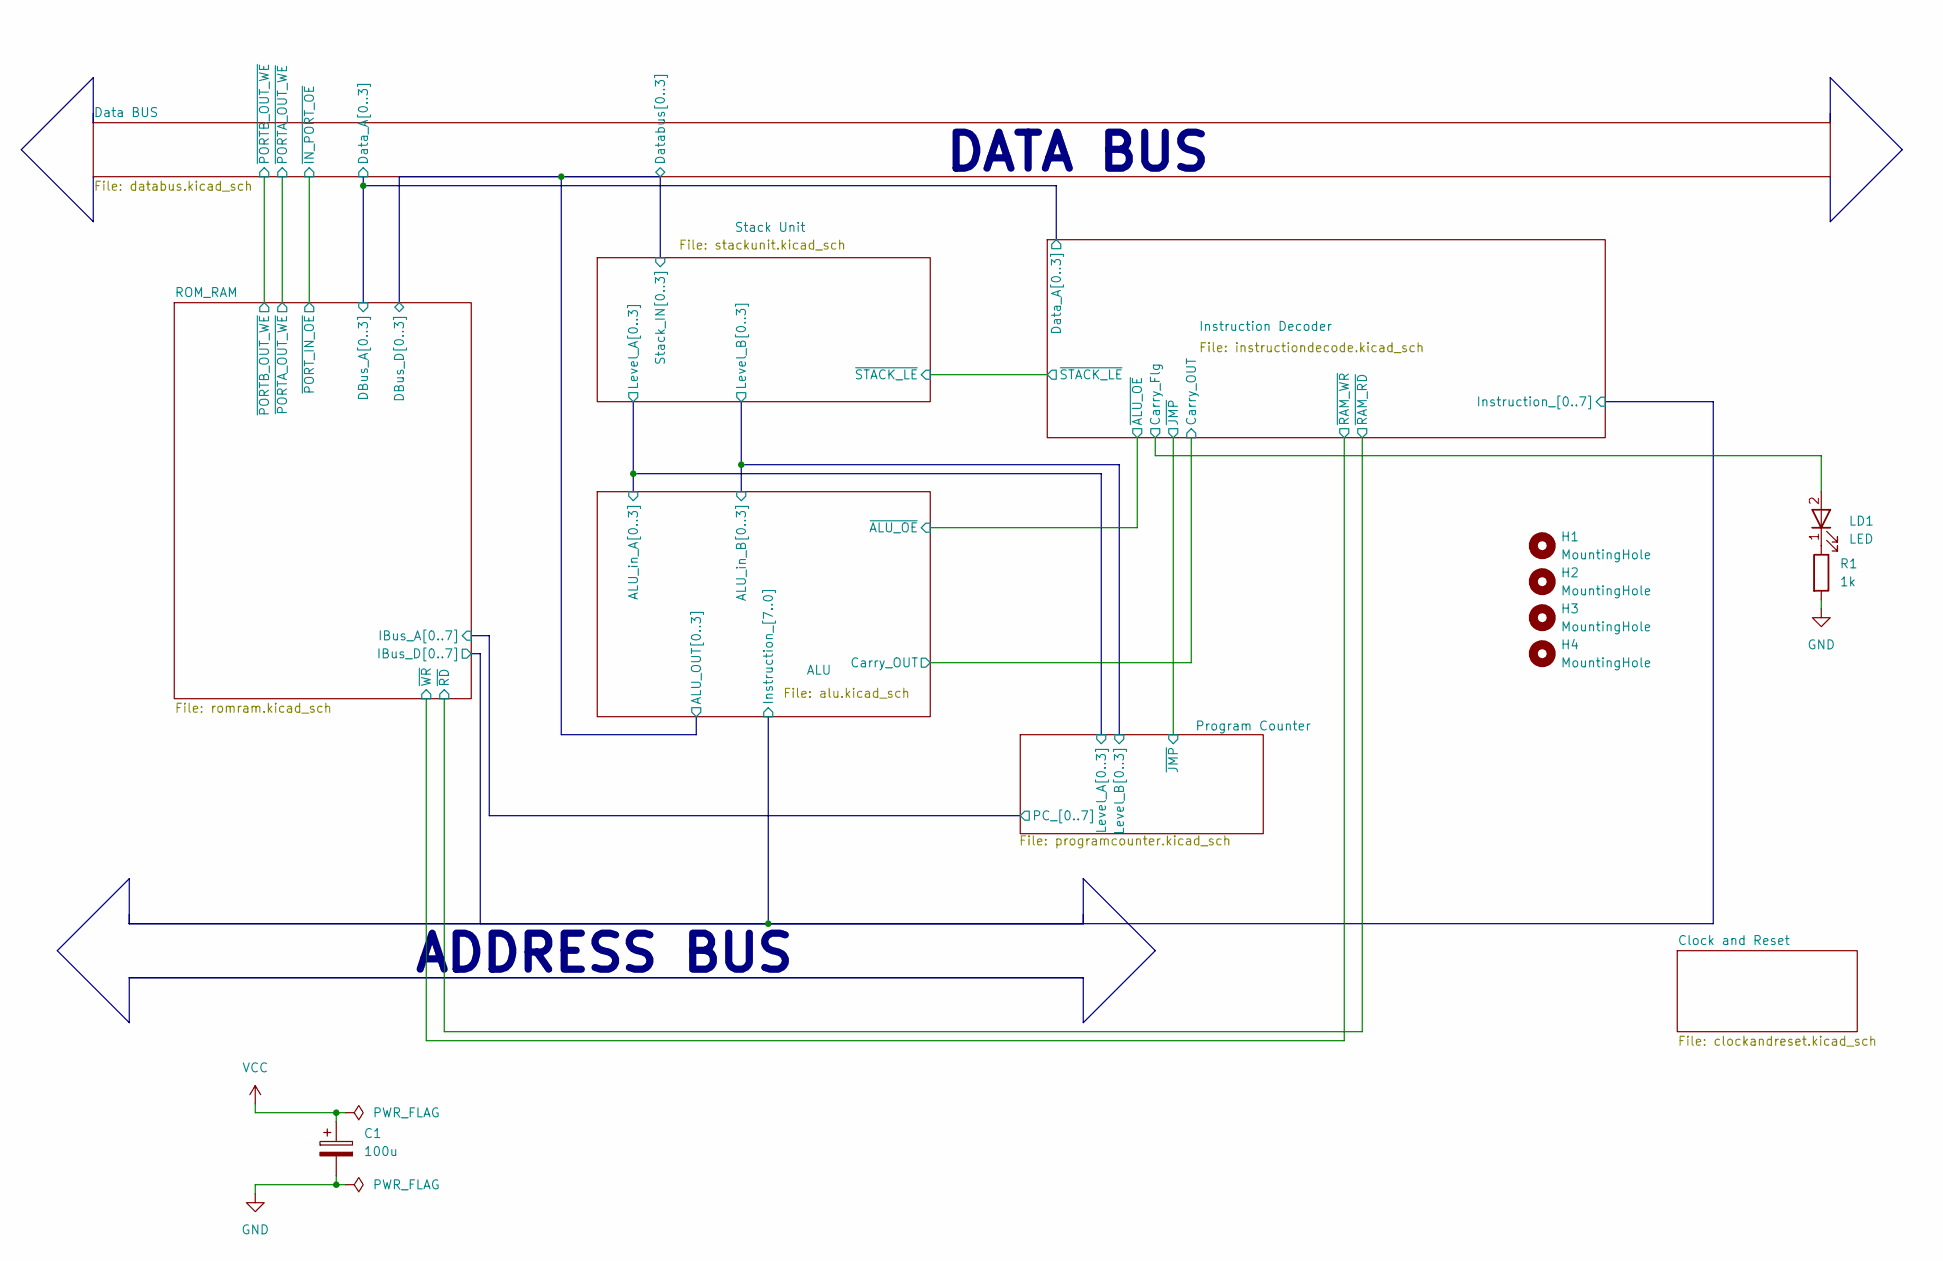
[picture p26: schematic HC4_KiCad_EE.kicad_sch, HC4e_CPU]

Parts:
C1: 100u; CP_Radial_D5.0mm_P2.50mm
H1, H2, H3, H4: MountingHole; MountingHole_3.2mm_M3
LD1: LED; LED_Rectangular_W5.0mm_H2.0mm
R1: 1k; R_0603_1608Metric; LCSC PN C21190

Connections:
/Instruction Decoder/Carry_Flg: LD1.2; also elsewhere on the board
GND: C1.2, R1.2; also elsewhere on the board
unnamed: LD1.1 (K_1), R1.1
VCC: C1.1; also elsewhere on the board

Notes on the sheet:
ADDRESS BUS
DATA BUS

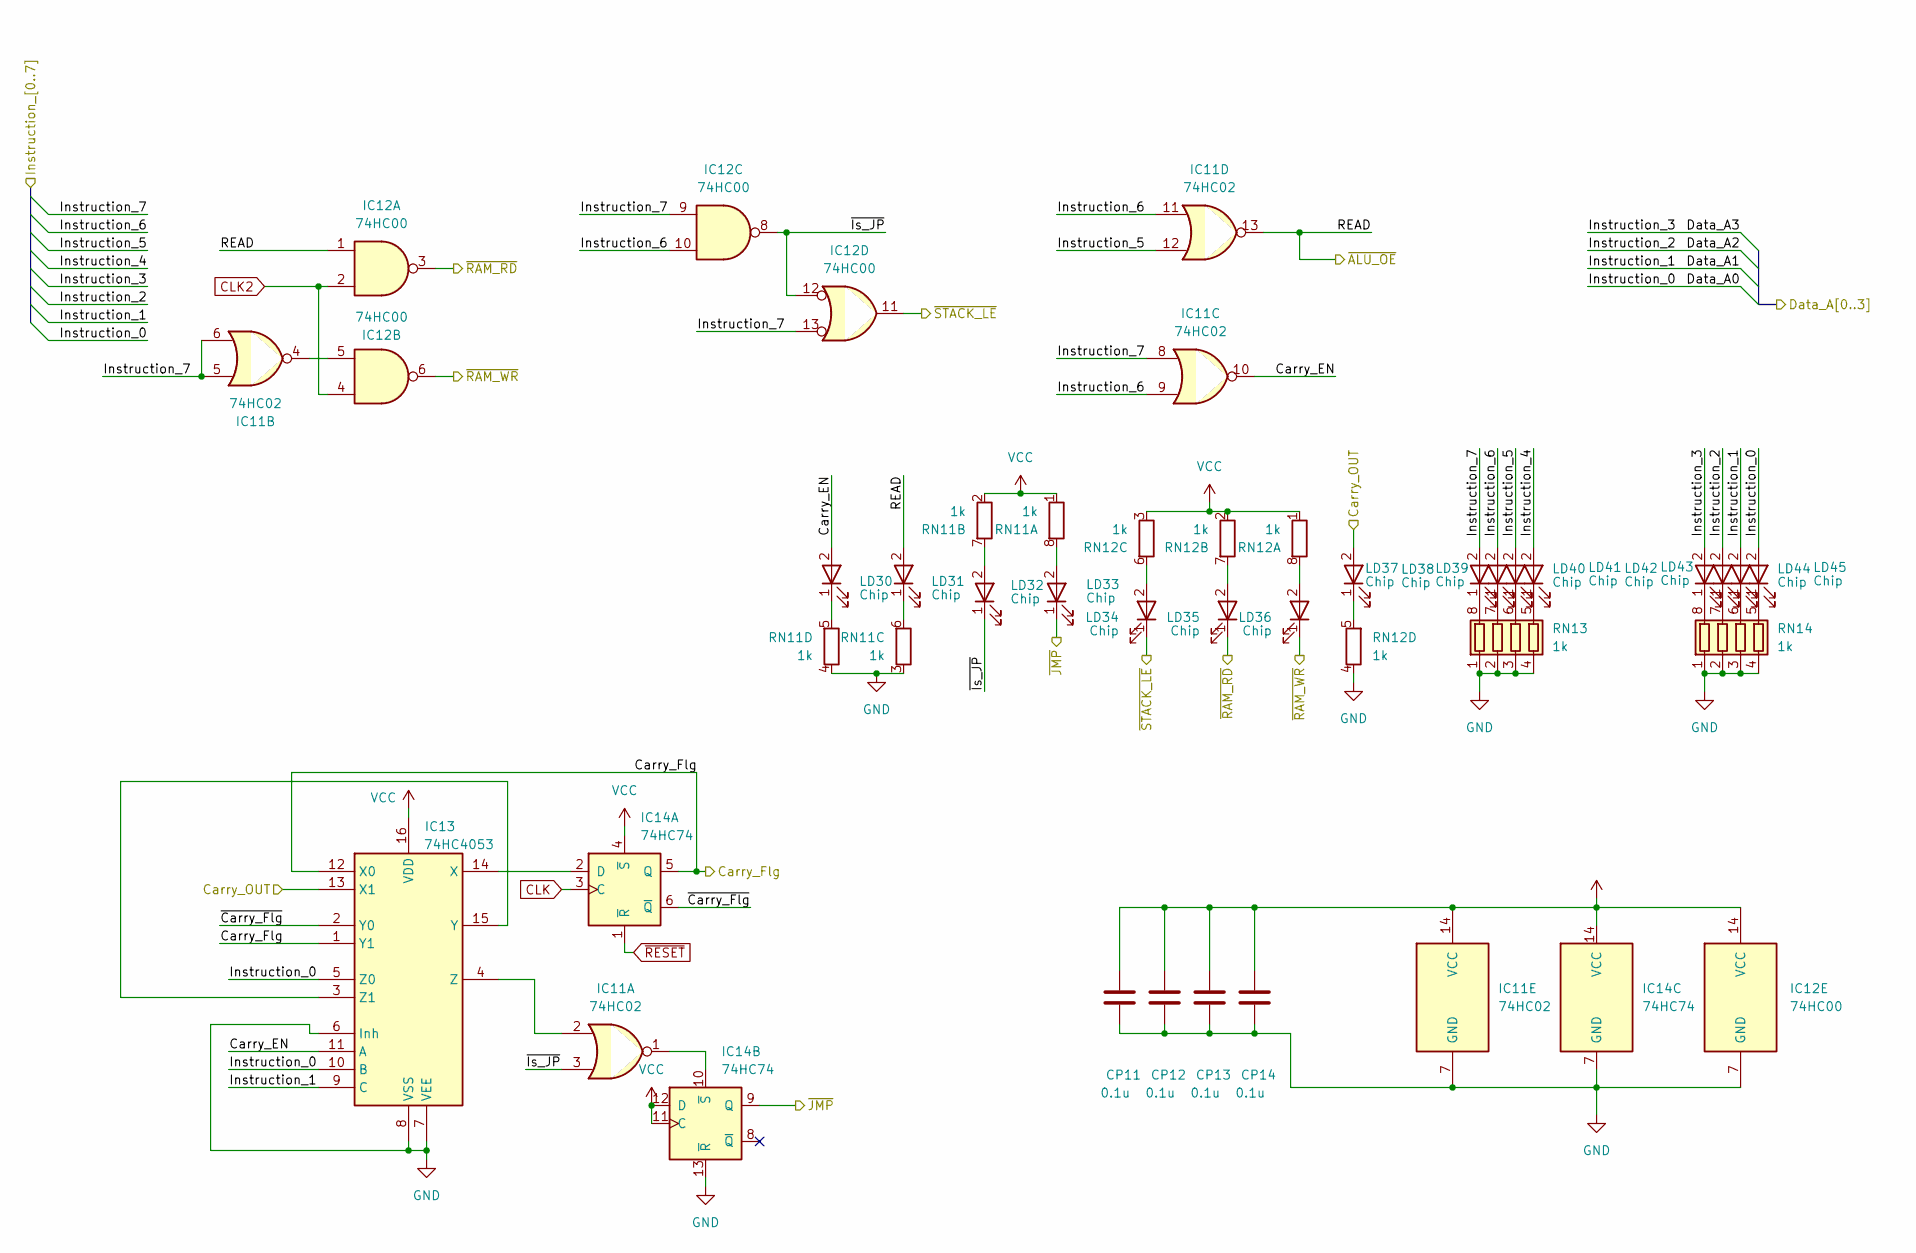
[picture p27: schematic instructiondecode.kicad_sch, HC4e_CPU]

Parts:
CP11, CP12, CP13, CP14: 0.1u; C_0603_1608Metric; LCSC PN C14663
IC11: 74HC02; SO-14_5.3x10.2mm_P1.27mm
IC12: 74HC00; SO-14_5.3x10.2mm_P1.27mm
IC13: 74HC4053; SO-16_5.3x10.2mm_P1.27mm
IC14: 74HC74; SO-14_5.3x10.2mm_P1.27mm
LD30, LD31, LD32, LD33, LD34, LD35, LD36, LD37, LD38, LD39, LD40, LD41, LD42, LD43, LD44, LD45: Chip; LED_0603_1608Metric; LCSC PN C2289
RN11, RN12, RN13, RN14: 1k; R_Array_Convex_4x0603; LCSC PN C20197

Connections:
/ALU/Carry_OUT: IC13.13 (X1), LD37.2; also elsewhere on the board
/ALU/Instruction_4: LD41.2; also elsewhere on the board
/ALU/Instruction_5: IC11.12, LD40.2; also elsewhere on the board
/ALU/Instruction_6: IC11.9, IC11.11, IC12.10, LD39.2; also elsewhere on the board
/ALU/Instruction_7: IC11.5, IC11.6, IC11.8, IC12.9, IC12.13, LD38.2; also elsewhere on the board
/Instruction Decoder/Carry_EN: IC11.10, IC13.11 (A), LD30.2
/Instruction Decoder/Carry_Flg: IC13.1 (Y1), IC13.12 (X0), IC14.5 (Q); also elsewhere on the board
/Instruction Decoder/READ: IC11.13, IC12.1, LD31.2; also elsewhere on the board
/Instruction Decoder/~Carry_Flg: IC13.2 (Y0), IC14.6 (~Q)
/Instruction Decoder/~Is_JP: IC11.3, IC12.8, IC12.12, LD32.1 (K_1)
/Instruction Decoder/~JMP: IC14.9 (Q), LD33.1 (K_1); also elsewhere on the board
/Instruction Decoder/~RAM_RD: IC12.3, LD35.1 (K_1); also elsewhere on the board
/Instruction Decoder/~RAM_WR: IC12.6, LD36.1 (K_1); also elsewhere on the board
/Instruction Decoder/~STACK_LE: IC12.11, LD34.1 (K_1); also elsewhere on the board
CLK: IC14.3 (C); also elsewhere on the board
CLK2: IC12.2, IC12.4; also elsewhere on the board
GND: CP11.2, CP12.2, CP13.2, CP14.2, IC11.7 (GND), IC12.7 (GND), IC13.6 (Inh), IC13.7 (VEE), IC13.8 (VSS), IC14.7 (GND), IC14.13 (~R), RN11.3 (R3.1), RN11.4 (R4.1), RN12.4 (R4.1), RN13.1 (R1.1), RN13.2 (R2.1), RN13.3 (R3.1), RN13.4 (R4.1), RN14.1 (R1.1), RN14.2 (R2.1), RN14.3 (R3.1), RN14.4 (R4.1); also elsewhere on the board
unnamed: IC11.4, IC12.5
unnamed: IC13.14 (X), IC14.2 (D)
unnamed: IC13.3 (Z1), IC13.15 (Y)
unnamed: IC11.2, IC13.4 (Z)
unnamed: IC11.1, IC14.10 (~S)
unnamed: LD30.1 (K_1), RN11.5 (R4.2)
unnamed: LD31.1 (K_1), RN11.6 (R3.2)
unnamed: LD37.1 (K_1), RN12.5 (R4.2)
unnamed: LD38.1 (K_1), RN13.8 (R1.2)
unnamed: LD39.1 (K_1), RN13.7 (R2.2)
unnamed: LD40.1 (K_1), RN13.6 (R3.2)
unnamed: LD41.1 (K_1), RN13.5 (R4.2)
unnamed: LD42.1 (K_1), RN14.8 (R1.2)
unnamed: LD43.1 (K_1), RN14.7 (R2.2)
unnamed: LD44.1 (K_1), RN14.6 (R3.2)
unnamed: LD45.1 (K_1), RN14.5 (R4.2)
unnamed: LD33.2, RN11.8 (R1.2)
unnamed: LD32.2, RN11.7 (R2.2)
unnamed: LD36.2, RN12.8 (R1.2)
unnamed: LD35.2, RN12.7 (R2.2)
unnamed: LD34.2, RN12.6 (R3.2)
VCC: CP11.1, CP12.1, CP13.1, CP14.1, IC11.14 (VCC), IC12.14 (VCC), IC13.16 (VDD), IC14.4 (~S), IC14.11 (C), IC14.12 (D), IC14.14 (VCC), RN11.1 (R1.1), RN11.2 (R2.1), RN12.1 (R1.1), RN12.2 (R2.1), RN12.3 (R3.1); also elsewhere on the board
~RESET: IC14.1 (~R); also elsewhere on the board

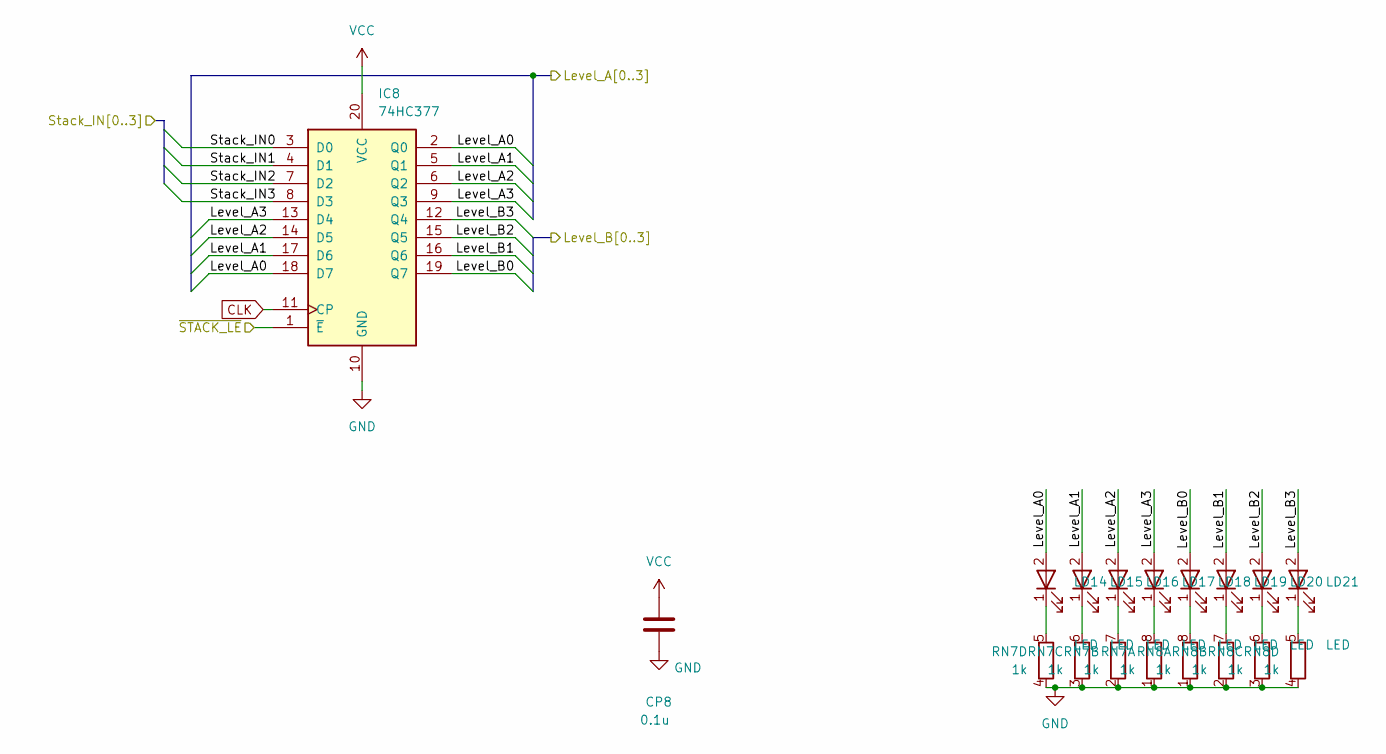
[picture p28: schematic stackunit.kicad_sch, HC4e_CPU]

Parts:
CP8: 0.1u; C_0603_1608Metric; LCSC PN C14663
IC8: 74HC377; SOIC-20W_7.5x12.8mm_P1.27mm
LD14, LD15, LD16, LD17, LD18, LD19, LD20, LD21: LED; LED_Rectangular_W5.0mm_H2.0mm
RN7, RN8: 1k; R_Array_Convex_4x0603; LCSC PN C20197

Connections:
/ALU/ALU_OUT0: IC8.3 (D0); also elsewhere on the board
/ALU/ALU_OUT1: IC8.4 (D1); also elsewhere on the board
/ALU/ALU_OUT2: IC8.7 (D2); also elsewhere on the board
/ALU/ALU_OUT3: IC8.8 (D3); also elsewhere on the board
/ALU/ALU_in_A0: IC8.2 (Q0), IC8.18 (D7), LD14.2; also elsewhere on the board
/ALU/ALU_in_A1: IC8.5 (Q1), IC8.17 (D6), LD15.2; also elsewhere on the board
/ALU/ALU_in_A2: IC8.6 (Q2), IC8.14 (D5), LD16.2; also elsewhere on the board
/ALU/ALU_in_A3: IC8.9 (Q3), IC8.13 (D4), LD17.2; also elsewhere on the board
/ALU/ALU_in_B0: IC8.19 (Q7), LD18.2; also elsewhere on the board
/ALU/ALU_in_B1: IC8.16 (Q6), LD19.2; also elsewhere on the board
/ALU/ALU_in_B2: IC8.15 (Q5), LD20.2; also elsewhere on the board
/ALU/ALU_in_B3: IC8.12 (Q4), LD21.2; also elsewhere on the board
/Instruction Decoder/~STACK_LE: IC8.1 (~E); also elsewhere on the board
CLK: IC8.11 (CP); also elsewhere on the board
GND: CP8.2, IC8.10 (GND), RN7.1 (R1.1), RN7.2 (R2.1), RN7.3 (R3.1), RN7.4 (R4.1), RN8.1 (R1.1), RN8.2 (R2.1), RN8.3 (R3.1), RN8.4 (R4.1); also elsewhere on the board
unnamed: LD14.1 (K_1), RN7.5 (R4.2)
unnamed: LD15.1 (K_1), RN7.6 (R3.2)
unnamed: LD16.1 (K_1), RN7.7 (R2.2)
unnamed: LD17.1 (K_1), RN7.8 (R1.2)
unnamed: LD18.1 (K_1), RN8.8 (R1.2)
unnamed: LD19.1 (K_1), RN8.7 (R2.2)
unnamed: LD20.1 (K_1), RN8.6 (R3.2)
unnamed: LD21.1 (K_1), RN8.5 (R4.2)
VCC: CP8.1, IC8.20 (VCC); also elsewhere on the board

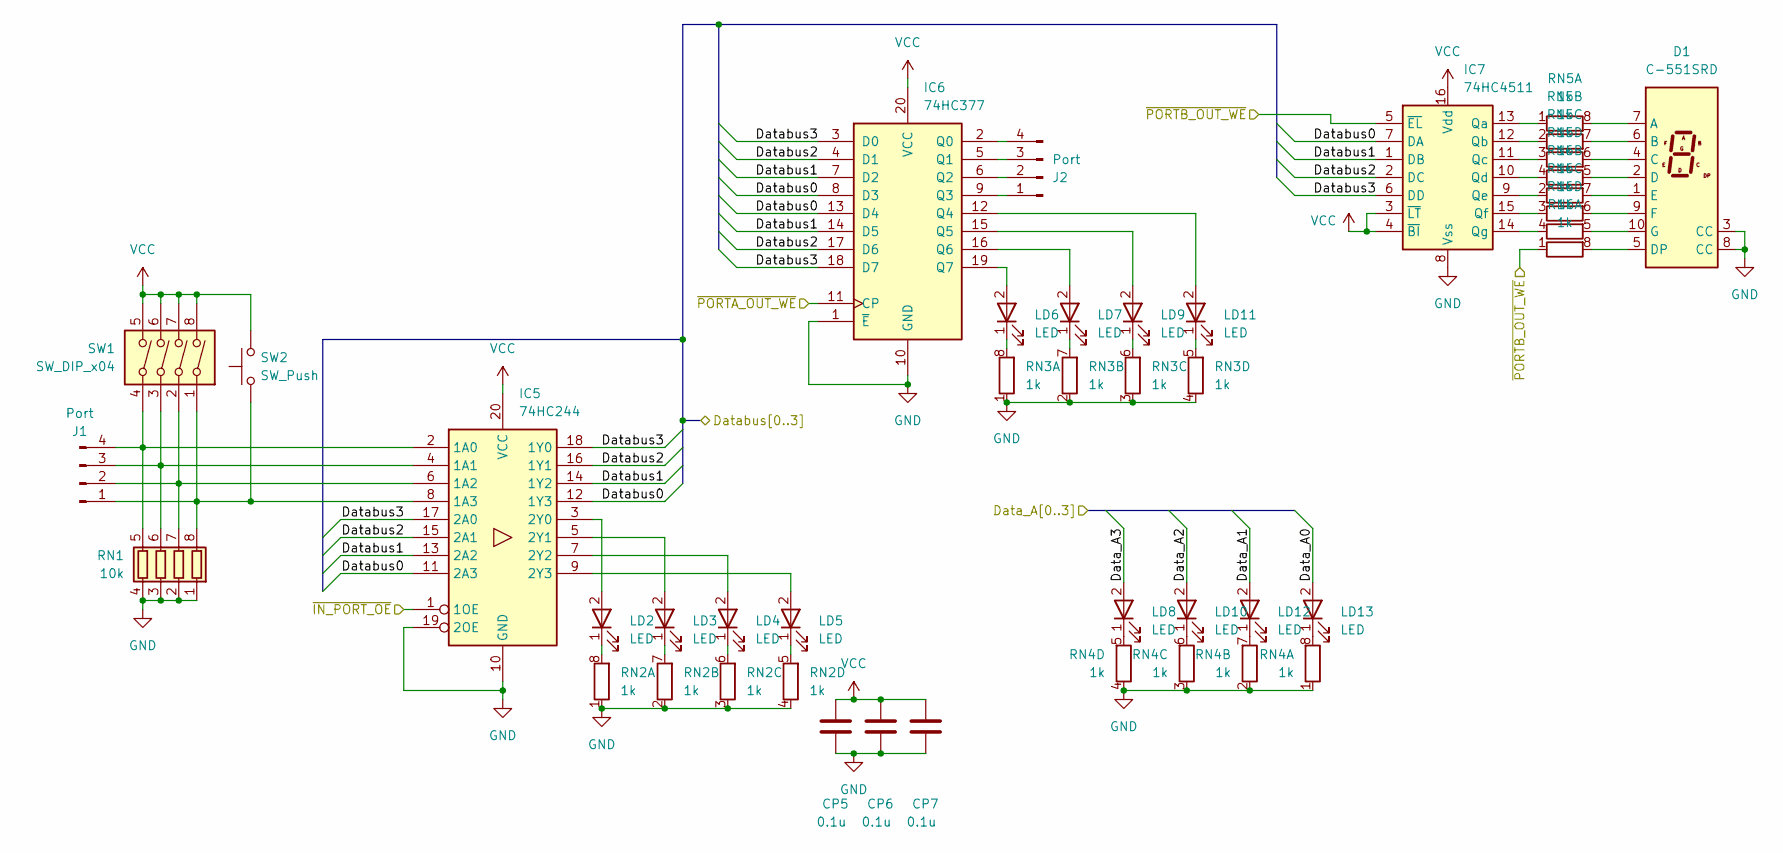
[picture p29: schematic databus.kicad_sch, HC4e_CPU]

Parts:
CP5, CP6, CP7: 0.1u; C_0603_1608Metric; LCSC PN C14663
D1: C-551SRD; D1X8K
IC5: 74HC244; SOIC-20W_7.5x12.8mm_P1.27mm
IC6: 74HC377; SOIC-20W_7.5x12.8mm_P1.27mm
IC7: 74HC4511; SO-16_5.3x10.2mm_P1.27mm
J1, J2: Port; PinHeader_1x04_P2.54mm_Vertical
LD2, LD3, LD4, LD5, LD6, LD7, LD8, LD9, LD10, LD11, LD12, LD13: LED; LED_Rectangular_W5.0mm_H2.0mm
RN1: 10k; R_Array_Convex_4x0603; LCSC PN C29718
RN2, RN3, RN4, RN5, RN6: 1k; R_Array_Convex_4x0603; LCSC PN C20197
SW1: SW_DIP_x04; SW_DIP_SPSTx04_Slide_9.78x12.34mm_W7.62mm_P2.54mm
SW2: SW_Push; SW_PUSH_6mm

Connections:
/ALU/ALU_OUT0: IC5.11 (2A3), IC5.12 (1Y3), IC6.8 (D3), IC6.13 (D4), IC7.7 (DA); also elsewhere on the board
/ALU/ALU_OUT1: IC5.13 (2A2), IC5.14 (1Y2), IC6.7 (D2), IC6.14 (D5), IC7.1 (DB); also elsewhere on the board
/ALU/ALU_OUT2: IC5.15 (2A1), IC5.16 (1Y1), IC6.4 (D1), IC6.17 (D6), IC7.2 (DC); also elsewhere on the board
/ALU/ALU_OUT3: IC5.17 (2A0), IC5.18 (1Y0), IC6.3 (D0), IC6.18 (D7), IC7.6 (DD); also elsewhere on the board
/Data BUS/~IN_PORT_OE: IC5.1 (1OE); also elsewhere on the board
/Data BUS/~PORTA_OUT_WE: IC6.11 (CP); also elsewhere on the board
/Data BUS/~PORTB_OUT_WE: IC7.5 (~EL), RN6.1 (R1.1); also elsewhere on the board
GND: CP5.2, CP6.2, CP7.2, D1.3 (CC), D1.8 (CC), IC5.10 (GND), IC5.19 (2OE), IC6.1 (~E), IC6.10 (GND), IC7.8 (Vss), RN1.1 (R1.1), RN1.2 (R2.1), RN1.3 (R3.1), RN1.4 (R4.1), RN2.1 (R1.1), RN2.2 (R2.1), RN2.3 (R3.1), RN2.4 (R4.1), RN3.1 (R1.1), RN3.2 (R2.1), RN3.3 (R3.1), RN3.4 (R4.1), RN4.1 (R1.1), RN4.2 (R2.1), RN4.3 (R3.1), RN4.4 (R4.1); also elsewhere on the board
unnamed: D1.7 (A), RN5.8 (R1.2)
unnamed: D1.6 (B), RN5.7 (R2.2)
unnamed: D1.4 (C), RN5.6 (R3.2)
unnamed: D1.2 (D), RN5.5 (R4.2)
unnamed: D1.5 (DP), RN6.8 (R1.2)
unnamed: D1.1 (E), RN6.7 (R2.2)
unnamed: D1.9 (F), RN6.6 (R3.2)
unnamed: D1.10 (G), RN6.5 (R4.2)
unnamed: IC5.2 (1A0), J1.4, RN1.5 (R4.2), SW1.4
unnamed: IC5.4 (1A1), J1.3, RN1.6 (R3.2), SW1.3
unnamed: IC5.6 (1A2), J1.2, RN1.7 (R2.2), SW1.2
unnamed: IC5.8 (1A3), J1.1, RN1.8 (R1.2), SW1.1, SW2.1
unnamed: IC5.3 (2Y0), LD2.2
unnamed: IC5.5 (2Y1), LD3.2
unnamed: IC5.7 (2Y2), LD4.2
unnamed: IC5.9 (2Y3), LD5.2
unnamed: IC6.2 (Q0), J2.4
unnamed: IC6.5 (Q1), J2.3
unnamed: IC6.6 (Q2), J2.2
unnamed: IC6.9 (Q3), J2.1
unnamed: IC6.12 (Q4), LD11.2
unnamed: IC6.15 (Q5), LD9.2
unnamed: IC6.16 (Q6), LD7.2
unnamed: IC6.19 (Q7), LD6.2
unnamed: IC7.13 (Qa), RN5.1 (R1.1)
unnamed: IC7.12 (Qb), RN5.2 (R2.1)
unnamed: IC7.11 (Qc), RN5.3 (R3.1)
unnamed: IC7.10 (Qd), RN5.4 (R4.1)
unnamed: IC7.9 (Qe), RN6.2 (R2.1)
unnamed: IC7.15 (Qf), RN6.3 (R3.1)
unnamed: IC7.14 (Qg), RN6.4 (R4.1)
unnamed: LD2.1 (K_1), RN2.8 (R1.2)
unnamed: LD3.1 (K_1), RN2.7 (R2.2)
unnamed: LD4.1 (K_1), RN2.6 (R3.2)
unnamed: LD5.1 (K_1), RN2.5 (R4.2)
unnamed: LD6.1 (K_1), RN3.8 (R1.2)
unnamed: LD7.1 (K_1), RN3.7 (R2.2)
unnamed: LD8.1 (K_1), RN4.5 (R4.2)
unnamed: LD9.1 (K_1), RN3.6 (R3.2)
unnamed: LD10.1 (K_1), RN4.6 (R3.2)
unnamed: LD11.1 (K_1), RN3.5 (R4.2)
unnamed: LD12.1 (K_1), RN4.7 (R2.2)
unnamed: LD13.1 (K_1), RN4.8 (R1.2)
VCC: CP5.1, CP6.1, CP7.1, IC5.20 (VCC), IC6.20 (VCC), IC7.3 (~LT), IC7.4 (~BI), IC7.16 (Vdd), SW1.5, SW1.6, SW1.7, SW1.8, SW2.2; also elsewhere on the board

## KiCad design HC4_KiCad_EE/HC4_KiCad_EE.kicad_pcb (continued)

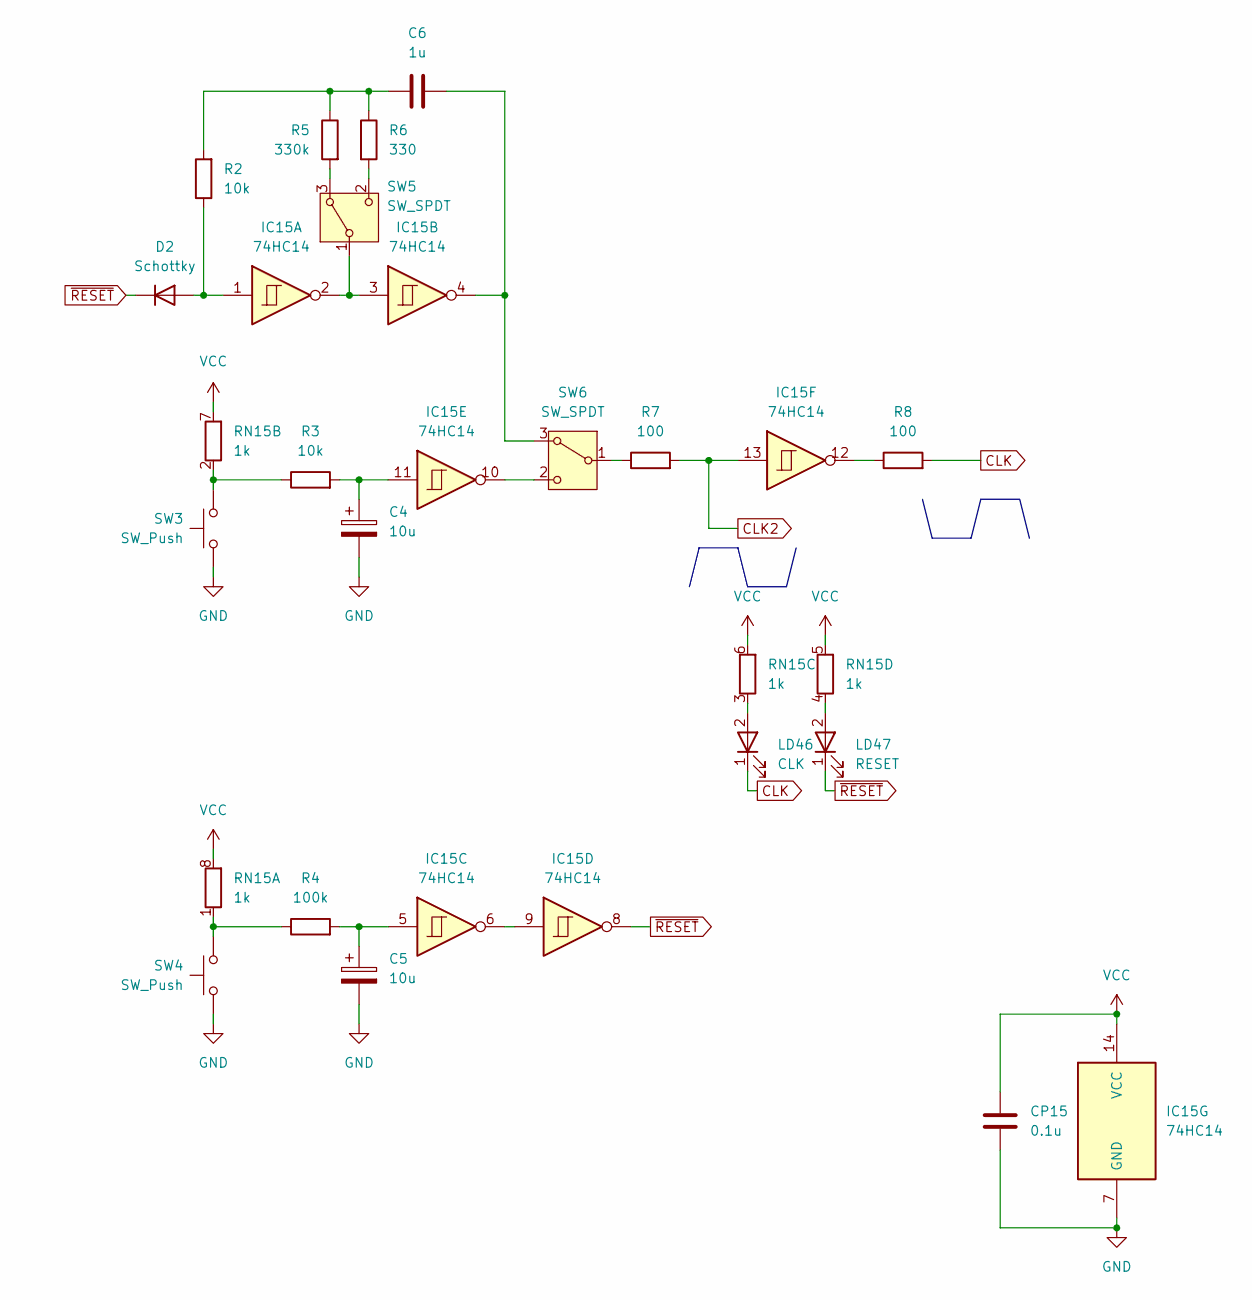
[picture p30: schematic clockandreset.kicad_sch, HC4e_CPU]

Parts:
C4, C5: 10u; CP_Radial_D5.0mm_P2.50mm
C6: 1u; C_Radial_D5.0mm_H5.0mm_P2.00mm
CP15: 0.1u; C_0603_1608Metric; LCSC PN C14663
D2: Schottky; D_SOD-323_HandSoldering
IC15: 74HC14; SO-14_5.3x10.2mm_P1.27mm
LD46: CLK; LED_D5.0mm
LD47: RESET; LED_D5.0mm
R2, R3: 10k; R_0603_1608Metric; LCSC PN C25804
R4: 100k; R_0603_1608Metric; LCSC PN C25803
R5: 330k; R_0603_1608Metric; LCSC PN C23137
R6: 330; R_0603_1608Metric; LCSC PN C23151
R7, R8: 100; R_0603_1608Metric; LCSC PN C22775
RN15: 1k; R_Array_Convex_4x0603; LCSC PN C20197
SW3, SW4: SW_Push; SW_PUSH_6mm
SW5, SW6: SW_SPDT; SW_Slide-03_Wuerth-WS-SLTV_10x2.5x6.4_P2.54mm

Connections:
CLK: LD46.1 (K_1), R8.2; also elsewhere on the board
CLK2: IC15.13, R7.2; also elsewhere on the board
GND: C4.2, C5.2, CP15.2, IC15.7 (GND), SW3.1, SW4.1; also elsewhere on the board
unnamed: C4.1, IC15.11, R3.2
unnamed: C5.1, IC15.5, R4.2
unnamed: C6.1, R2.2, R5.1, R6.1
unnamed: D2.2 (A), IC15.1, R2.1
unnamed: IC15.6, IC15.9
unnamed: IC15.12, R8.1
unnamed: R4.1, RN15.1 (R1.1), SW4.2
unnamed: R3.1, RN15.2 (R2.1), SW3.2
unnamed: LD46.2, RN15.3 (R3.1)
unnamed: LD47.2, RN15.4 (R4.1)
unnamed: R5.2, SW5.3 (A)
unnamed: IC15.2, IC15.3, SW5.1 (B)
unnamed: R6.2, SW5.2 (C)
unnamed: C6.2, IC15.4, SW6.3 (A)
unnamed: R7.1, SW6.1 (B)
unnamed: IC15.10, SW6.2 (C)
VCC: CP15.1, IC15.14 (VCC), RN15.5 (R4.2), RN15.6 (R3.2), RN15.7 (R2.2), RN15.8 (R1.2); also elsewhere on the board
~RESET: D2.1 (K), IC15.8, LD47.1 (K_1); also elsewhere on the board

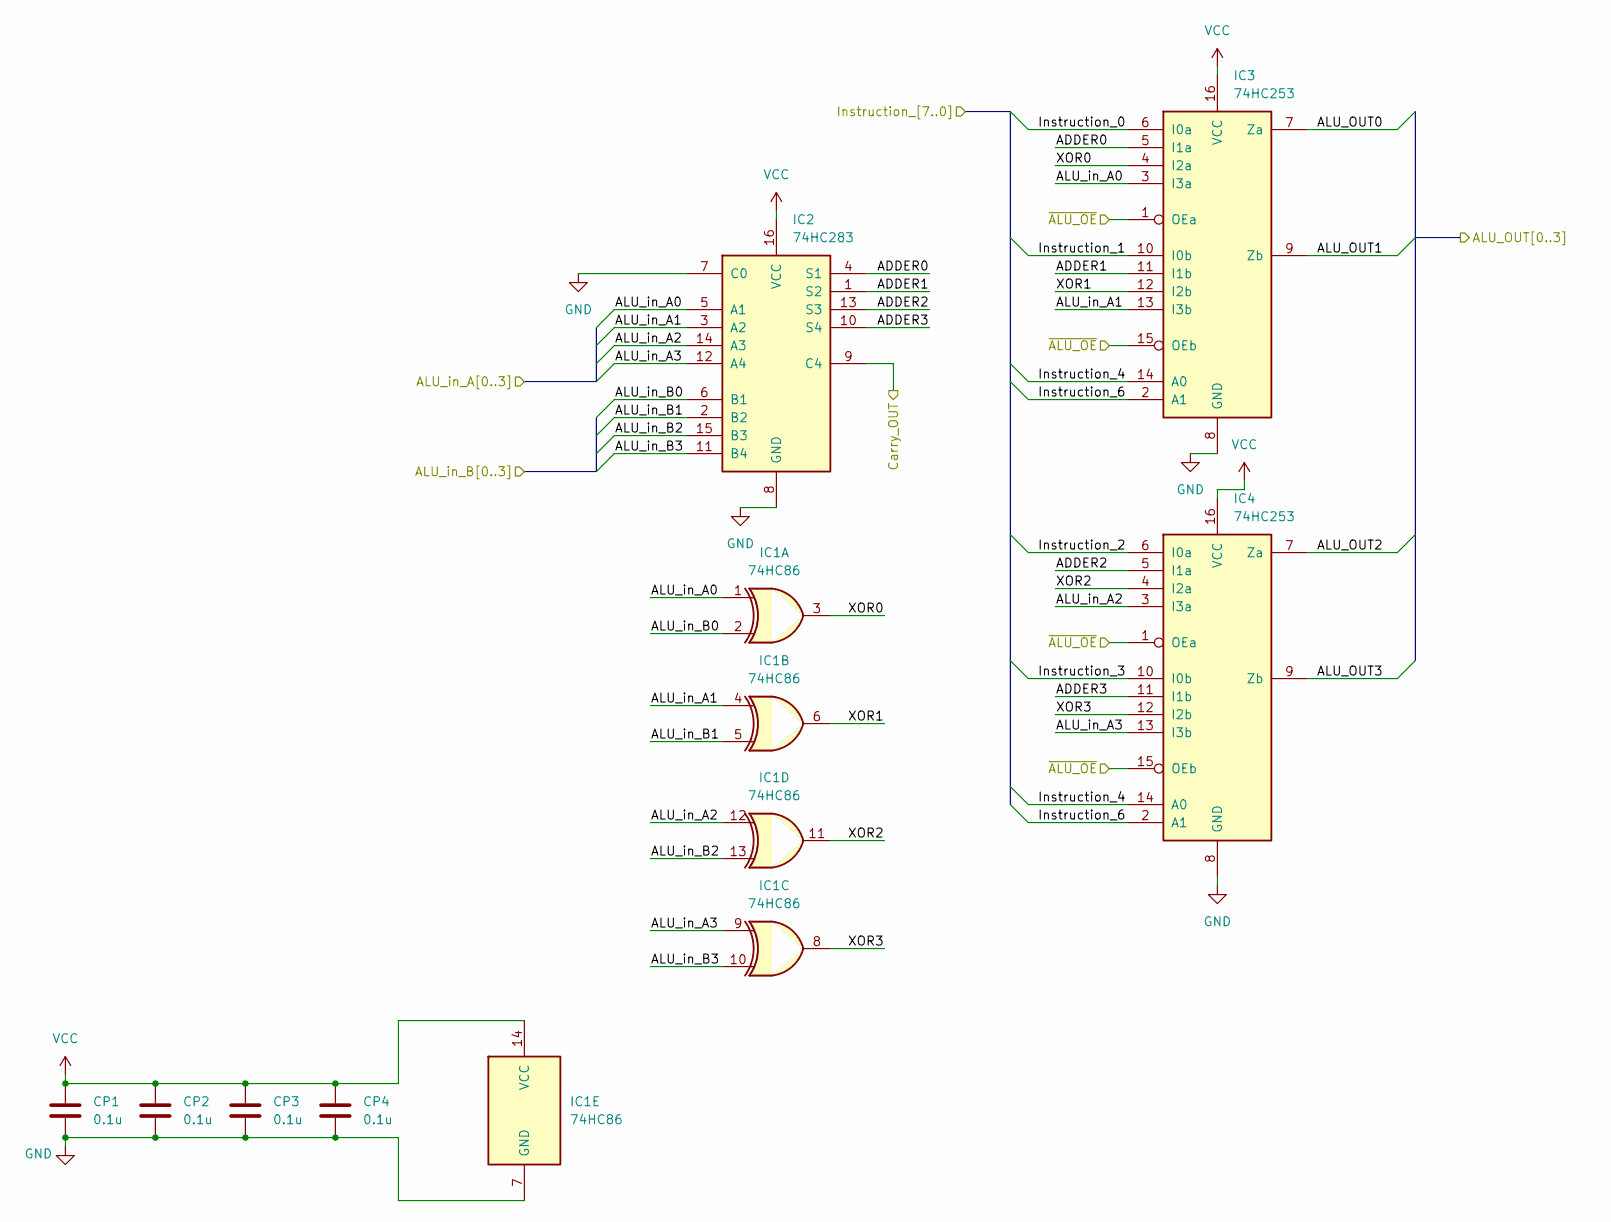
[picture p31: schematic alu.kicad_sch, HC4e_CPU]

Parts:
CP1, CP2, CP3, CP4: 0.1u; C_0603_1608Metric; LCSC PN C14663
IC1: 74HC86; SO-14_5.3x10.2mm_P1.27mm
IC2: 74HC283; SO-16_5.3x10.2mm_P1.27mm
IC3, IC4: 74HC253; SO-16_5.3x10.2mm_P1.27mm

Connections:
/ALU/ADDER0: IC2.4 (S1), IC3.5 (I1a)
/ALU/ADDER1: IC2.1 (S2), IC3.11 (I1b)
/ALU/ADDER2: IC2.13 (S3), IC4.5 (I1a)
/ALU/ADDER3: IC2.10 (S4), IC4.11 (I1b)
/ALU/ALU_OUT0: IC3.7 (Za); also elsewhere on the board
/ALU/ALU_OUT1: IC3.9 (Zb); also elsewhere on the board
/ALU/ALU_OUT2: IC4.7 (Za); also elsewhere on the board
/ALU/ALU_OUT3: IC4.9 (Zb); also elsewhere on the board
/ALU/ALU_in_A0: IC1.1, IC2.5 (A1), IC3.3 (I3a); also elsewhere on the board
/ALU/ALU_in_A1: IC1.4, IC2.3 (A2), IC3.13 (I3b); also elsewhere on the board
/ALU/ALU_in_A2: IC1.12, IC2.14 (A3), IC4.3 (I3a); also elsewhere on the board
/ALU/ALU_in_A3: IC1.9, IC2.12 (A4), IC4.13 (I3b); also elsewhere on the board
/ALU/ALU_in_B0: IC1.2, IC2.6 (B1); also elsewhere on the board
/ALU/ALU_in_B1: IC1.5, IC2.2 (B2); also elsewhere on the board
/ALU/ALU_in_B2: IC1.13, IC2.15 (B3); also elsewhere on the board
/ALU/ALU_in_B3: IC1.10, IC2.11 (B4); also elsewhere on the board
/ALU/Carry_OUT: IC2.9 (C4); also elsewhere on the board
/ALU/Instruction_4: IC3.14 (A0), IC4.14 (A0); also elsewhere on the board
/ALU/Instruction_6: IC3.2 (A1), IC4.2 (A1); also elsewhere on the board
/ALU/XOR0: IC1.3, IC3.4 (I2a)
/ALU/XOR1: IC1.6, IC3.12 (I2b)
/ALU/XOR2: IC1.11, IC4.4 (I2a)
/ALU/XOR3: IC1.8, IC4.12 (I2b)
/Instruction Decoder/READ: IC3.1 (OEa), IC3.15 (OEb), IC4.1 (OEa), IC4.15 (OEb); also elsewhere on the board
GND: CP1.2, CP2.2, CP3.2, CP4.2, IC1.7 (GND), IC2.7 (C0), IC2.8 (GND), IC3.8 (GND), IC4.8 (GND); also elsewhere on the board
VCC: CP1.1, CP2.1, CP3.1, CP4.1, IC1.14 (VCC), IC2.16 (VCC), IC3.16 (VCC), IC4.16 (VCC); also elsewhere on the board

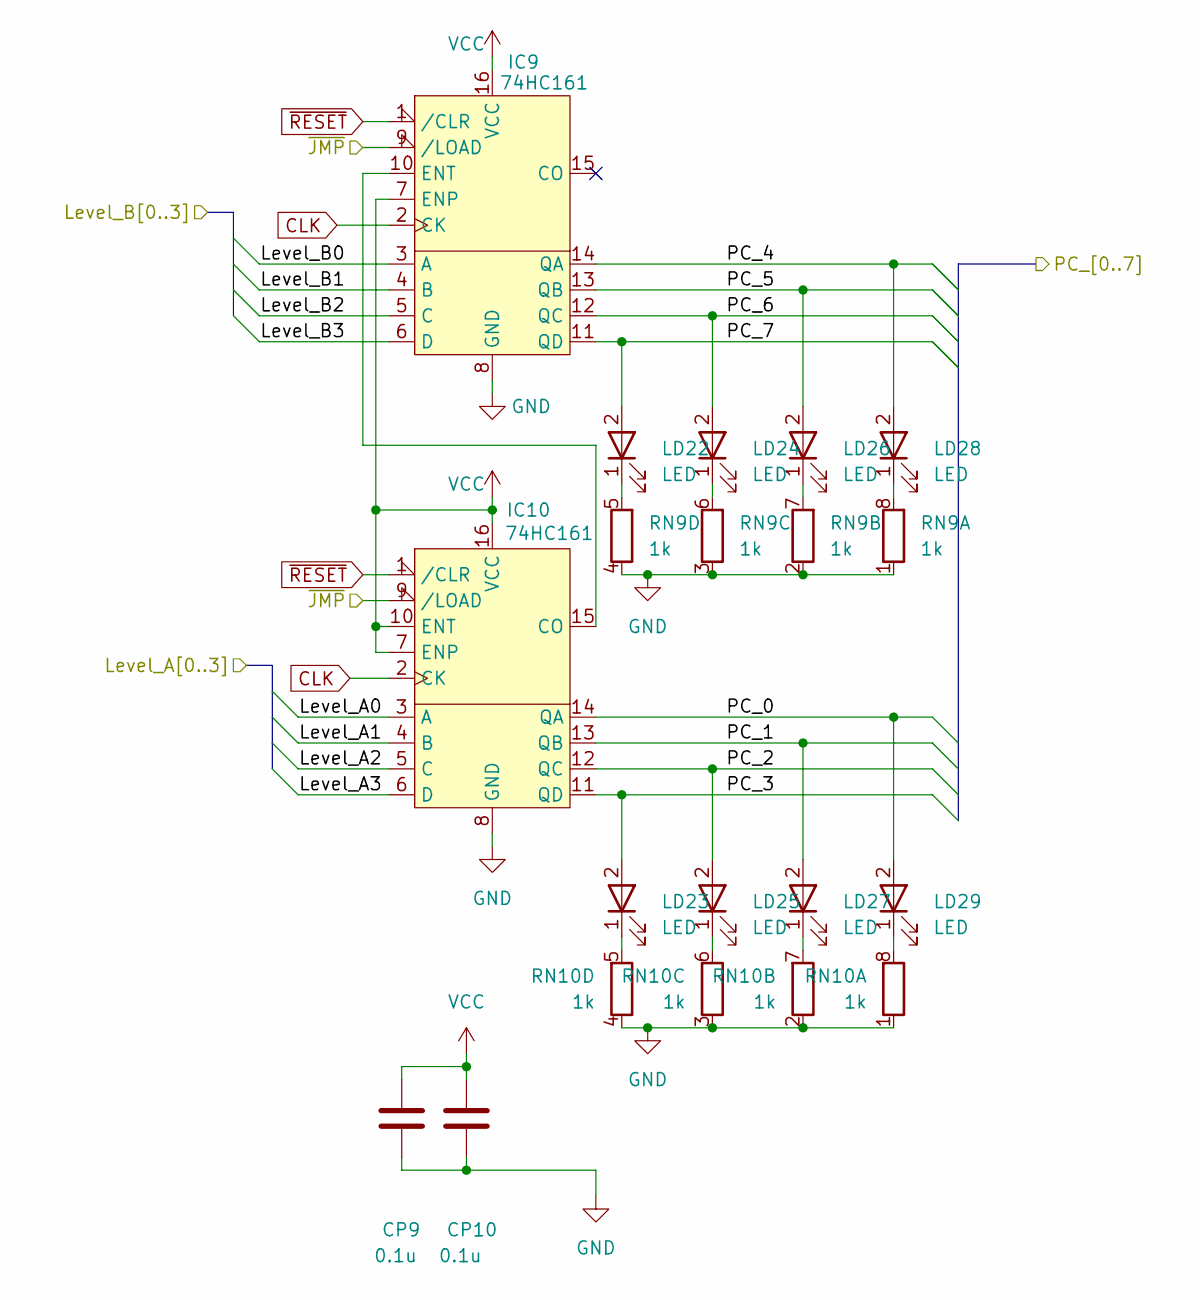
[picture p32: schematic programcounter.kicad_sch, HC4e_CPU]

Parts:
CP9, CP10: 0.1u; C_0603_1608Metric; LCSC PN C14663
IC9, IC10: 74HC161; SO-16_5.3x10.2mm_P1.27mm
LD22, LD23, LD24, LD25, LD26, LD27, LD28, LD29: LED; LED_Rectangular_W5.0mm_H2.0mm
RN9, RN10: 1k; R_Array_Convex_4x0603; LCSC PN C20197

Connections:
/ALU/ALU_in_A0: IC10.3 (A); also elsewhere on the board
/ALU/ALU_in_A1: IC10.4 (B); also elsewhere on the board
/ALU/ALU_in_A2: IC10.5 (C); also elsewhere on the board
/ALU/ALU_in_A3: IC10.6 (D); also elsewhere on the board
/ALU/ALU_in_B0: IC9.3 (A); also elsewhere on the board
/ALU/ALU_in_B1: IC9.4 (B); also elsewhere on the board
/ALU/ALU_in_B2: IC9.5 (C); also elsewhere on the board
/ALU/ALU_in_B3: IC9.6 (D); also elsewhere on the board
/Instruction Decoder/~JMP: IC9.9 (/LOAD), IC10.9 (/LOAD); also elsewhere on the board
/Program Counter/PC_0: IC10.14 (QA), LD29.2; also elsewhere on the board
/Program Counter/PC_1: IC10.13 (QB), LD27.2; also elsewhere on the board
/Program Counter/PC_2: IC10.12 (QC), LD25.2; also elsewhere on the board
/Program Counter/PC_3: IC10.11 (QD), LD23.2; also elsewhere on the board
/Program Counter/PC_4: IC9.14 (QA), LD28.2; also elsewhere on the board
/Program Counter/PC_5: IC9.13 (QB), LD26.2; also elsewhere on the board
/Program Counter/PC_6: IC9.12 (QC), LD24.2; also elsewhere on the board
/Program Counter/PC_7: IC9.11 (QD), LD22.2; also elsewhere on the board
CLK: IC9.2 (CK), IC10.2 (CK); also elsewhere on the board
GND: CP9.2, CP10.2, IC9.8 (GND), IC10.8 (GND), RN9.1 (R1.1), RN9.2 (R2.1), RN9.3 (R3.1), RN9.4 (R4.1), RN10.1 (R1.1), RN10.2 (R2.1), RN10.3 (R3.1), RN10.4 (R4.1); also elsewhere on the board
unnamed: IC9.10 (ENT), IC10.15 (CO)
unnamed: LD22.1 (K_1), RN9.5 (R4.2)
unnamed: LD23.1 (K_1), RN10.5 (R4.2)
unnamed: LD24.1 (K_1), RN9.6 (R3.2)
unnamed: LD25.1 (K_1), RN10.6 (R3.2)
unnamed: LD26.1 (K_1), RN9.7 (R2.2)
unnamed: LD27.1 (K_1), RN10.7 (R2.2)
unnamed: LD28.1 (K_1), RN9.8 (R1.2)
unnamed: LD29.1 (K_1), RN10.8 (R1.2)
VCC: CP9.1, CP10.1, IC9.7 (ENP), IC9.16 (VCC), IC10.7 (ENP), IC10.10 (ENT), IC10.16 (VCC); also elsewhere on the board
~RESET: IC9.1 (/CLR), IC10.1 (/CLR); also elsewhere on the board

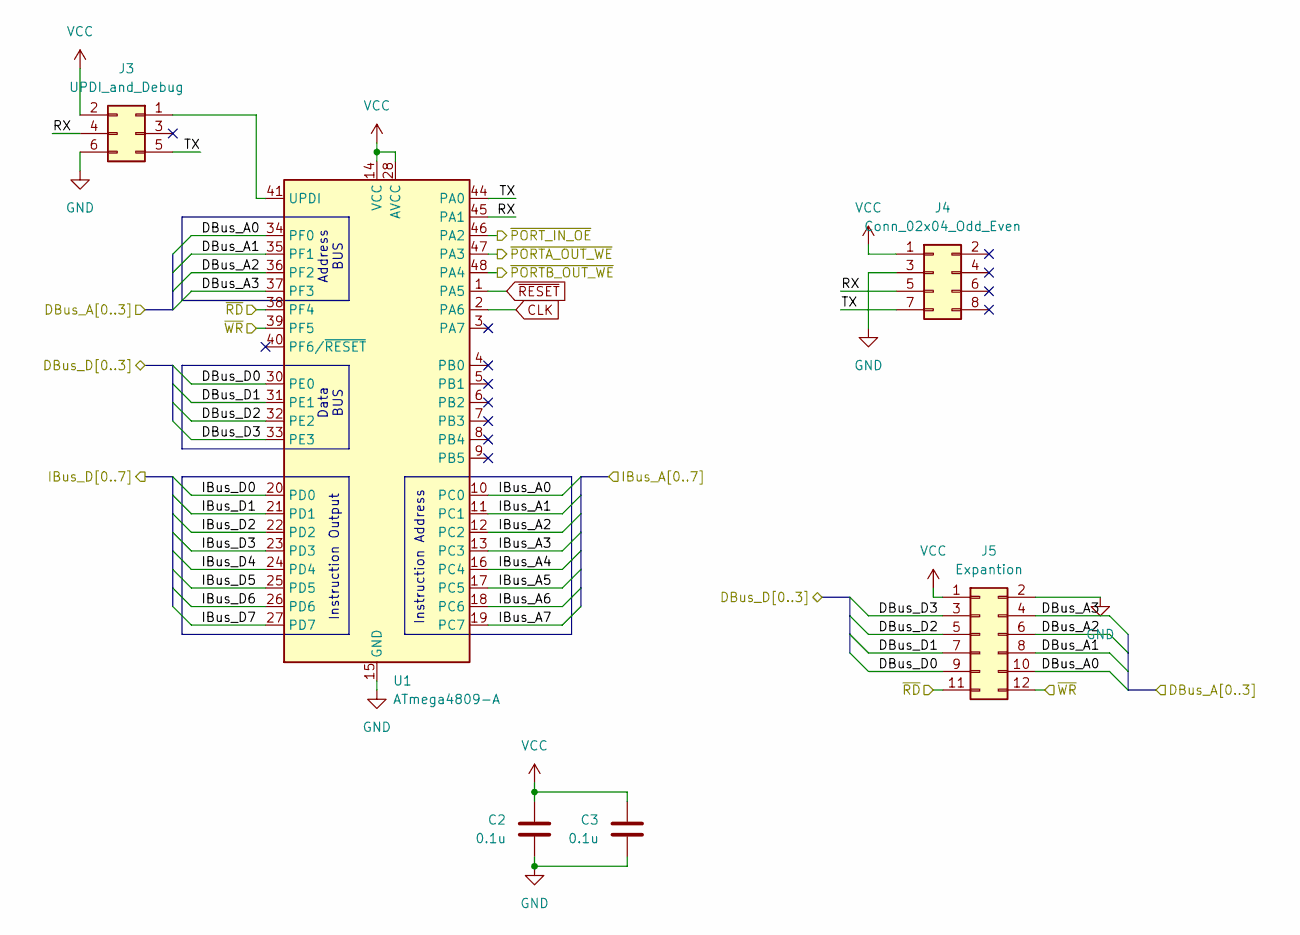
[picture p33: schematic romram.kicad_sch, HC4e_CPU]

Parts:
C2, C3: 0.1u; C_0603_1608Metric; LCSC PN C14663
J3: UPDI_and_Debug; PinHeader_2x03_P2.54mm_Vertical
J4: Conn_02x04_Odd_Even; PinHeader_2x04_P2.54mm_Vertical
J5: Expantion; PinHeader_2x06_P2.54mm_Vertical
U1: ATmega4809-A; TQFP-48_7x7mm_P0.5mm; LCSC PN C1340574

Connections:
/ALU/ALU_OUT0: J5.9, U1.30 (PE0); also elsewhere on the board
/ALU/ALU_OUT1: J5.7, U1.31 (PE1); also elsewhere on the board
/ALU/ALU_OUT2: J5.5, U1.32 (PE2); also elsewhere on the board
/ALU/ALU_OUT3: J5.3, U1.33 (PE3); also elsewhere on the board
/ALU/Instruction_4: U1.24 (PD4); also elsewhere on the board
/ALU/Instruction_5: U1.25 (PD5); also elsewhere on the board
/ALU/Instruction_6: U1.26 (PD6); also elsewhere on the board
/ALU/Instruction_7: U1.27 (PD7); also elsewhere on the board
/Data BUS/~IN_PORT_OE: U1.46 (PA2); also elsewhere on the board
/Data BUS/~PORTA_OUT_WE: U1.47 (PA3); also elsewhere on the board
/Data BUS/~PORTB_OUT_WE: U1.48 (PA4); also elsewhere on the board
/Instruction Decoder/~RAM_RD: J5.11, U1.38 (PF4); also elsewhere on the board
/Instruction Decoder/~RAM_WR: J5.12, U1.39 (PF5); also elsewhere on the board
/Program Counter/PC_0: U1.10 (PC0); also elsewhere on the board
/Program Counter/PC_1: U1.11 (PC1); also elsewhere on the board
/Program Counter/PC_2: U1.12 (PC2); also elsewhere on the board
/Program Counter/PC_3: U1.13 (PC3); also elsewhere on the board
/Program Counter/PC_4: U1.16 (PC4); also elsewhere on the board
/Program Counter/PC_5: U1.17 (PC5); also elsewhere on the board
/Program Counter/PC_6: U1.18 (PC6); also elsewhere on the board
/Program Counter/PC_7: U1.19 (PC7); also elsewhere on the board
/ROM_RAM/RX: J3.4, J4.5, U1.45 (PA1)
/ROM_RAM/TX: J3.5, J4.7, U1.44 (PA0)
CLK: U1.2 (PA6); also elsewhere on the board
GND: C2.2, C3.2, J3.6, J4.3, J5.2, U1.15 (GND), U1.29 (GND), U1.43 (GND); also elsewhere on the board
unnamed: J3.1, U1.41 (UPDI)
VCC: C2.1, C3.1, J3.2, J4.1, J5.1, U1.14 (VCC), U1.28 (AVCC), U1.42 (VCC); also elsewhere on the board
~RESET: U1.1 (PA5); also elsewhere on the board

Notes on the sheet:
Data BUS
Instruction Address
Instruction Output
Address BUS

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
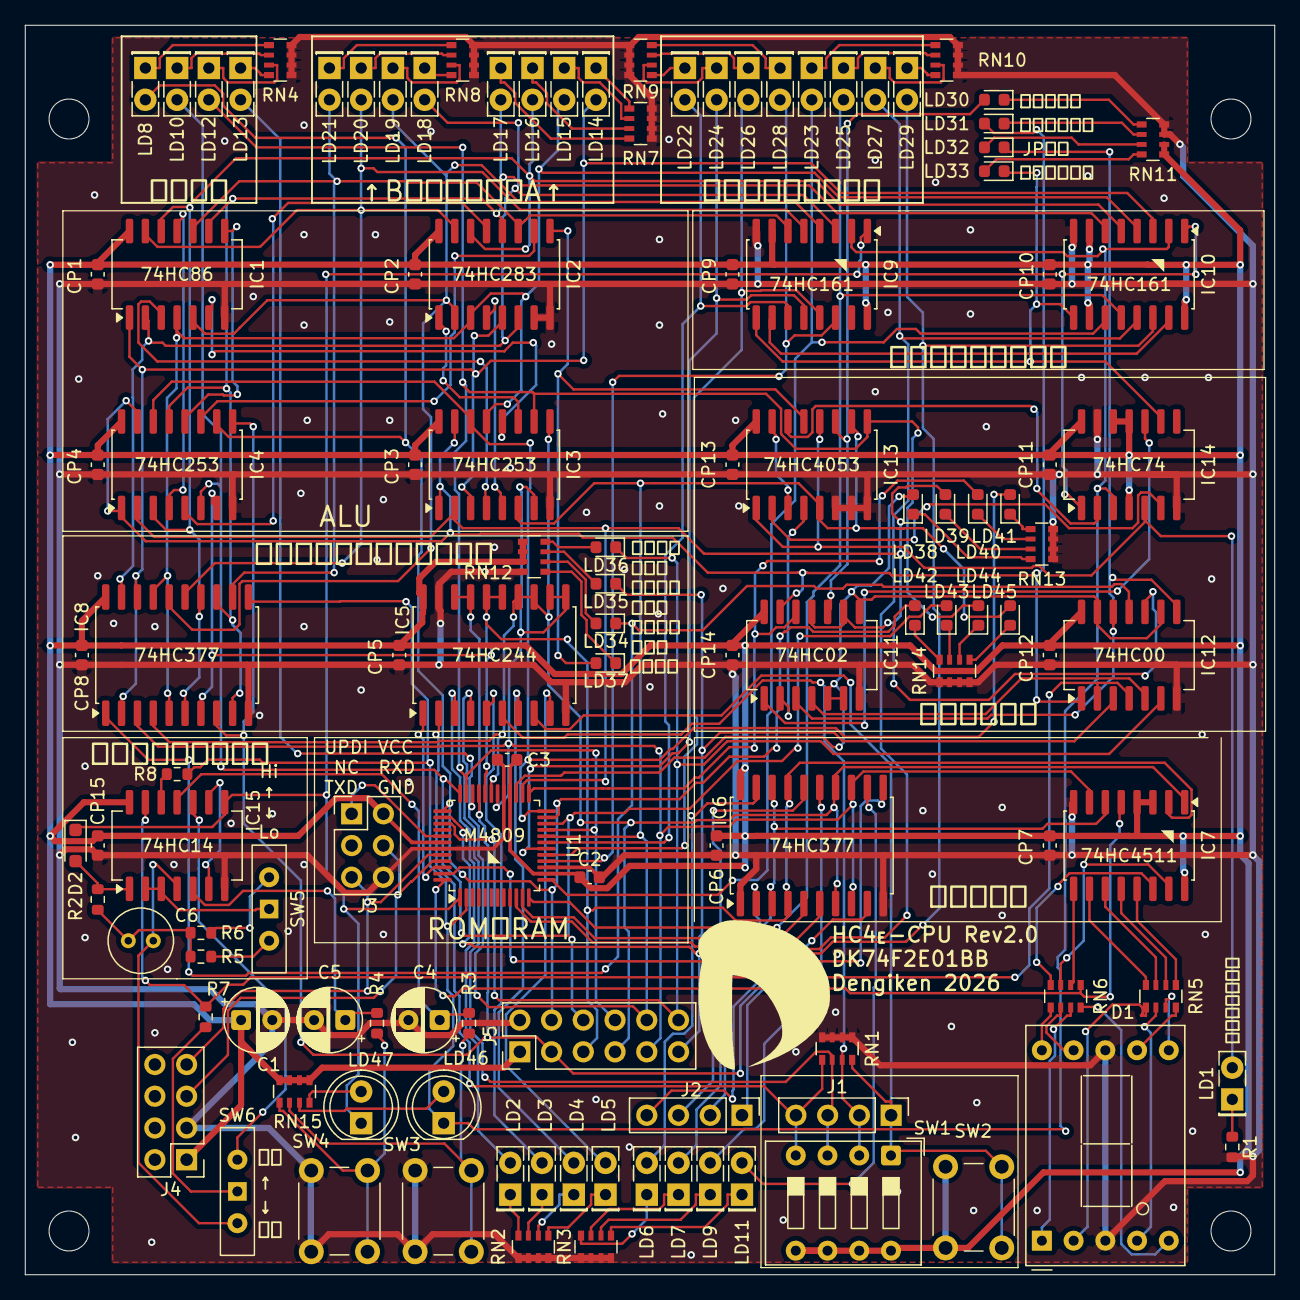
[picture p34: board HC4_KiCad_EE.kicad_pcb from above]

Board: 2 copper layers, 100.0 x 100.0 mm, 124 parts (0 on the bottom side), 155 nets.

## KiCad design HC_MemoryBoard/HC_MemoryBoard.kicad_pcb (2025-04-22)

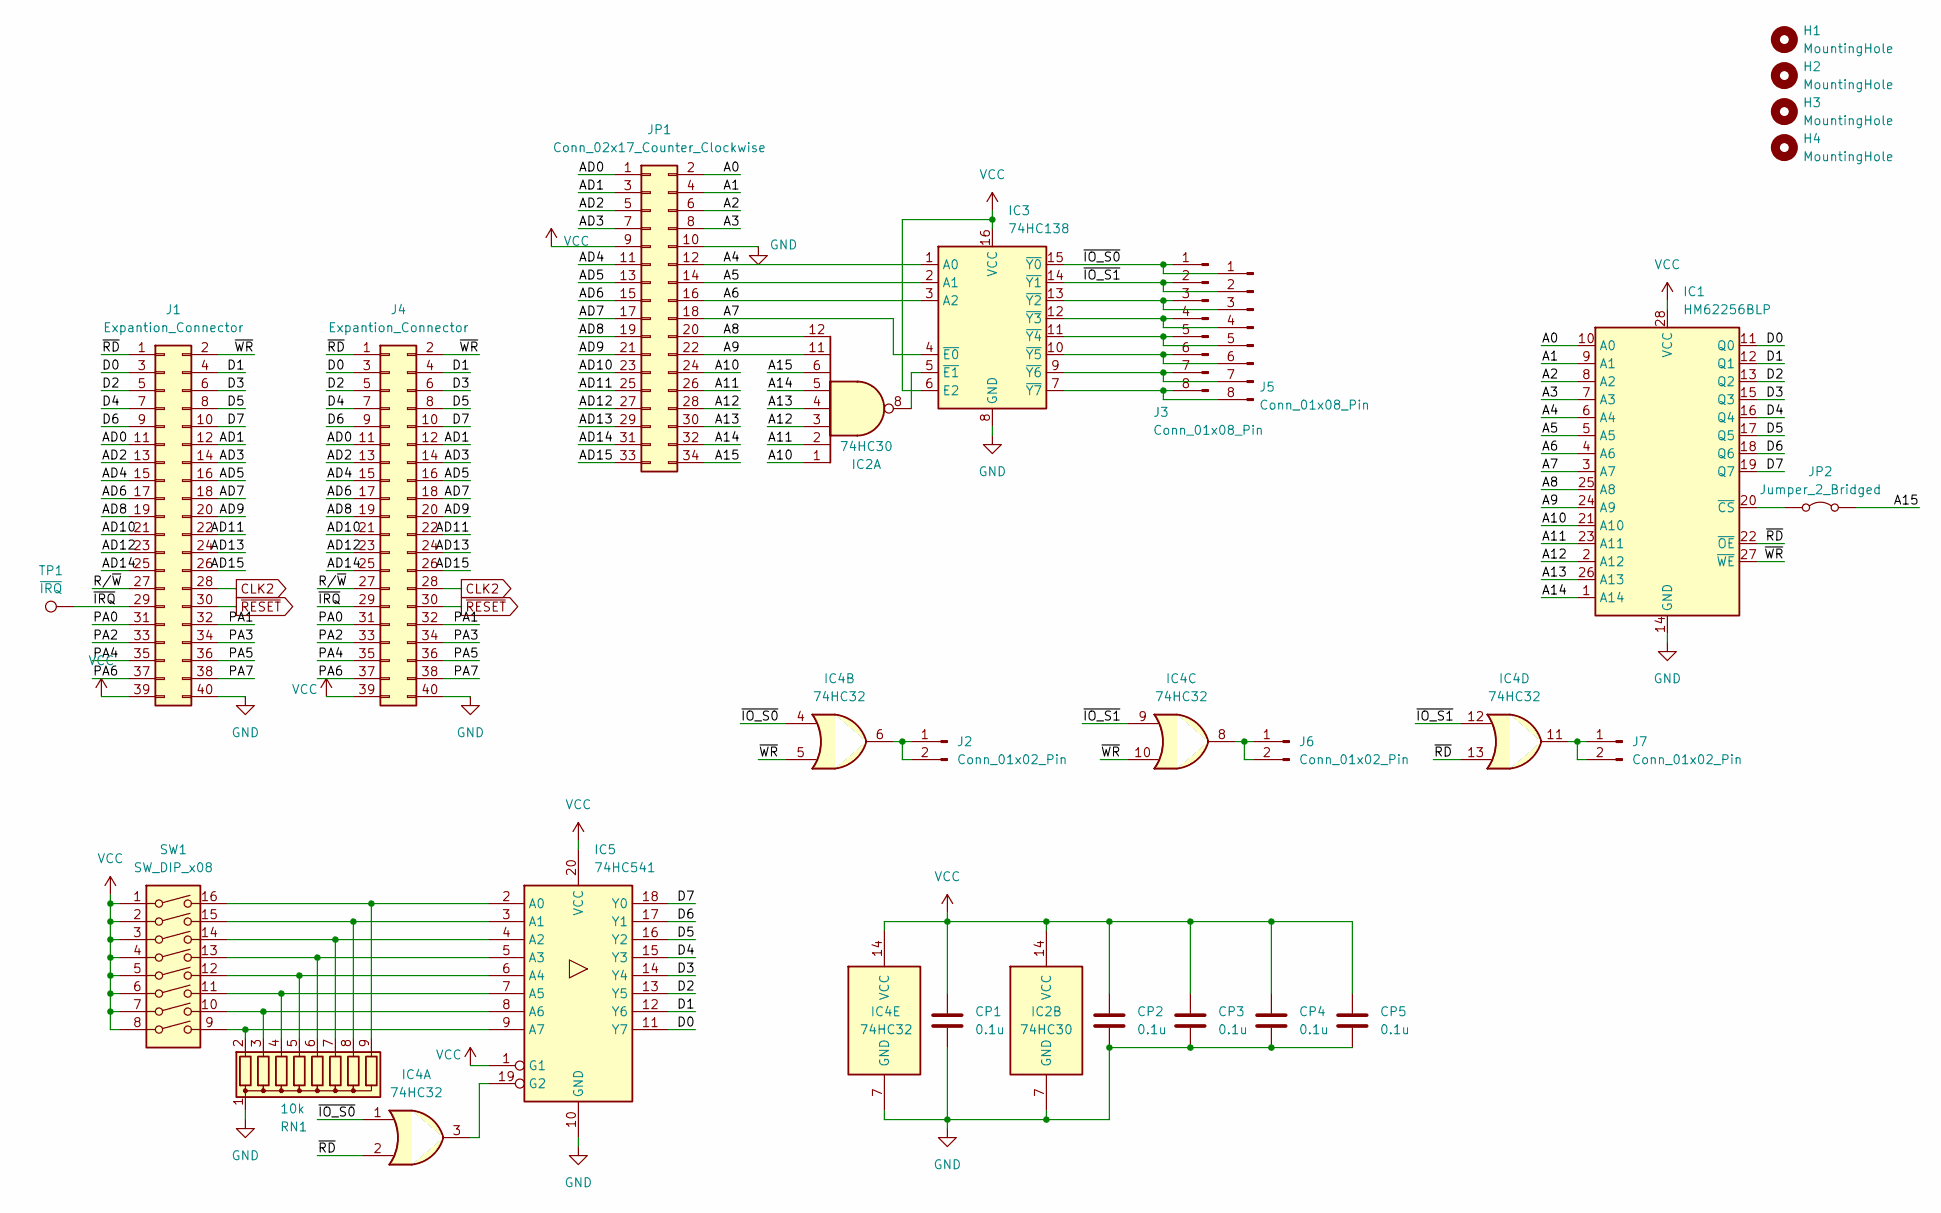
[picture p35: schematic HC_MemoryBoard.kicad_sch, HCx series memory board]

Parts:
CP1, CP2, CP3, CP4, CP5: 0.1u; C_Disc_D3.0mm_W1.6mm_P2.50mm
H1, H2, H3, H4: MountingHole; MountingHole_3.2mm_M3
IC1: HM62256BLP; DIP-28_W15.24mm
IC2: 74HC30; DIP-14_W7.62mm
IC3: 74HC138; DIP-16_W7.62mm
IC4: 74HC32; DIP-14_W7.62mm
IC5: 74HC541; DIP-20_W7.62mm
J1, J4: Expantion_Connector; PinHeader_2x20_P2.54mm_Vertical
J2, J6, J7: Conn_01x02_Pin; PinHeader_1x02_P2.54mm_Vertical
J3, J5: Conn_01x08_Pin; PinHeader_1x08_P2.54mm_Vertical
JP1: Conn_02x17_Counter_Clockwise; PinHeader_2x17_P2.54mm_Vertical
JP2: Jumper_2_Bridged; PinHeader_1x02_P2.54mm_Vertical
RN1: 10k; R_Array_SIP9
SW1: SW_DIP_x08; SW_DIP_SPSTx08_Slide_9.78x22.5mm_W7.62mm_P2.54mm
TP1: ~{IRQ}; PinHeader_1x01_P2.54mm_Vertical

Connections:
/A0: IC1.10 (A0), JP1.2
/A1: IC1.9 (A1), JP1.4
/A2: IC1.8 (A2), JP1.6
/A3: IC1.7 (A3), JP1.8
/A4: IC1.6 (A4), IC3.1 (A0), JP1.12
/A5: IC1.5 (A5), IC3.2 (A1), JP1.14
/A6: IC1.4 (A6), IC3.3 (A2), JP1.16
/A7: IC1.3 (A7), IC3.4 (~E0), JP1.18
/A8: IC1.25 (A8), IC2.12, JP1.20
/A9: IC1.24 (A9), IC2.11, JP1.22
/A10: IC1.21 (A10), IC2.1, JP1.24
/A11: IC1.23 (A11), IC2.2, JP1.26
/A12: IC1.2 (A12), IC2.3, JP1.28
/A13: IC1.26 (A13), IC2.4, JP1.30
/A14: IC1.1 (A14), IC2.5, JP1.32
/A15: IC2.6, JP1.34, JP2.2 (B)
/AD0: J1.11, J4.11, JP1.1
/AD1: J1.12, J4.12, JP1.3
/AD2: J1.13, J4.13, JP1.5
/AD3: J1.14, J4.14, JP1.7
/AD4: J1.15, J4.15, JP1.11
/AD5: J1.16, J4.16, JP1.13
/AD6: J1.17, J4.17, JP1.15
/AD7: J1.18, J4.18, JP1.17
/AD8: J1.19, J4.19, JP1.19
/AD9: J1.20, J4.20, JP1.21
/AD10: J1.21, J4.21, JP1.23
/AD11: J1.22, J4.22, JP1.25
/AD12: J1.23, J4.23, JP1.27
/AD13: J1.24, J4.24, JP1.29
/AD14: J1.25, J4.25, JP1.31
/AD15: J1.26, J4.26, JP1.33
/D0: IC1.11 (Q0), IC5.11 (Y7), J1.3, J4.3
/D1: IC1.12 (Q1), IC5.12 (Y6), J1.4, J4.4
/D2: IC1.13 (Q2), IC5.13 (Y5), J1.5, J4.5
/D3: IC1.15 (Q3), IC5.14 (Y4), J1.6, J4.6
/D4: IC1.16 (Q4), IC5.15 (Y3), J1.7, J4.7
/D5: IC1.17 (Q5), IC5.16 (Y2), J1.8, J4.8
/D6: IC1.18 (Q6), IC5.17 (Y1), J1.9, J4.9
/D7: IC1.19 (Q7), IC5.18 (Y0), J1.10, J4.10
/PA0: J1.31, J4.31
/PA1: J1.32, J4.32
/PA2: J1.33, J4.33
/PA3: J1.34, J4.34
/PA4: J1.35, J4.35
/PA5: J1.36, J4.36
/PA6: J1.37, J4.37
/PA7: J1.38, J4.38
/R/~W: J1.27, J4.27
/~IO_S0: IC3.15 (~Y0), IC4.1, IC4.4, J3.1, J5.1
/~IO_S1: IC3.14 (~Y1), IC4.9, IC4.12, J3.2, J5.2
/~IRQ: J1.29, J4.29, TP1.1
/~RD: IC1.22 (~OE), IC4.2, IC4.13, J1.1, J4.1
/~WR: IC1.27 (~WE), IC4.5, IC4.10, J1.2, J4.2
CLK2: J1.28, J4.28
GND: CP1.2, CP2.2, CP3.2, CP4.2, CP5.2, IC1.14 (GND), IC2.7 (GND), IC3.8 (GND), IC4.7 (GND), IC5.10 (GND), J1.40, J4.40, JP1.10, RN1.1 (common)
unnamed: IC1.20 (~CS), JP2.1 (A)
unnamed: IC2.8, IC3.5 (~E1)
unnamed: IC3.13 (~Y2), J3.3, J5.3
unnamed: IC3.12 (~Y3), J3.4, J5.4
unnamed: IC3.11 (~Y4), J3.5, J5.5
unnamed: IC3.10 (~Y5), J3.6, J5.6
unnamed: IC3.9 (~Y6), J3.7, J5.7
unnamed: IC3.7 (~Y7), J3.8, J5.8
unnamed: IC5.2 (A0), RN1.9 (R8), SW1.16
unnamed: IC5.3 (A1), RN1.8 (R7), SW1.15
unnamed: IC5.4 (A2), RN1.7 (R6), SW1.14
unnamed: IC5.5 (A3), RN1.6 (R5), SW1.13
unnamed: IC5.6 (A4), RN1.5 (R4), SW1.12
unnamed: IC5.7 (A5), RN1.4 (R3), SW1.11
unnamed: IC5.8 (A6), RN1.3 (R2), SW1.10
unnamed: IC5.9 (A7), RN1.2 (R1), SW1.9
unnamed: IC4.3, IC5.19 (G2)
unnamed: IC4.6, J2.1, J2.2
unnamed: IC4.8, J6.1, J6.2
unnamed: IC4.11, J7.1, J7.2
VCC: CP1.1, CP2.1, CP3.1, CP4.1, CP5.1, IC1.28 (VCC), IC2.14 (VCC), IC3.6 (E2), IC3.16 (VCC), IC4.14 (VCC), IC5.1 (G1), IC5.20 (VCC), J1.39, J4.39, JP1.9, SW1.1, SW1.2, SW1.3, SW1.4, SW1.5, SW1.6, SW1.7, SW1.8
~RESET: J1.30, J4.30

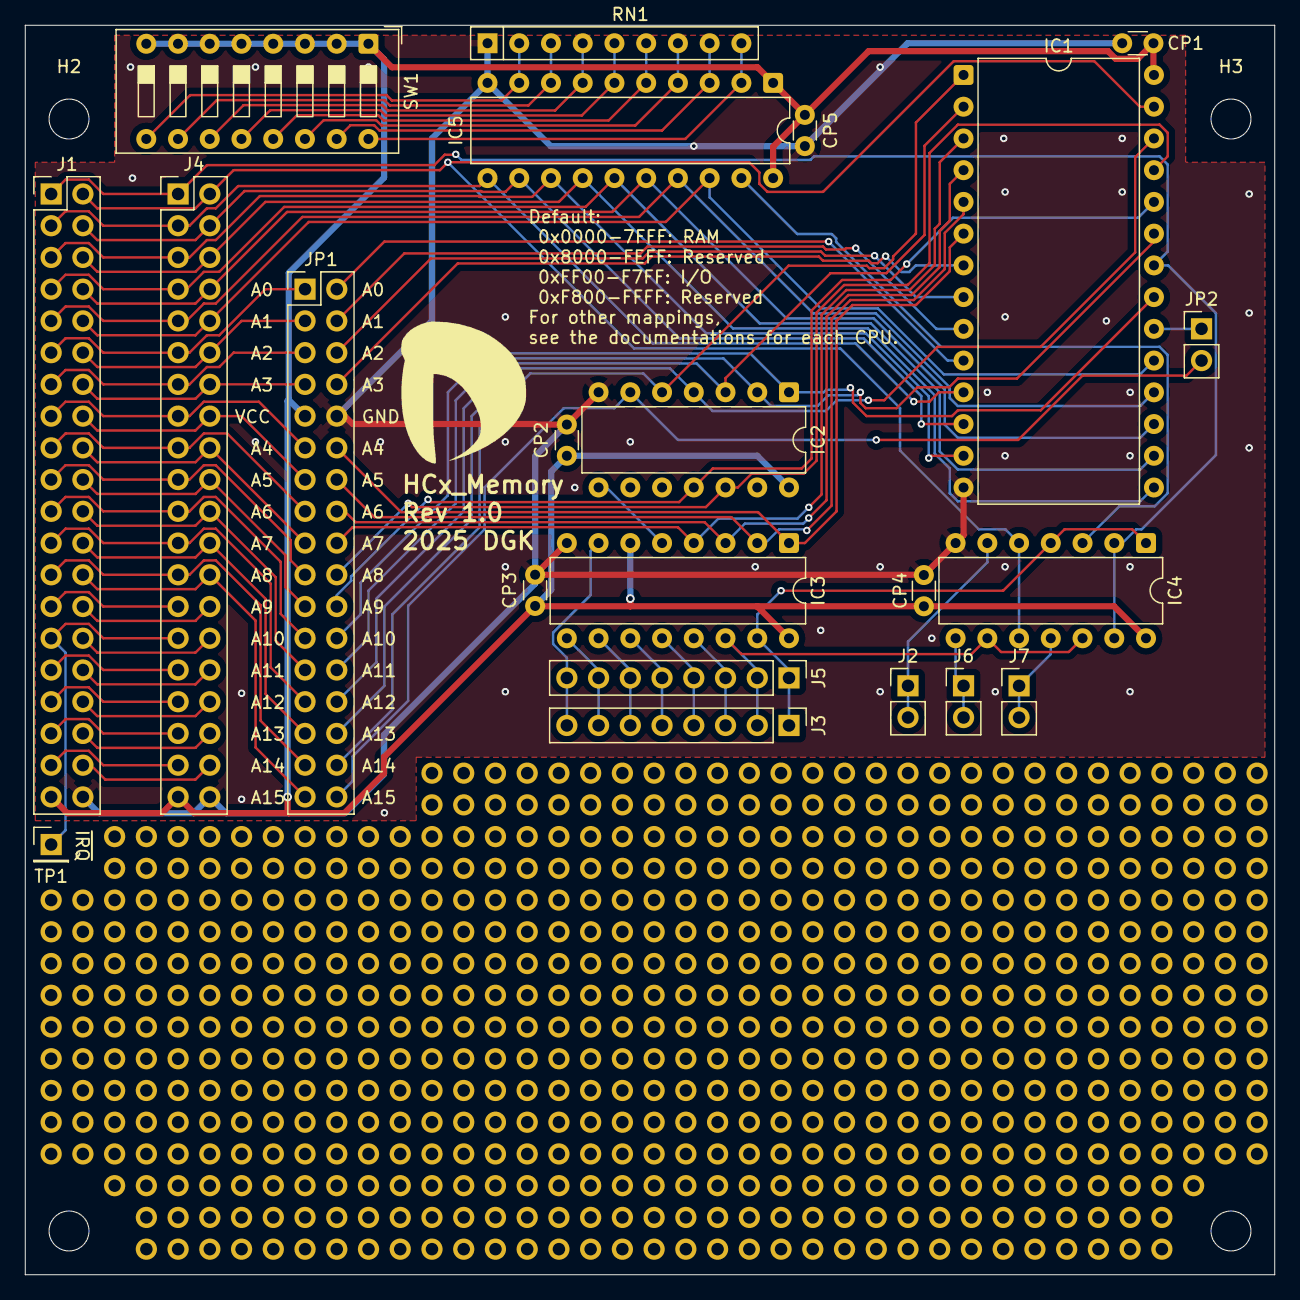
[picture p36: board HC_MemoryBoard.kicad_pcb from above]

Board: 2 copper layers, 100.0 x 100.0 mm, 26 parts (0 on the bottom side), 78 nets.

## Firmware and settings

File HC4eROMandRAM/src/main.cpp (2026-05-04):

#include <Arduino.h>

/*
 * HC4eROMandRAM.ino ── 128 B ROM (EEPROM) + 16×4‑bit RAM/I/O “三役” 完全版
 *   2025‑07‑18   Intel‑HEX 行毎即書込み版 + 小文字 l,r コマンド
 *   2025‑07‑18b  CR を無視し LF で行確定（空行 ERR 解消）
 *
 * ─── 概要 ──────────────────────────────────
 *  UART コマンド (115200‑8N1, LF)
 *    L / l  : Intel‑HEX ローダ  (1 行ずつ即 EEPROM 書込み)
 *    R / r  : 4‑bit RAM ダンプ   (16 word, comma separated)
 *
 *  内蔵 EEPROM 0‑255 を ROM 領域として読み出し、
 *  外付け 4‑bit RAM を PC2‑5, PE0‑3, PF0‑1 で制御。
 *────────────────────────────────────────────*/

#include <avr/io.h>

#include "disasm.h"
#include "hex.h"

/************* 定数 ******************************/
#define BAUD_RATE 115200

/************* Port/F ビット定義 ******************/
#define PF_nRD_bp 4
#define PF_nWR_bp 5

#define PIN_nRD PIN_PF4
#define PIN_nWR PIN_PF5

#define PA_AIN_bp 2
#define PA_AOUT_bp 3
#define PA_BOUT_bp 4

#define PIN_nPORT_OE  PIN_PA2
#define PIN_nPORTA_WE PIN_PA3
#define PIN_nPORTB_WE PIN_PA4

#define PIN_CLK PIN_PA6
#define PIN_RST PIN_PA5

/************* 4‑bit RAM/I‑O *********************/
volatile uint8_t ram4[16] = { 0 }; /* 4‑bit ×16 word */

volatile uint8_t latchedAddr = 0;
volatile uint8_t latchedData = 0;

volatile uint8_t curnWR;
volatile uint8_t curnRD;

volatile uint8_t onclkrise = 0;

// 256x8bit ROM for HC4e program
volatile uint8_t rom8[MEM_SIZE];

uint8_t ontrace = 0;

/************* 4‑bit RAM ダンプ *******************/
static void ramDump(char *args) {
  if (*args == 'h' || *args == 'H') {
    Serial.println("Usage: R");
    Serial.println(" Dumps 16x4-bit RAM contents.");
    return;
  } else if (*args == 'c' || *args == 'C') {
    for (uint8_t i = 0; i < 16; i++) {
      Serial.print(ram4[i]);
      Serial.write(',');
    }
    uint8_t pc = VPORTC.IN;
    Serial.print(pc);
    Serial.print(',');
    Serial.println(rom8[pc]);
  } else {
    Serial.println("r0  r1  r2  r3  r4  r5  r6  r7  r8  r9  r10 r11 r12 r13 r14 r15");
    for (uint8_t i = 0; i < 16; i++) {
      if (ram4[i] < 10) Serial.write(' ');
      Serial.print(ram4[i]);
      if (i == 15) {
        Serial.println();
        break;
      } else {
        Serial.write(',');
      }
      Serial.write(' ');
    }
    uint8_t pc = VPORTC.IN;
    Serial.print("PC=");
    Serial.print(pc);
    Serial.print(", Inst=");
    Serial.print(rom8[pc], HEX);
    Serial.print(" (");
    Serial.print(disasm(rom8[pc]));
    Serial.println(")");
  }
}

static void trace() {
  if (Serial.available()) {
    char c = Serial.read();
    if (c == 0x03) { // Ctrl-C
      ontrace = 0;
      Serial.print("Trace stopped.\n> ");
      return;
    }
  }
  if (onclkrise) {
    onclkrise = 0;
    ramDump("c");
  }
}

static void startTrace() {
  ontrace = 1;
  Serial.println("Trace started. (Ctrl-C to stop)");
}

static void help() {
  Serial.println("r or R : Read HC4e RAM data");
  Serial.println("l or L : Load to HC4e ROM");
  Serial.println("t or T : Trace execution (Ctrl-C to stop)");
  Serial.println("         *make sure HC4e CPU is running and in low clock mode.");
  Serial.println("h or H : Help");
}

/************* UART コマンド受付 ******************/
static void programUART() {
  static char buf[8];
  static uint8_t idx = 0;

  while (Serial.available()) {
    char c = Serial.read();
    if (0x20 <= c) Serial.write(c);
    if (c == '\r') continue; /* CR 無視 */
    if (c == '\n') {
      Serial.write('\n');
      if (idx == 0) { 
        Serial.print("> "); 
        continue; 
      } /* 連続改行は無視 */
      buf[idx] = '\0';
      char cmd = buf[0];
      char *args = &buf[1];
      while (*args == ' ') args++; /* スペーススキップ */
      if (cmd == 'l' || cmd == 'L') intelhexLoad(args);
      else if (cmd == 'r' || cmd == 'R') ramDump(args);
      else if (cmd == 't' || cmd == 'T') startTrace();
      else if (cmd == 'h' || cmd == 'H') help();
      else Serial.println("Unknown command. type 'h' for help.");
      idx = 0; /* バッファクリア */
      if (ontrace == 0) Serial.print("> ");

    } else if (idx < sizeof(buf) - 1) {
      buf[idx++] = c;
    }
  }
}

/************* Arduino 標準関数 *******************/
void setup() {
  Serial.begin(BAUD_RATE);

  /* --- RAM/I/O バス設定 --- */
  PORTF.DIR &= ~0x0F;
  PORTF.DIR &= ~((1 << PF_nRD_bp) | (1 << PF_nWR_bp));
  PORTE.DIR &= ~0x0F;  // PE0‑3 データ Hi‑Z
  PORTE.OUT &= ~0x0F;

  PORTF.DIR &= ~((1 << PF_nRD_bp) | (1 << PF_nWR_bp));
  PORTA.DIR |= (1 << PA_AIN_bp) | (1 << PA_AOUT_bp) | (1 << PA_BOUT_bp);
  VPORTA.OUT |= (1 << PA_AIN_bp) | (1 << PA_AOUT_bp) | (1 << PA_BOUT_bp);  // disable (負論理)

  /* --- PA/PD (ROM 出力) --- */
  PORTC.DIR = 0x00;  // PC 入力 (アドレス)
  PORTD.DIR = 0xFF;  // PD 出力 (データ)
  VPORTD.OUT = 0x00;

  // TCB0.CTRLB = TCB_CNTMODE_INT_gc; // 割り込みモード
  // TCB0.INTCTRL = TCB_CAPT_bm;  // 周期的割り込み許可
  // TCB0.CCMP = (F_CPU / 1000);  // 3kHz
  // TCB0.CTRLA = TCB_CLKSEL_CLKDIV1_gc | TCB_ENABLE_bm;

  PORTA.PIN6CTRL = PORT_ISC_RISING_gc;  // clk 立ち上がり
  PORTF.PIN4CTRL = PORT_ISC_FALLING_gc; // nRD 立ち下がり
  PORTF.PIN5CTRL = PORT_ISC_FALLING_gc; // nWR 立ち下がり

  Serial.println("\nHC4e ROM/RAM Monitor");
  Serial.print("> ");

  for (uint16_t i = 0; i < MEM_SIZE; i++) { // ROM配列の初期化
    rom8[i] = EEPROM.read(i);
  }

  while (1) {
    // ---- RD処理（そのままでOK）

    if (digitalReadFast(PIN_RST) == 0) { //リセット時にもROM読み出し
      uint8_t ad = VPORTC.IN;
      VPORTD.OUT = rom8[ad];
    }
    if (ontrace == 0) {
      programUART();
    } else {
      trace();
    }
    delay(10); /* CPU負荷軽減 */
  }
}


void loop() {

}

// クロック立ち上がりエッジ割り込み
// ROM読み込み, PORTA制御, RAM書込み
ISR(PORTA_PORT_vect) {
  VPORTA.OUT |= PIN4_bm | PIN2_bm | PIN3_bm; // nPORT_OE, nPORTA_WE, nPORTB_WE デアサート
  PORTA.INTFLAGS = PIN6_bm;
  VPORTE.DIR &= ~0x0F;
  onclkrise = 1;
  uint8_t a = VPORTC.IN;
  VPORTD.OUT = rom8[a];
  // VPORTD.OUT = EEPROM.read(a);
  if (curnWR == 0) {   // curnWR は割り込み直前のnWRの状態なので...
    ram4[latchedAddr] = latchedData;
    return;
  }
  return;
}

// nRD/nWR立ち下がりエッジ
ISR(PORTF_PORT_vect) {
  curnWR = digitalReadFast(PIN_nWR);
  curnRD = digitalReadFast(PIN_nRD);
  VPORTE.DIR &= ~0x0F;
  latchedAddr = VPORTF.IN & 0x0F;
  latchedData = VPORTE.IN & 0x0F;
  // /WRがLOWの間に常にラッチ（番地ズレ対策）
  if (curnWR == 0) {
    VPORTF.INTFLAGS = (1 << PF_nWR_bp);
    switch (latchedAddr) {
    case 0x0E:
      VPORTA.OUT &= ~(1 << PA_AOUT_bp);  // nPORTA_WE アサート
      break;
    case 0x0F:
      VPORTA.OUT &= ~(1 << PA_BOUT_bp);  // nPORTB_WE アサート
      break;
    default:
      break;
    }
  }
  if (curnRD == 0) { // nRDがアサートされていたら
    VPORTF.INTFLAGS = (1 << PF_nRD_bp);
    if (latchedAddr == 0x0E) {
      VPORTE.DIR &= ~0x0F;  // バスを開放
      VPORTA.OUT &= ~(1 << PA_AIN_bp);  // nPORT_OE アサート
    } else {
      VPORTE.DIR |= 0x0F;
      VPORTE.OUT = ram4[latchedAddr];
    }
  }
}

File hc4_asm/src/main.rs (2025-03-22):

use std::env;
use std::fs::File;
use std::io::{ BufReader, BufRead, Write, BufWriter };
use std::num::ParseIntError;
extern crate regex;
use regex::Regex;

extern crate getopts;
use getopts::Options;

extern crate colored; // not needed in Rust 2018+
use colored::Colorize;


//NOTE:This table DON'T INCLUDE NP INSTRUCTION
const INSTRUCTION_STRINGS: [&str;10] = ["sc", "xr", "ld", "or", "su", "an", "jp", "ad", "sa","np"];

const COMMENT_STR: &str = r"(?:;.*)?$";

//命令文と、代に引数をキャプチャする正規表現の文字列の配列
const INSTRUCTION_MATRIX_DATA: [&str; 16] = {
    const JP_DATA: &str = r"^(jp|np)(?:\s(c|nc|z|nz))?(?:\s\[abc\])?";
    [
        r"^(sc)(?:\s\[ab\])?", r"^(xr)\sr(\w+)", r"^(ld)(?:\s\[ab\])?", r"^",
        r"^(sc)\sr(\w+)", r"^(or)\sr(\w+)", r"^(ld)\sr(\w+)", r"^",
        r"^(su)\sr(\w+)", r"^(an)\sr(\w+)", r"^(ld)\s#(\w+)", JP_DATA,
        r"^(ad)\sr(\w+)", r"^(sa)\sr(\w+)", r"^", r"^",
    ]
};

const _REGISTER_INSTRUCTION: [u8; 8] = [1,2,3,4,5,6,7,9,];
const _IMMEDIATE_INSTRUCTION: [u8; 1] = [10,];

const INSTRUCTION_MATRIX_DATA_X: usize = 4;
const INSTRUCTION_MATRIX_DATA_Y: usize = 4;

fn get_instruction_table() -> [String; 16] {
    let col_num = INSTRUCTION_MATRIX_DATA_X;
    let row_num = INSTRUCTION_MATRIX_DATA_Y;

    let mut result: [String; 16] = Default::default();
    for x in 0..col_num {
        for y in 0..row_num {
            result[col_num * x + y] = INSTRUCTION_MATRIX_DATA[row_num * y + x].to_string();
        }
    }
    result
}

fn parse_to_u8(input: &str) -> Result<u8, ParseIntError> {
    if input.starts_with("0x") {
        u8::from_str_radix(&input[2..], 16)
    } else if input.starts_with("0b") {
        u8::from_str_radix(&input[2..], 2)
    } else {
        input.parse::<u8>()
    }
}

fn print_usage(program: &str, opts: Options) {
    let brief = format!("Usage: {} FILE [options]", program);
    print!("{}", opts.usage(&brief));
}

#[derive(Debug,PartialEq)]
enum AsmErrors {
    NotError,
    NonexistentInstruction,
    UnexpectedSyntax,
    NonValidLiter,
    NonFlag,
}

fn main() -> Result<(), Box<dyn std::error::Error>> {
    let args: Vec<String> = env::args().collect();
    let program = args[0].clone();

    let mut opts = Options::new();
    opts.optopt("o", "", "set output file name", "NAME");
    opts.optflag("h", "help", "print this help menu");

    let matches = match opts.parse(&args[2..]) {
        Ok(m) => { m },
        Err(f)  => { panic!("{}",f.to_string())}
    };
    if matches.opt_present("h") {
        print_usage(&program, opts);
        return Ok(());
    }
    let output = match matches.opt_str("o") {
        Some(p) => p,
        None => {
            println!("please set option -o output file path");
            return Ok(());
        },
    };

    //temporary data
    let mut bin_buf: Vec<u8> = Vec::new();

    /*アセンブラそのものの構文定義。
    * ここではアルファベットによる命令と二つの引数を半角スペースで区切ることを定義。
    */
    let line_rgx: Regex = Regex::new(r"^([a-zA-Z]+)(?:\s[r#]?(\w+))?").expect("REASON");
    let _instruction_table: [Regex;16] = get_instruction_table().map(|i| Regex::new(&(i + r"\s*" + COMMENT_STR)).unwrap());
    let white_line = Regex::new(r"^\s*$").unwrap();

    let source_file_path = &args[1];
    let mut num_of_error = 0;
    let mut line_index = 0;

    let mut line_error;
    let mut is_line_interpreted;
    for line in BufReader::new(File::open(source_file_path)?).lines() {
        line_index += 1;
        let l = String::from(line?).to_lowercase(); //ファイルを読めたらすぐに小文字に変換
        if white_line.is_match(&l) { continue; }

        line_error = AsmErrors::NotError; // 一度、構文エラーとして設定
        is_line_interpreted = false; //この行が構文解釈に引っかかったことがあるか。

        for i in 0.._instruction_table.len() {
            match _instruction_table[i].captures(&l) {
                Some(caps) => { //行を解釈できた
                    is_line_interpreted = true;
                    line_error = AsmErrors::NotError; //一度 NotError にし、その後の解釈でエラーがあれば、true とする。
                    let opc: u8 = i.try_into().unwrap();
                    let opr: u8 = if i == 0b1110 { // JP または NP の場合
                        if &caps[1] == "np" { 0b0001 } //NP 構文のみ、JP命令記述ではないがJPと同じ命令 opc の bit のため例外処理を与える
                        else {
                            match caps.get(2) { 
                                Some(value) => match value.as_str() { //第二引数が存在する
                                    "c" => 0b0010,
                                    "nc" => 0b0011,
                                    "z" => 0b0100,
                                    "nz" => 0b0101,
                                    &_ => { //エラー。存在しないフラグ
                                        line_error = AsmErrors::NonFlag;
                                        0b0000
                                    },
                                }
                                None => 0b0000, //第二引数がない
                            }
                        }
                    } else { //JP ではなく、NPではない命令記述
                        match caps.get(2) {
                            Some(value) => {
                                match parse_to_u8(value.as_str()) {
                                    Ok(value) => { //文字列を数字として解釈できた場合
                                        if value < 16 { value }
                                        else {
                                            line_error = AsmErrors::NonValidLiter; //エラー。解釈できないリテラル。
                                            0b0000
                                        }
                                    },
                                    Err(_e) => { //文字列を数字として解釈できなかった場合（エラー）
                                        line_error = AsmErrors::NonValidLiter; //エラー。解釈できないリテラル。
                                        0b0000
                                    },
                                }
                            },
                            None => 0b0000
                        }
                    };
                    //バッファに追加
                    bin_buf.push(opc * 0b10000 + opr);
                },
                None => {} //この正規表現では解釈されなかった
            }
        }
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

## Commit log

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2025-01-25 add kicad files
    [HC4_KiCad.kicad_pcb, HC4_KiCad.kicad_sch]
2025-01-26 JP,NP指定部を修正
2025-01-27 add `jnc` and `jnz` instructions
    [HC4_KiCad.kicad_sch, alu.kicad_sch]
2025-01-27 細かいバグを修正
2025-01-27 マージで発生したバグを修正
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2025-02-03 進捗コミット
    [HC4_KiCad.kicad_sch, addressbus.kicad_sch, alu.kicad_sch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]
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2025-02-08 進捗コミット2
    [HC4_KiCad.kicad_sch, alu.kicad_sch, clockandreset.kicad_sch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]
2025-02-09 I'm tired. あとは任せた 頑張りたまえ
    [HC4_KiCad.kicad_sch, addressbus.kicad_sch, alu.kicad_sch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]
2025-02-12 74HCのフットプリントの指定および基板の更新
    [HC4_KiCad.kicad_pcb]
2025-02-13 回路図の修正
    [HC4_KiCad.kicad_sch, addressbus.kicad_sch, alu.kicad_sch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]
2025-02-13 ALU基板の製作途中
    [HC4_KiCad.kicad_pcb]
2025-02-13 フットプリントの割り当て修正
    [HC4_KiCad.kicad_pcb, HC4_KiCad.kicad_sch, addressbus.kicad_sch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]
2025-02-13 ALU単体の配線完了(芸術点Up)
    [HC4_KiCad.kicad_pcb]
2025-02-14 Adress Busを若干配線
    [HC4_KiCad.kicad_pcb]
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2025-02-15 Adress Bus完成(芸術点Up)
    [HC4_KiCad.kicad_pcb, instructiondecode.kicad_sch]
2025-02-15 DataBus製作途中
    [HC4_KiCad.kicad_pcb]
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2025-02-17 電源周りが詰みそう
    [HC4_KiCad.kicad_pcb]
2025-02-17 更地になった。
    [HC4_KiCad.kicad_pcb]
2025-02-17 ICの配置を再検討
    [HC4_KiCad.kicad_sch, addressbus.kicad_sch, alu.kicad_sch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]
2025-02-17 ICを再配置
    [HC4_KiCad.kicad_pcb]
2025-02-17 再配置ほぼ完了
    [HC4_KiCad.kicad_pcb, HC4_KiCad.kicad_sch, addressbus.kicad_sch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]
2025-02-20 StackLEDつけた
    [HC4_KiCad.kicad_pcb, HC4_KiCad.kicad_sch, addressbus.kicad_sch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]
2025-02-20 とりあえずIC配置確定
    [HC4_KiCad.kicad_pcb, databus.kicad_sch, instructiondecode.kicad_sch]
2025-02-21 電源配線ほぼ完了
    [HC4_KiCad.kicad_pcb, stackunit.kicad_sch]
2025-02-21 ALUとスタックの配線完了
    [HC4_KiCad.kicad_pcb]
2025-02-21 上半分の配線だいたい終わった
    [HC4_KiCad.kicad_pcb]
2025-02-22 基盤完成
    [HC4_KiCad.kicad_pcb]
2025-02-22 ガーバーとドリルを出力
    [HC4_KiCad-B_Cu.gbr, HC4_KiCad-B_Mask.gbr, HC4_KiCad-B_Paste.gbr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]
2025-02-22 基板手直し完成
    [HC4_KiCad.kicad_pcb]
2025-02-23 またも手直し
    [HC4_KiCad-B_Cu.gbl, HC4_KiCad-B_Cu.gbr, HC4_KiCad-B_Mask.gbr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]
2025-02-23 ガーバーとドリルを修正
    [HC4_KiCad-B_Cu.gbr, HC4_KiCad-B_Mask.gbr, HC4_KiCad-B_Paste.gbr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]
2025-02-23 謎の衝突が発生したのでガーバーを修正
    [HC4_KiCad-B_Cu.gbl, HC4_KiCad-B_Cu.gbr, HC4_KiCad-B_Mask.gbr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]
2025-02-23 フォルダはガラクタ置き場ではありません。以後気を付けるように。
    [HC4_KiCad-B_Cu.gbl, HC4_KiCad-B_Mask.gbs, HC4_KiCad-B_Paste.gbp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]
2025-03-09 メモリーを外に出した ガーバーを修正した
    [HC4_KiCad-B_Cu.gbl, HC4_KiCad-B_Mask.gbs, HC4_KiCad-B_Paste.gbp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]
2025-03-12 ドキュメンテーションをちょっと充実
    [stackunit.kicad_sch]
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2025-03-20 コンパイルエラー修正 #4
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2025-03-20 エラーの感知を修正 #4
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2025-03-20 JPの台に引数処理のコードを適切に修正 #4
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2025-03-20 構文エラー修正 #4
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2025-03-20 ドキュメント類の充実、verilogの小修正
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2025-03-22 2進数, 16進数, 10進数の表現のデバック用にアセンブリを修正 #11
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2025-03-22 謝ったエラー行が表示される問題を修正 #11
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2025-03-22 エラー表示の英語のスペルミスを修正 #16
2025-03-24 ドキュメントの修正、サンプルファイルの追加
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2025-03-31 回路の改良 試験は明日やる
    [HC4_KiCad.kicad_pcb, HC4_KiCad.kicad_sch, addressbus.kicad_sch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]
2025-04-03 フットプリントをSOPに変更
    [HC4_KiCad.kicad_sch, addressbus.kicad_sch, alu.kicad_sch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]
2025-04-04 Spiceのファイルを追加
    [HC4_KiCad_tb.kicad_pcb, HC4_KiCad_tb.kicad_sch, instructiondecode.kicad_sch]
2025-04-08 さようなら、爺さん
    [HC4_KiCad.kicad_pcb]
2025-04-09 Added output port for blink
    [HC4_KiCad.kicad_pcb, HC4_KiCad.kicad_sch, addressbus.kicad_sch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]
2025-04-11 部品配置完了
    [HC4_KiCad.kicad_pcb, HC4_KiCad.kicad_sch, databus.kicad_sch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]
2025-04-12 配線完了とみられる
    [HC4_KiCad.kicad_pcb, HC4_KiCad.kicad_sch, addressbus.kicad_sch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]
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2025-04-12 ガーバーファイルを出力
    [HC4_KiCad-B_Cu.gbl, HC4_KiCad-B_Mask.gbs, HC4_KiCad-B_Paste.gbp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]
2025-04-13 基板のイメージ画像出力、ラーメンタイマー修正
2025-04-19 リビジョン番号いれた
    [HC4_KiCad.kicad_pcb, HC4_KiCad.kicad_sch, addressbus.kicad_sch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]
2025-04-20 メモリーボード
    [HC_MemoryBoard.kicad_pcb, HC_MemoryBoard.kicad_sch]
2025-05-06 ミスを修正
    [HC4_KiCad.kicad_pcb, HC4_KiCad_tb.kicad_sch, databus.kicad_sch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]
2025-05-06 ガーバーがガバガバだったのを修正
    [HC4_KiCad.kicad_pcb]
2025-05-07 なんか変わってた
    [instructiondecode.kicad_sch]
2025-05-26 add HC4e files
    [HC4_KiCad_EE.kicad_pcb, HC4_KiCad_EE.kicad_sch, addressbus.kicad_sch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]
2025-05-26 仕様決め
    [HC4_KiCad_EE.kicad_sch, alu.kicad_sch]
2025-05-28 一部を整地
    [HC4_KiCad_EE.kicad_sch, addressbus.kicad_sch, databus.kicad_sch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]
2025-05-30 コミット忘れてたてへ
    [alu.kicad_sch, programcounter.kicad_sch, stackunit.kicad_sch]
2025-06-10 4809を別シートに、ほか
    [HC4_KiCad_EE.kicad_sch, alu.kicad_sch, clockandreset.kicad_sch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]
2025-06-14 完成かも～
    [HC4_KiCad_EE.kicad_sch, alu.kicad_sch, clockandreset.kicad_sch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]
2025-06-14 ドキュメントを少々
    [HC4_KiCad_EE.kicad_sch]
2025-06-14 Carry_ENを論理反転、回路図の修正
    [alu.kicad_sch, clockandreset.kicad_sch, databus.kicad_sch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]
2025-06-16 PortBを4511に、フットプリントの割り付け開始
    [HC4_KiCad_EE.kicad_sch, alu.kicad_sch, clockandreset.kicad_sch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]
2025-06-19 何故かA3になってたのをA4に変更
    [databus.kicad_sch]
2025-06-20 チップ集合抵抗に変更、基板作成開始
    [HC4_KiCad_EE.kicad_pcb, HC4_KiCad_EE.kicad_sch, alu.kicad_sch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]
2025-07-05 配線進捗、7474を使った変な回路
    [HC4_KiCad_EE.kicad_pcb, clockandreset.kicad_sch, databus.kicad_sch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]
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2025-07-12 自動配線前バックアップ
    [HC4_KiCad_EE.kicad_pcb]
2025-07-13 LEDの抵抗を入れ替え
    [programcounter.kicad_sch]
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2025-07-14 verilogを修正
2025-07-16 基板完成
    [HC4_KiCad_EE.kicad_pcb]
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2025-07-18 Intelhexで記入できるように修正 RAM部分のフローチャートはよくわからなかったけど動いてるからヨシ!
2025-07-19 振出しに戻る
    [HC4_KiCad_EE.kicad_pcb, databus.kicad_sch, stackunit.kicad_sch]
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2025-07-19 自動配線前最終チェック
    [HC4_KiCad_EE.kicad_pcb, HC4_KiCad_EE.kicad_sch, alu.kicad_sch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]
2025-07-19 自動配線できた
    [HC4_KiCad_EE.kicad_pcb]
2025-07-21 割り込み部分の条件をWRとRDに修正
2025-07-21 RAM部分のフローチャートを個人的な解釈で修正 解釈ミスあったらIssuesかディスコで教えて
2025-07-21 RD命令部のミスを修正
2025-07-22 たぶん完成！！！！！！！
    [HC4_KiCad_EE.kicad_pcb, HC4_KiCad_EE.kicad_sch, alu.kicad_sch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]
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2025-07-27 表面実装用にプログラムを修正
2025-07-30 少し修正
2025-07-31 HC4eのVerilogにI/Oを追加 プログラムのI/Oの解釈ミスを修正
2025-07-31 妥協に妥協を重ね妥協を加速する あとクロックの起動が安定しないのを直した
    [HC4_KiCad_EE.kicad_pcb, clockandreset.kicad_sch, instructiondecode.kicad_sch]
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2025-08-03 Update KiCad project files and schematic components
    - Changed active layer from 0 to 5 in HC4_KiCad_EE.kicad_prl.
    - Adjusted minimum resolved spokes from 2 to 1 and updated solder mask clearance in HC4_KiCad_EE.kicad_pro.
    - Corrected resistor value from "3.9k" to "390" in clockandreset.kicad_sch.
    - Added fabrication toolkit options JSON file for project configuration.
    - Modified LED component positions in instructiondecode.kicad_sch for better alignment.
    - Created .gitignore file in production directory to exclude unnecessary files.
    - Added HC4e_Rev01.zip to production directory for project release.
    [HC4_KiCad_EE.kicad_pcb, clockandreset.kicad_sch, instructiondecode.kicad_sch]
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2025-08-18 マージミスった
    [HC4_KiCad_EE.kicad_pcb, HC4_KiCad_EE.kicad_sch, addressbus.kicad_sch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]
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2025-08-28 HC4eの回路図pdfを修正
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2025-10-05 ブロック図を修正、ROMエミュレータのプログラムの書式整理、高速化への準備、RAM部分の処理の見直し
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2025-11-01 HC4e設計変更:CH340に敗北宣言、USBシリアル仕様に変更
    [HC4_KiCad_EE.kicad_pcb, HC4_KiCad_EE.kicad_sch, romram.kicad_sch]
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2025-12-23 RAMが動作しない問題とROMに長い命令を書き込めない問題を修正
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2025-12-28 Fix image paths in README.md for consistency
    Microsoftを許してはいけない
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2026-01-10 MOSFETを回路上より排除
    [HC4_KiCad_EE.kicad_pcb, clockandreset.kicad_sch, instructiondecode.kicad_sch]
2026-03-08 基板に反映
    [HC4_KiCad_EE.kicad_pcb, romram.kicad_sch]
2026-03-11 配線のやり直しをやり直し
    [HC4_KiCad_EE.kicad_pcb]
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2026-03-19 2.0に改版
    [HC4_KiCad_EE.kicad_pcb, HC4_KiCad_EE.kicad_sch, alu.kicad_sch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]
2026-03-20 ERC/DRCを通す
    [HC4_KiCad_EE.kicad_pcb]
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2026-04-11 disasm関数のバッファ管理を改善し、命令の処理を修正
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2026-05-02 割り込み処理を修正、ver3基板に向けてマイコン設定を追加、veriloの誤りを修正
2026-05-04 nRD/WR制御とROMの制御を分離、AVR16EA48の設定を修正
2026-05-04 基板を若干改版、フットプリントの指定が外れていたのを修正
    [HC4_KiCad_EE.kicad_pcb, alu.kicad_sch, instructiondecode.kicad_sch]
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2026-08-07 Databusのサイズ修正
    [databus.kicad_sch]
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

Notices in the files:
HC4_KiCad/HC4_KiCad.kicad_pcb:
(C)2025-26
